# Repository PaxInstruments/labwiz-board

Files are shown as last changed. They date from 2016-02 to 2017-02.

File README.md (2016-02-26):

# Pax Instruments
# armwiz-board

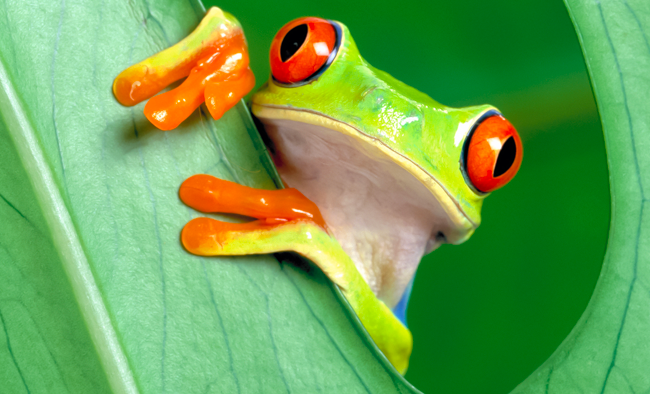
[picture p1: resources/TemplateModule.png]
  
[Pax Instruments Template Module](<link to store page>)

## Overview
The Pax Instruments armwiz board is a development board based on the STM32 series processors specifically targeting the STM32F103RxT series. You can [purchase this item in our store](http://paxinstruments.com/products/).

## Repository Contents
- __Datasheets__ - Datasheets for relevant components and parts
- __Electronics__ - All PCB and schematic design files
- __Enclosure__ - Enclosure 3D design files
- __Firmware__ - Firmware, libraries, and examples
- __Production__ - Manufacturing resources
- __Resources__ - Other resources

## Product Versions

## License Information
```
Place the license statement here
```

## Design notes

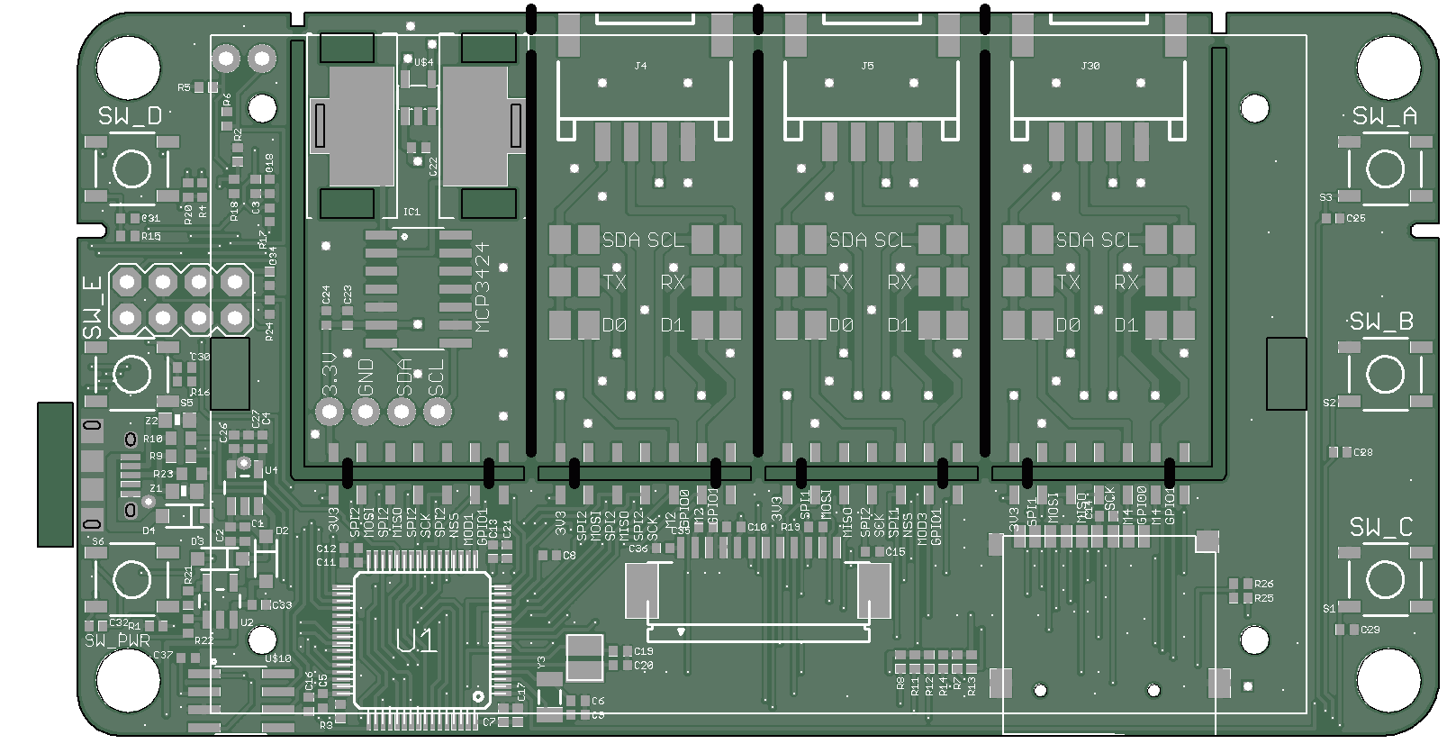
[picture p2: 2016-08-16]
electronics/versions/labwiz-board-0.2/labwiz-0.2_top.png

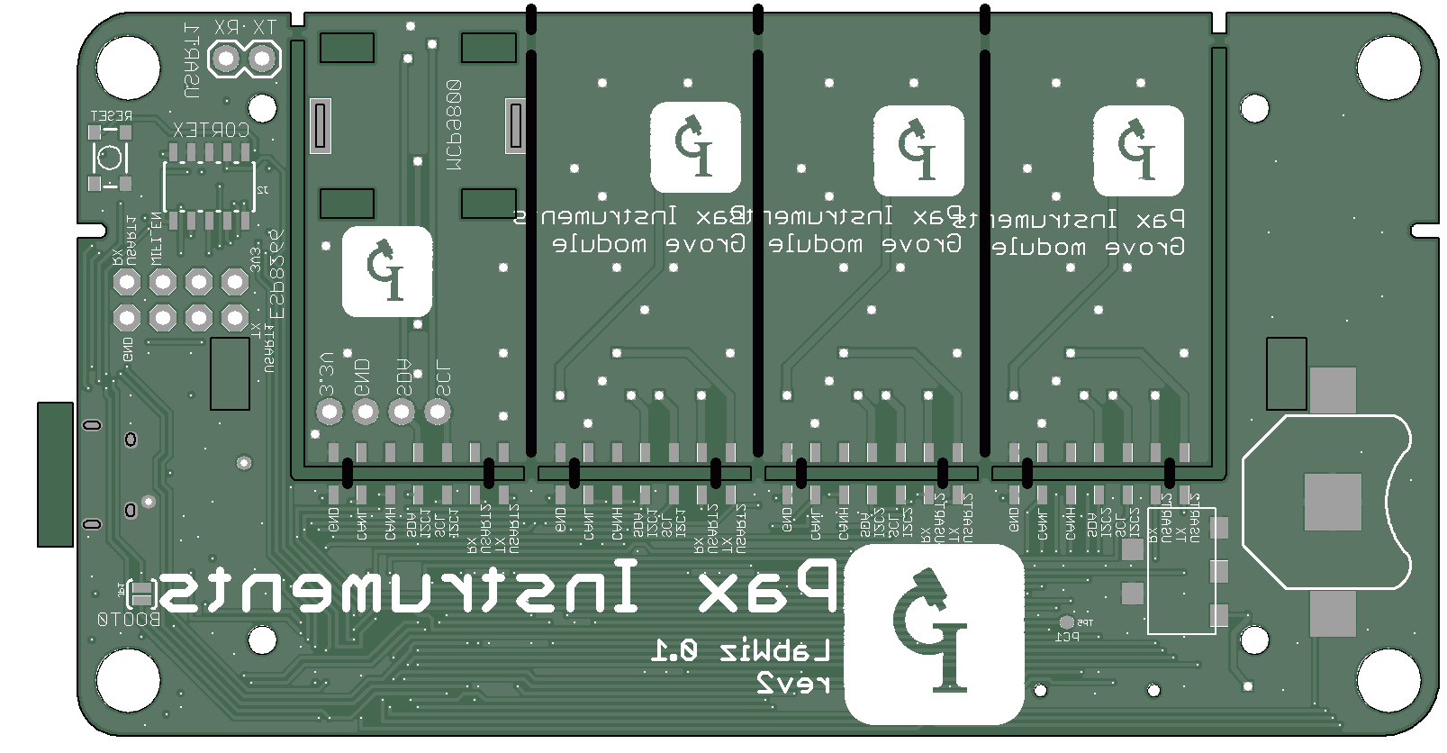
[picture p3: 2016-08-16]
electronics/versions/labwiz-board-0.2/labwiz-0.2_bottom.png

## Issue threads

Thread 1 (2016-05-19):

Voltage regulator

charlespax, 2016-05-19:
Determine which voltage regulator to use. See http://community.paxinstruments.com/t/pax-instruments-multilogger/167

charlespax, 2016-05-19:
The LM317 is suggested.
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

charlespax, 2016-08-08:
Sticking with the MIC5219-3v3

Closed 2016-08-08.

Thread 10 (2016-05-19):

Battery charging

charlespax, 2016-05-19:
Implement a solid battery charging circuit. See http://community.paxinstruments.com/t/pax-instruments-labwiz/167

charlespax, 2016-05-19:
From stmdude:

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

charlespax, 2016-05-19:
I just ripped open a BL-5C battery. Here is the internal protection PCB.
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

It contains two ICs. One is marked DW01 z, which is a battery protection IC from Fortune Semiconductor. It is probably similar to [this one](http://pdf1.alldatasheet.com/datasheet-pdf/view/256691/ETC2/DW01.html). The 8205S is a 8205A dual NFET.
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

What do you think?

charlespax, 2016-05-19:
From stmdude:

> It's a pretty basic (and adequate) protection circuit. One thing you should confirm though (you might have already done it) is to make sure that the MCP73831 actually tries to charge a little bit before trying to do a battery detect (VBAT > 0V). Otherwise, "4. Charge Detection after Overdischarge" won't work. I've been bitten by that one once before. (Not with the MCP chargers though, that was a BQ)
>
> Still, some rudimentary temperature checks would be in order (considering that people might very well put an instrument like this in a temp-chamber)

charlespax, 2016-07-24:
The Adafruit Feather boards could be a nice reference design for our battery charging system. It's fairly similar to the T400 as well. Adafruit has a [series of Feather boards](https://www.adafruit.com/categories?q=adafruit%20feather&) with different microcontrollers and various wireless options.

Below are the power and battery charging circuits for the various boards. Decoupling cap and other bits may be left out.

**Adafruit-Feather-32u4-Basic-Proto-PCB**
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

**Adafruit-Feather-32u4-Bluefruit-LE-PCB**
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

**Adafruit-Feather-32u4-FONA-PCB**
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

**Adafruit-Feather-32u4-RFM-LoRa-PCB**
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

**Adafruit-Feather-ESP8266-HUZZAH-PCB**
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

**Adafruit-Feather-M0-Adalogger-PCB**
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

**Adafruit-Feather-M0-Basic-Proto-PCB**
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

**Adafruit-Feather-M0-Bluefruit-LE-PCB**
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

**Adafruit-Feather-M0-RFM-LoRa-PCB**
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

**Adafruit-Feather-M0-WiFi-WINC1500-PCB**
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

**Adafruit-WICED-WiFi-Feather-PCB**
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

charlespax, 2016-08-08:
Here is the voltage regulator and the battery charging circuit.
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

We still need to implement switching between battery power and USB power https://github.com/PaxInstruments/labwiz-board/issues/37.

Closed 2016-08-08.

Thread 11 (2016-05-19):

Coulomb counter

charlespax, 2016-05-19:
See http://community.paxinstruments.com/t/pax-instruments-multilogger/167

charlespax, 2016-05-19:
From stmdude:

> Columb-counters are sexy beasts, but they're probably a bit overkill in this application. Approximating SoC (State of Charge) from just VBAT is enough, unless you put loads high enough on the battery for the IR to matter. (In that case, you'll get erroneously low readings when the system is under load)

charlespax, 2016-05-19:
We won't need this as long as we measure the battery voltage (#6).

Closed 2016-05-19.

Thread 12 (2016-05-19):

RTC backup power

charlespax, 2016-05-19:
The device has a coin cell battery for RTC backup. Should we use a super cap?

charlespax, 2016-05-19:
The coin cell works. Made a new issue to address the super cap idea #16.

Closed 2016-05-19.

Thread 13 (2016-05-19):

Boot configuration

charlespax, 2016-05-19:
The ARM BOOT0 and BOOT1 pin configuration determines from which memory system the MCU boots.

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

BOOT1 is not typically used and can be accessible via a solder bridge. BOOT0 is used a bit more, but does not need to be readily available. Test pads would be sufficient. There is no need for pin headers for these. BOOT0 should have a pulldown resistor.

charlespax, 2016-05-19:
BOOT1 is on a solder bridge. Boot0 is connected one of two pads that can easily be bridged together. You can see a small milled slot going through two overlapping pads. Tweezers or other metal can be used to bridge across. I haven't tried this before, so we'll see how it goes.
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

Closed 2016-05-19.

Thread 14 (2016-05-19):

Analog reference

charlespax, 2016-05-19:
What should we do with VDDA?

charlespax, 2016-05-19:
We could leave it unconnected, butI have it connected to 3.3V. It can be completely ignored. However, it someone wants to play with using an external analog reference, there is a voltage on that pin.

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

There is a good deal of space in the area near VDDA. We could add a footprint for a precision voltage reference and just leave it unpopulated.
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

electrokean, 2016-09-03:
Adding the ferrite in https://github.com/PaxInstruments/labwiz-board/issues/48 would allow someone to remove that and isolate VDDA to connect in an alternate reference.

charlespax, 2016-09-03:
I like that idea. We should probably have a ferrite bead there anyway. If there's enough room, I can also add the appropriate IC footprints on the backside of the board.

An alternative approach would be to have a voltage reference on a module board. The reference can be measured by one of the GPIO pins (they all are on an ADC) for calibration of the STM32's internal reference.

charlespax, 2016-09-09:
To keep the design simple I will not implement this. To get quality analog readings an external reference can be used to calibrate the STM32 12-bit ADC or a higher quality ADC can be connected through a digital interface. Closing issue.

Closed 2016-09-09.

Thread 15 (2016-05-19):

Internal temperature sensor

charlespax, 2016-05-19:
From the datasheet:

> The temperature sensor has to generate a voltage that varies linearly with temperature. The conversion range is between 2 V < VDDA < 3.6 V. The temperature sensor is internally connected to the ADC1_IN16 input channel which is used to convert the sensor output voltage into a digital value.

This looks like an internal connection rather than being shared with an external pin. Other than maybe having a good [external analog reference](https://github.com/PaxInstruments/armwiz-board/issues/14) there doesn't seem to be any special hardware needs to implement this.

Closed 2016-05-19.

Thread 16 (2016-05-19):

RTC super capacitor backup

charlespax, 2016-05-19:
Maybe use a super capacitor.

Things to consider
- super caps are probably more expensive components
- The coin cell battery is lithium, which comes with various shipping challenges
- Would a super cap solution have a smaller footprint?

charlespax, 2016-08-23:
Here is a super capacitor calculator: https://www.maximintegrated.com/en/design/tools/calculators/product-design/supercap.cfm

Seeed has a module, but I can't find the schematic. http://www.seeedstudio.com/depot/RTC-Module-Super-Capacitor-p-2137.html

Topic on Stack Exchange. http://electronics.stackexchange.com/questions/26855/supercap-powered-rtc

What is the minimum voltage for the STM32 battery backup?

charlespax, 2017-01-26:
I'm going to ice box this. Maybe come back to it later.

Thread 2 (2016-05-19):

MicroSD card inductor

charlespax, 2016-05-19:
Do we need an inductor on the MicroSD card? Probably not. See http://community.paxinstruments.com/t/pax-instruments-multilogger/167

charlespax, 2016-05-19:
From stmdude:

> Have you had any reports on the T400 about SD-cards being unstable when writing to them? As in, system resets or corrupted data/readings ?
> If not, I'd probably leave it out.

charlespax, 2016-05-19:
I have not heard anything from anyone, but I've only ever used the SPI interface. Maybe there will be a problem if while accessing the SD card via the SDIO interface. Let's revisit this if it comes up. Closing issue.

Closed 2016-05-19.

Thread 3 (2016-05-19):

MEMS oscillator

charlespax, 2016-05-19:
I put a 16 MHz MEMS oscillator on the board instead of a crystal. This is a much smaller package. Confirm it is connected properly. See http://community.paxinstruments.com/t/pax-instruments-multilogger/167
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
Confirm the MEMS oscillator is connected correctly. Output is enabled when TRI is HIGH or high impedance.

What does the MCU OSC_OUT actually do?

charlespax, 2016-05-19:
From the STM3F103 [reference manual](http://www.st.com/resource/en/reference_manual/cd00171190.pdf):
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

Closed 2016-05-19.

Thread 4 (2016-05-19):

Should we have a 100R resistor in series with SWO?

charlespax, 2016-05-19:
See http://community.paxinstruments.com/t/pax-instruments-multilogger/167

charlespax, 2016-05-19:
From stmdude:

> Unless you're planning to add another SWD JTAG device on the board, there's no need to even route SWO. SWO is an output, so you can daisy-chain several SWD devices together, so you can use one JTAG to debug several chips in a system at once.

charlespax, 2016-05-19:
I thought SWO was for doing trace, so the processor can be observed while the system is running. Check out this video https://www.youtube.com/watch?v=XGmSCVgb6EM.

charlespax, 2016-05-19:
I believe SWO is also for doing trace, so the processor can be observed while the system is running. Check out this video https://www.youtube.com/watch?v=XGmSCVgb6EM.

It's already routed and I'd like to try out trace some time, so I'll leave SWO connected. Should I keep the 100R resistor?

charlespax, 2016-05-19:
I'll say yes. Closing issue.

Closed 2016-05-19.

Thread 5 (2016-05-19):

Should we have a capacitor on nRST?

charlespax, 2016-05-19:
Should we have a capacitor on nRST?
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
See http://community.paxinstruments.com/t/pax-instruments-multilogger/167

charlespax, 2016-05-19:
From stmdude:

> Yes. Very much so. The STM32 series needs an external cap on nRST, or you can get spurious resets.

charlespax, 2016-05-19:
Cool. Keeping it in. Closing issue.

Closed 2016-05-19.

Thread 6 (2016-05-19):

Measure battery voltage

charlespax, 2016-05-19:
Add voltage-divider from VBAT into one of the ADC inputs, so we can measure the battery voltage at least. Maybe a little FET as well, so we can disconnect the divider (as it will leak otherwise). See http://community.paxinstruments.com/t/pax-instruments-multilogger/167

charlespax, 2016-05-19:
I've added a voltage divider with two 10k resistors. This bad and dirty just to have the ability to measure the battery voltage. We should revisit this when we implement battery charging #10. Moving the proper implementation of this issue to the next milestone.

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

charlespax, 2016-07-14:
Closing issue. We can open a new issues if it comes up upon implementing battery charging.

charlespax, 2016-09-13:
Here is the current circuit. JeeLabs had some good information about adding the capacitor to reduce noise and allow the highest value resistors to be used.

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

I still need to select the best resistor values.

charlespax, 2017-02-02:
Using a fuel gauge. Done.

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

Closed 2017-02-02.

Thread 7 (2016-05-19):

VBUS_DETECT

charlespax, 2016-05-19:
Add a VBUS_DETECT pin, if for nothing else, power-management (so we know when we can power-down the USB peripheral in the STM32). A voltage-divider (15K/22K split) from VBUS to a GPIO should do fine for that. See http://community.paxinstruments.com/t/pax-instruments-multilogger/167

charlespax, 2016-05-19:
Connected VBUS to PB11, which is a 5V tolerant pin. No need for a voltage divider.
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

Closed 2016-05-19.

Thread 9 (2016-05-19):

USB connection

charlespax, 2016-05-19:
Properly connect the MCU to USB. Refer to https://www.olimex.com/Products/Duino/STM32/OLIMEXINO-STM32/resources/OLIMEXINO-STM32_Rev.A-schematic.pdf. See http://community.paxinstruments.com/t/pax-instruments-multilogger/167

charlespax, 2016-08-15:
We have successfully communicated over USB full speed. Closing issue.

Closed 2016-08-15.

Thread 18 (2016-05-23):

MicroUSB 4-layer error

charlespax, 2016-05-23:
The MicroUSB connector footprint is not 4-layer friendly. The milled holes for the legs are on the pads, which means they will be plated. The power layer is not pulled away from the milled holes. This, unfortunately, will result in the shorting of 3.3V and GND. When version 0.1.1 boards come in this area must be modified to correct this.
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

Make or find a footprint what will work with four layers.

electrokean, 2016-05-23:
Ouch!  I'm glad I've been using drills for these mounting pins, even if soldering of them isn't quite as nice.

charlespax, 2016-07-14:
I've added a feature to the PCB design to pull away the internal 3.3V layer. It would be nice to have this in the actual USB part, but Eagle seems to not have that ability.
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

Closed 2016-07-14.

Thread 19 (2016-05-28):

Module connector

charlespax, 2016-05-28:
I put half-hole edges on the first prototype. The PCB house charges extra for this feature. If we used this as the module connection method, modules would be more costly and possibly take longer to make as not all board houses will do it.

I would like to use some sort of connector solution. A 2.0 mm header straddles the 1.6 mm PCB perfectly. A male header can be soldered onto the main PCB and to the module PCB. A male/female header pair can be used to make a reusable connection.

Male headers on the top panel can be used to support the top end of the module PCB.

charlespax, 2016-08-08:
We are going with 2x7 2.0 mm female headers straddle-mounted on the main board. There are locating nubs too. I think I can get connectors made with the nubs.
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

Closed 2016-08-08.

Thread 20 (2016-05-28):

Resistor packs

charlespax, 2016-05-28:
It would be nice to replace some of the resistors with resistor packs if possible.

charlespax, 2016-08-15:
The only spot where it makes sense is next to the SD card where we have six 10k resistors. Not worth introducing another component into the BoM.
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

Closed 2016-08-15.

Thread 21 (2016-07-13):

ESP8266 integration

charlespax, 2016-07-13:
It looks like there's plenty of room for an ESP8266 layout. The screenshot below shows the footprint of one of the modules (U$10). It would be great if we can fit a module footprint. Then it could be soldered in as an option.
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

charlespax, 2016-07-14:
Module footprint added.

Closed 2016-07-14.

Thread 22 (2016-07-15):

Boot configuration buttons

charlespax, 2016-07-15:
I've changed the boot configuration control from [solder pads](https://github.com/PaxInstruments/armwiz-board/issues/13) to buttons. The boot config pins are connected to buttons D and E.

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

The SW_D is connected to BOOT0 with a default state of LOW and SW_E is connected to BOOT1 with a default state of HIGH. The default boot mode is Main Flash Memory. Pressing SW_D will boot into Embedded SRAM. Pressing SW_D and SW_E will boot into System Memory (ST bootloader).
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

I'm concerned what happens when a user unintentionally presses one of the buttons while powering on the device. What will the user experience when booting into SRAM? What will the user experience when booting into System Memory?

Here are other relevant parts of the schematic.
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

charlespax, 2016-08-08:
I've added a solder jumper for development. In production the solder jumper would be unsoldered.

With an open jumper BOOT0 is always LOW. System always boots from Main Flash Memory. With a closed jumper the user is able to use buttons D and E to configure which memory to use.

Closed 2016-08-08.

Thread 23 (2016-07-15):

Cortex debug header resistors

charlespax, 2016-07-15:
The board has a Cortex debug header. There are several resistors connected to this circuit. Do we need these? Are they the right values?

Also, I've placed USART1 RX and TX on two of the unused pins.

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

The Olimecino board does not have these resistors.
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

electrokean, 2016-07-15:
SWDIO actually has an internal pull-up, and SWDIO a pull-down per the STM32F103 reference manual, so I don't think these external bias resistors are mandatory.  It also states that the JTAG spec recommends the appropriate pull-up/downs, but the embedded ones remove that requirement (see 31.4.3).
Interestingly, 31.8.1 says a 100k pull-up  on SWDIO is recommended by ARM, but again probably non necessary as the STM32F103 includes these.
The series resistors are probably included on some designs in case the SWJ pins are reconfigured (via SWJ_CFG bits) to GPIOs by the application code while still connected to a programmer.

charlespax, 2016-08-08:
I'll leave the resistors in for now and ice box this issue. I'll look into it more to confirm we can remove them.

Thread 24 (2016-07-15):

SD card resistors and inductor

charlespax, 2016-07-15:
Are the resistors on the SD card the correct values? We use 10k resistors.
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

The Olimexino board uses 100k resistors. They also use an inductor. Should we have an inductor?
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

electrokean, 2016-07-15:
The SD card physical layer specification doesn't seem to require any pull-ups, but they're clearly a good idea to avoid floating inputs on the STM32.  I've used the Olimexino resistor configuration on my some of own designs without issue.  Interestingly I just realised I think I left them off on a recent prototype based on the STM32F103, and didn't notice any issue.
The inductor on the SD card power supply and bulk capacitance is a good idea to reduce fluctuations on the 3.3V rail during SD card operations, which can draw surges of current for short periods (write or erase).  This provides filtering for the upstream 3.3V (e.g. ADC reference) as much as for the SD card itself.
An 0805 ferrite and lower value capacitor may be OK when there is a sufficiently low impedance path from the power source, but could introduce problems when the battery is getting low, or device is powered off USB without a battery inserted, leading to data corruption or even card failure.

charlespax, 2016-08-23:
From http://www.mikrocontroller.net/attachment/21920/SDHC_SDM04G7B7_08G7B7.pdf:
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

From https://www.kingston.com/datasheets/SDCIT-specsheet-64gb_us.pdf:
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

From http://www.nxp.com/documents/application_note/AN10911.pdf:
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

From http://downloads.amilda.org/MODs/SDCard/SD.pdf:
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

From http://www.digitalspirit.org/file/index.php/obj-download/docs/sd/SdCard-MMC-Controller_From_Intel.pdf:
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

From https://www.renesas.com/en-in/products/software-tools/software-os-middleware-driver/dsp-numerical-software/wireless-lan--rtk5563000f00000sr.html:
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

From http://www.analog.com/media/en/technical-documentation/application-notes/EE335_rev1.pdf:
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

From http://learn.parallax.com/tutorials/language/spin/propeller-board-education-project-builders/sd-card-data-storage:
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

From http://www.lydiard.plus.com/hardware_pages/sd_card.htm:
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

From http://justanotherlanguage.org/content/tutorial_sd_card:
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

See also

- http://electronics.stackexchange.com/questions/83263/micro-sd-card-power-circuit-failure

charlespax, 2016-09-09:
Here is another reference design (http://electronics.stackexchange.com/questions/83263/micro-sd-card-power-circuit-failure).
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

Since things are working now I'm not going to implement this in revision 0.3, but will in a future rev.

charlespax, 2017-01-28:
I've added 10k pullups to the CMD and data lines. Caps don't seem to be very popular, so I'll just skip those.
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

Closed 2017-01-28.

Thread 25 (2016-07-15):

Reset button

charlespax, 2016-07-15:
STM32 NRST is connected to NRESET on the Cortex debug header, but that's all. Should the board have a reset button?

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

charlespax, 2016-08-08:
I've added a pullup to the reset line. Added reset switch.
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

Closed 2016-08-08.

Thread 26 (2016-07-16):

Serial port connections

charlespax, 2016-07-16:
Do we need pullup resistors on the serial lines? Possibly so for the bootloader. See [AN2606 p. 26](http://www.st.com/content/ccc/resource/technical/document/application_note/b9/9b/16/3a/12/1e/40/0c/CD00167594.pdf/files/CD00167594.pdf/jcr:content/translations/en.CD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).
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

electrokean, 2016-07-16:
Always want one on the Rx pin at each device that may have its input disconnected from the transmitter

charlespax, 2016-08-08:
Done

charlespax, 2017-01-23:
The resistors were removed at some point. I'm adding them again.
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

charlespax, 2017-01-23:
Added back on the board.

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

Closed 2017-01-23.

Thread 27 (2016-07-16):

USB connection for bootloader

charlespax, 2016-07-16:
What do we need for enabling the bootloader to flash over USB? See [AN2606 p. 26](http://www.st.com/content/ccc/resource/technical/document/application_note/b9/9b/16/3a/12/1e/40/0c/CD00167594.pdf/files/CD00167594.pdf/jcr:content/translations/en.CD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).
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

electrokean, 2016-07-16:
STM32F103 doesn't have built in USB DFU bootloader, so it would be dependant on a separate bootloader like https://github.com/rogerclarkmelbourne/STM32duino-bootloader
See the notes there in README.md as there are a few implementation options for the disconnect feature

charlespax, 2016-08-08:
Moved to firmware repo.

electrokean, 2017-01-23:
For the more modern chips with USB DFU, you should just need a way to control BOOT0 (and possibly RESET) to start the bootloader.

If you have a spare I/O pin, you can do a nifty firmware trick by connecting that to BOOT0 along with a small capacitor.  To enter the bootloader, the firmware pulls the I/O pin high to charge the cap, and then does a reset while the cap holds BOOT0 high (slowly discharging through a pulldown).

Ref: http://stackoverflow.com/questions/26891432/jump-to-bootloader-in-stm32-through-appliction-i-e-using-boot-0-and-boot-1-pins

charlespax, 2017-01-23:
PC1 is currently not used and is a good candidate. It could easily be routed over.
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

I think this circuit would work. I would just connect PC1 to BOOT0 and add a cap across the 10k pulldown resistor. Not sure what value.
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

I would have to change the BOOT1 circuit. Right now it's normally high, which would make the device boot from SRAM. Making BOOT1 normally low would have the system default to system memory (hardware bootloader) if BOOT0 is high.
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

charlespax, 2017-01-23:
Since at lease some chips require a 1.5k pullup on USB_DP, we should implement the circuit. Here is an except from [AN2606](http://www.st.com/content/ccc/resource/technical/document/application_note/b9/9b/16/3a/12/1e/40/0c/CD00167594.pdf/files/CD00167594.pdf/jcr:content/translations/en.CD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)
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

charlespax, 2017-01-23:
Actually, the board already has the 1.5K pullup. I think the pullup is to indicate to the host if the device is full-speed or high-speed (see also #55 ).
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

charlespax, 2017-01-23:
Yes, the 1.5k pullup on DP is to indicate full-speed. It is also the same circuit to indicate high-speed.

Change made to the BOOT1 switch.
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

PC1 connected to BOOT0.
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

Capacitor added in parallel with the BOOT0 pulldown.
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

charlespax, 2017-01-23:
Done. Closing issue.

Closed 2017-01-23.

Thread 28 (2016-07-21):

Module power connection

charlespax, 2016-07-21:
The module connector has a single 3.3V pin and a single GND pin. Do we need to have more than one pin? How much current can these contacts handle?

We can add a solder pads to the left and right edges of the main PCB to connect higher current 3.3V and GND to be jumped across with wire. This could be useful for larger modules. However, a larger module what fills the entire four module area would have four 3.3V and four GND connections.

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

charlespax, 2016-08-08:
[3M 0.1" headers](http://www.digikey.com/en/product-highlight/3/3m/tenth-inch-headers) have a current rating of 5 amps. For our header I think we'll be good.

Closed 2016-08-08.

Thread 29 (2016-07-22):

Main board as peripheral

charlespax, 2016-07-22:
It would be pretty cool if a person could use their favorite microcontroller on a module board and use the main board merely to interface with the buttons, LCD, etc..

**Buttons**
The STM32 monitors the buttons. When a button is pressed the STM32 generates an interrupt output to the module. The module can poll the STM32 for button status.

**Other peripherals**
We can probably have the STM32 simple echo byte-for-byte all the communication between the module microcontroller and the peripheral. The STM32 would simple act as a conduit.

charlespax, 2016-08-08:
Moved to firmware repo

Closed 2016-08-08.

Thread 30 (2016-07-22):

Project name

charlespax, 2016-07-22:
The name "armwiz-board" is just a placeholder while I come up with a good project name.

**Criteria**

- Name does not use technology-specific language. "ARM Logger" and "STM32Pro" are both bad because they use trademarked terms and because they are technology specific. The name wouldn't make sense for a PIC version.
- Name is Googleable. Use a name where we can quickly be the top hit on Google.
- Name can be spelled without explanation. "Lab Bud-e" is much worse than "Lab Buddy" because you have to explain the spelling.
- Name does not refer to an arbitrary property. "BlueLab" and "SquareSense" are bad because they tie us to making blue enclosures or square enclosures.

**Inspiration**

- The system is modular and has a main board: Space station, interchangeable, adaptive, flexible, custom, bespoke, base, mod
- The device is portable and hand-held: hand, handy, handi, pocket, palm
- Used in a laboratory: lab, lab-oratory, bench, engineer, science,
- Small device: small, little, tiny, milli, micro, nano, pico, sub-,
- Good quality: rugged, reliable, dependable, sturdy

**Options**

- **Pax Instruments LabWiz**
- Pax Instruments PaxLab
- Pax Instruments ModLogger
- Pax Instruments ezLab
- Pax Instruments Nulabra
- Pax Instruments LabKick (like sidekick :-/ )
- Pax Instruments Unimeter (FAIL, [it's taken](http://www.unimeter.com/))
- Pax Instruments Omnimeter (FAIL, [it's taken](http://www.ekmmetering.com/omnimeter))
- Pax Instruments Minimeter
- Pax Instruments LabGenius
- Pax Instruments LabGini

charlespax, 2016-07-22:
It looks like "Pax Instruments LabWiz" is the winner. It's short, Googleable (2,530 results), and meets the other criteria.

Closed 2016-08-08.

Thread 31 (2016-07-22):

Oscillator component choice

charlespax, 2016-07-22:
In the design I've made the assumption that the main oscillator and the RTC oscillator are available in the same footprint. I have to verify this or possibly change to parts that actually exist and are available.

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

electrokean, 2016-07-22:
Yeah, this is probably not the case.
The RTC crystal specs can be quite particular around capacitance and ESR.
Check out AN2867 - it has lots of info plus lists of some suggested parts, and it will also point out some potential issues with your layout around that area.
Finding parts that meets your price/footprint/availability requirements can be a bit of a challenge.

charlespax, 2016-08-08:
It looks like small 8 MHz crystals are pretty easy and cheap to get. A small 16 MHz device would have to be a more expensive and rare MEMS device. We'll go with 8 MHz.

Here is a commonly available component from the HQB market. When buying twenty pieces I paid 2 RMB each.
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

charlespax, 2016-08-08:
Here is the new crystal on the PCB. 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

Closed 2016-08-08.

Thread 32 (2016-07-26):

WiFi/Bluetooth

charlespax, 2016-07-26:
Consider the [ESP32](http://espressif.com/en/products/hardware/esp32/overview) to replace the ESP8266. The ESP32 has both WiFi and Bluetooth

charlespax, 2017-01-24:
Vendors and other resources: http://esp32.net/

charlespax, 2017-01-27:
I haven't seen any modules that fit on the board. An ESP8266 WiFi module fits (#132), so we should go with that.

Closed 2017-01-27.

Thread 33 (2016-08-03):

Screwy boards

charlespax, 2016-08-03:
The v0.1.1 board we have keep dying. I think it's some kind of configuration problem. It could also be something related to the boot mode pins. The ST-Link v2 debuggers are not able to connect to a board some time after being flashed.

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

Version 0.1.1 has SWO on PA15 when it should be on PB3 (SCK3 is on PB3).

charlespax, 2016-08-03:
The board is missing a [pullup resistor on RESET](https://github.com/PaxInstruments/labwiz-board/issues/34). I added a 10k pullup and the board still did not work.

charlespax, 2016-08-03:
Are we writing to the correct memory locations? Maybe we're using the locations for a different device and we're stomping on settings or something. Here is the memory layout in `mem.ld`

```
MEMORY
{
  RAM (xrw) : ORIGIN = 0x20000000, LENGTH = 20K
  CCMRAM (xrw) : ORIGIN = 0x00000000, LENGTH = 0
  FLASH (rx) : ORIGIN = 0x08000000, LENGTH = 64K
  FLASHB1 (rx) : ORIGIN = 0x00000000, LENGTH = 0
  EXTMEMB0 (rx) : ORIGIN = 0x00000000, LENGTH = 0
  EXTMEMB1 (rx) : ORIGIN = 0x00000000, LENGTH = 0
  EXTMEMB2 (rx) : ORIGIN = 0x00000000, LENGTH = 0
  EXTMEMB3 (rx) : ORIGIN = 0x00000000, LENGTH = 0
  MEMORY_ARRAY (xrw)  : ORIGIN = 0x00000000, LENGTH = 0
}
```

electrokean, 2016-08-03:
You had a pullup on BOOT1 [here](https://github.com/PaxInstruments/labwiz-board/issues/22#issue-165717313) but I think it should be a pull down for normal (i.e. flash) operation.
Not that that should stop the ST-Link from detecting the chip - but the missing reset pullup may have.
Is the ST-Link working now, but code not running?  That could be BOOT1.

charlespax, 2016-08-03:
We're working with v0.1.1 boards right now, which have BOOT1 floating and BOOT0 toe to GND through a 10k resistor.

My understanding of the table below is that the device will boot into Main Flash Memory if BOOT0 is tied to GND, regardless of the status of BOOT1. Then if BOOT0 were high, BOOT1 would select between System Memory and Embedded SRAM.
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]

The ST-Link programmers have no problem connecting to another development board we have (same chip family). I can connect just fine with fresh chips, but not after flashing them.

I'll go back an try some previous firmware and see if the same thing happens. If other code does not brick the boards, we'll have a good start to figuring out what specific software component (if any) is causing the problem.

charlespax, 2016-08-03:
Other possibilities:

- The killer firmware is turning on a bunch of peripherals, which requires more power than the system can provide. The board is in a constant brownout state.
- The two chips are in the same family. One is medium density while the other is extra high density. Maybe there is something wrong with the config. Maybe the configuration registers are not the same.
- The configuration is disabling the SWD interface or remapping pins.

electrokean, 2016-08-03:
OK, yeah I guess that is right - but I certainly wouldn't leave the pin floating.  It is "don't care" when BOOT0 is pulled down, but it is still a CMOS input and can have problems if floating.

Here are some links to other similar reports & solutions that may help:
http://electronics.stackexchange.com/questions/84921/is-it-normal-to-brick-the-stm32f0-with-certain-software-pin-configurations
http://electronics.stackexchange.com/questions/204996/stm32-st-link-cannot-connect-to-mcu-after-sucessful-programming

charlespax, 2016-08-08:
Problem solved. It was the CAN bus stomping on another configuration.

Closed 2016-08-08.

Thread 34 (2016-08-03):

RESET pullup resistor

charlespax, 2016-08-03:
I believe we should have a 10k pullup on the reset line.

charlespax, 2016-08-08:
done.

Closed 2016-08-08.

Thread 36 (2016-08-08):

Button debounce

charlespax, 2016-08-08:
We should debounce the buttons in hardware, so we don't have to deal with software debouncing. Use the calculator at http://protological.com/debounce-calaculator/. Read [this write up](http://protological.com/debounce-switched-with-simple-components/) for more information.
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

charlespax, 2016-08-15:
Done.
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

Closed 2016-08-15.

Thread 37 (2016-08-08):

Battery/USB power switching

charlespax, 2016-08-08:
We need to implement an automatic way of switching between USB power and battery power. See the T400 schematic for reference.

charlespax, 2016-08-08:
I tossed in a diode the same as on the Adafruit Feather board. There's a bunch of screen shots in https://github.com/PaxInstruments/labwiz-board/issues/10.
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

There is probably a better way, but it's fine for this hardware revision. We'll improve in the next milestone.

For reference, here is the relevant T400 circuit section.
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

charlespax, 2016-08-15:
We'll circle back to this if there is an issue in the next hardware revision.

Closed 2016-08-15.

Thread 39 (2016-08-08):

Purpose of VBUS input

charlespax, 2016-08-08:
We have VBUS input on PA9, but I'm not sure why. We're pretty strapped for pins, so it would be nice to know if we can repurpose this pin. What is the use case here?
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

electrokean, 2016-08-11:
I'm guessing this is useful for knowing when a USB cable is plugged in - either for mcu based battery charger control or to begin USB enumeration.  Most pins are 5V tolerant, but I still tend to include a resistive divider myself...

charlespax, 2016-08-15:
The USB data lines handle enumeration. I've removed and repurposed the VBUS line as the VBAT_DIV2 battery voltage input.

Closed 2016-08-15.

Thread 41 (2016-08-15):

ESP8266 connections

charlespax, 2016-08-15:
A header is on the board for an ESP8266 module, which runs on USART1. I need to review and implement any necessary pullups/pulldowns and any other components necessary.
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

charlespax, 2016-08-15:
I dropped a 10 uF cap on the power lines. Everything else seems to be in order.
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

charlespax, 2016-08-15:
Done. Looks good.

charlespax, 2016-09-11:
WIFI now has a dedicated USART. Review connections again.

samchoy88, 2016-12-10:
Using USART3 right now
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

Closed 2016-12-11.

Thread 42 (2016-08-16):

Power output

charlespax, 2016-08-16:
I want the board to be able to output as much power as possible. I may need to select another 3.3V regulator.

- What can we draw from the battery?
- What can the 3.3V regulator output?

electrokean, 2016-09-03:
If you gave up one of the ground pins on the modules, you could route VBAT or VBUS to them.

Or just allow for a pad on one of these for people wanting to hack to easily wire a jumper across to a module.

charlespax, 2016-09-03:
It turns out the CAN and USB use the same memory and cannot be used together. Thus, I'm dropping CAN from the interface. Not a big deal. This frees up two pins. The fourteen pin connector will have the following pins.

- 3V3
- 3V3
- VBUS
- GND
- GND
- SPI_MISO
- SPI_MOSI
- SPI_SCK
- GPIO1
- GPIO2
- USART_RX
- USART_TX
- I2C_SD
- I2C_SCL

With the addition of VBUS to the module a design could draw directly from USB power or from the battery. Anything beyond that and a design could have an independent power input.

charlespax, 2016-09-09:
Each connector has a pin for VBUS. Closing issue.

Closed 2016-09-09.

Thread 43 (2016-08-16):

Silkscreen error

charlespax, 2016-08-16:
Check the silkscreen on the module connectors on the main board. I think I put "I2C!" instead of "I2C1".

charlespax, 2016-08-20:
Done.

Closed 2016-08-20.

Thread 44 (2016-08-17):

Module area width

charlespax, 2016-08-17:
Each module is 16 mm wide. The module area needs to come in by 1mm on each side. It's a bit too wide right now.

charlespax, 2016-08-20:
Done.

Closed 2016-08-20.

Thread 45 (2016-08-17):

4.7 uF cap

charlespax, 2016-08-17:
The stm32f103 datasheet indicates Vdd3 needs a 4.7 uF cap.
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

charlespax, 2016-08-20:
I've added the 4.7 uF cap.
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

It also looks like I can remove all the 10 uF caps and change the VDDA cap from on 100 nF to one 10 nF cap and one 1 uF cap.
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

charlespax, 2016-08-22:
Removed 10uF caps on VDD pins. Changed VDDA caps.
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

electrokean, 2016-08-22:
Maybe add a small ferrite bead or low value resistor between VDD and VDDA to filter noise from CPU core?

charlespax, 2016-08-23:
Good call. I've opened an issue. https://github.com/PaxInstruments/labwiz-board/issues/48

Closed 2016-08-22.

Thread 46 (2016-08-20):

FreeRTOS 9

charlespax, 2016-08-20:
The firmware is using FreeRTOS V8.2.3, but the current version is 9.0.0. We should probably upgrade.

charlespax, 2016-08-20:
Moved to firmware issues. https://github.com/PaxInstruments/PaxInstruments-LabWiz-firmware/issues/16

Closed 2016-08-20.

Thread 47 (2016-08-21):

i2c pullups

charlespax, 2016-08-21:
Should we put i2c pullups on the main board or leave that up to the modules? I think we should have 1.5k pullups on the main board.

charlespax, 2016-08-22:
Added to the schematic. Will have to route, but can close issue now.
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

Closed 2016-08-22.

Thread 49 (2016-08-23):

Buzzer

charlespax, 2016-08-23:
Consider adding a buzzer to the board.

charlespax, 2016-09-05:
Not essential. Can be placed on a module if required by an application. PB0 and PB1 are module GPIO pins capable of outputting a PWM signal.

Closed 2016-09-05.

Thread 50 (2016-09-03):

STM32 LQFP64 compatability

charlespax, 2016-09-03:
One of the nicest aspects of the STM32 family is that the chips are very compatible. If we carefully select the peripheral pin mapping, switching between chips will be relatively trivial.

Here is how pins are mapped in LabWiz v0.2.
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

If we change to this pin map, we can swap out the stm32f103rgt (1024k flash, 96k RAM) with the stm32f412rgt (1024k flash,256k RAM).
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

Here is the stm32f412.
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

The downside of implementing this configuration is that we lose a bit of interface flexibility with the modules. The LabWiz v0.2 design gives two USART, two SPI, and two i2c. The compatibility configuration would give two USART, two SPI, and one i2c. Since i2c is a multi-device bus, this isn't much of an issue.

charlespax, 2016-09-03:
Here's what I have right now. The unassigned pins would be for the six GPIO pins for the modules. The two SPI_NSS pins plus the six GPIO are the eight GPIO pins required by the interface.

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

PA10 is unused in this design and is reserved and would be used for USB_OTG if the stm32f412 were used. PB11 is also not used. The stm32f412 uses this pin for a power capacitor. That is also what compelled the decision or use only a single I2C interface.

electrokean, 2016-09-03:
Out of interest, what did you use to generate those pinout images?

charlespax, 2016-09-03:
I used [STM32CubeMX](http://www.st.com/content/st_com/en/products/development-tools/software-development-tools/stm32-software-development-tools/stm32-configurators-and-code-generators/st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) from ST. It's a super flipping awesome GUI for defining all the pins and peripherals.

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

It will help define all the timing.
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

Then it will generate all the startup code in a project. It supports several IDEs. We've been using a secondary Python script to translate from SW4STM32 to and Eclipse project.
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

electrokean, 2016-09-03:
Thanks @charlespax. I suspected it was from STMCube.  I played with an older version, but only briefly.  I have been writing my own startup code so far.  Will have to try this latest version out, especially with PCBs for a new design about to land.

charlespax, 2016-09-05:
Given the following criteria,

- STM32 family
- LQFP64 package
- Have USB capability
- Have SDIO interface

The following twenty-seven parts are potentially compatible.

- STM32F103RC
- STM32F103RD
- STM32F103RE
- STM32F103RF
- STM32F103RG
- STM32F205RB
- STM32F205RC
- STM32F205RE
- STM32F205RF
- STM32F205RG
- STM32F215RE
- STM32F215RG
- STM32F401RB
- STM32F401RC
- STM32F401RD
- STM32F401RE
- STM32F405RG
- STM32F411RC
- STM32F411RE
- STM32F412RE
- STM32F412RG
- STM32F415RG
- STM32F446RC
- STM32F446RE
- STM32L151RD
- STM32L152RD
- STM32L162RD

There are a few down sides with taking SDIO as a criteria. The chip with the lowest amount of flash has 128k flash, 64k RAM. That's fine for development, but limits the options for reducing cost in a final product. However, if we were to use a SPI interface instead, we will be compatible with sixty chips. We'd would then only have one SPI interface for all four modules. Not a good trade off.

charlespax, 2016-09-05:
Here's where I am.

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

All module GPIO pins are capable of GPIO, external interrupt, and 12-bit ADC measurements. Additional features are carried on the pins as listed below.

- MOD1_GPIO1 SPI1_NSS, DAC_OUT1
- MOD1_GPIO2 PWM
- MOD2_GPIO1 GPIO PWM
- MOD3_GPIO1 SPI2_NSS

charlespax, 2016-09-09:
I've routed a new board revision. Closing this issue.

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

Closed 2016-09-09.

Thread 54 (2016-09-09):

Diodes

charlespax, 2016-09-09:
**Battery power diode**
There is a diode to prevent the battery from charging directly from VBUS. This should be a Schottky. Minimize voltage drop and power loss.
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

**Battery voltage diode**
I've added a diode in series with the battery for voltage measurement. The idea is that the diode will drop the voltage into the measurable range. I think this is better than a voltage divider.
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

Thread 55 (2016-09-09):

USB Full-Speed and High-Speed

charlespax, 2016-09-09:
The stm32f103 is a full speed USB device. LabWiz is compatible with several microcontrollers that have high speed capability. Can we use an unused GPIO pin to to configure any necessary pullup/down resistors we need?

charlespax, 2017-01-24:
I believe all devices can operate in at least high-speed USB mode (1.5k pullup on DP) and also have the option of operating in low-speed USB mode. To operate in low-Speed USB mode the board would need a 1.5k pullup on DM.

I don't really see a use case for low-speed mode, so I'm reluctant to implement any implementation that uses a pin on the microcontroller. Adding a solder jumper to the back side of the board should be fine. The user would have to cut a trace and solder a jumper. Seems reasonable for a prototyping platform. It wouldn't add any cost.

charlespax, 2017-01-24:
I've added the jumper.
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

Closed 2017-01-24.

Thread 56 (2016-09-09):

Extra pin usage

charlespax, 2016-09-09:
We have two pins (PC1, PC4) available that are currently broken out to test pads. What can we do with them? Each is connected to a 12-bit ADC.
- SD_DETECT
- SD_ENABLE to cut power to SD and reset the card
- Add a two pin header near the modules. A wire jumper could be used to rout them to a module.
- May be needed for the ESP8266 board.
- Connect to LEDs
- Buzzer
- Use a voltage divider to measure battery voltage with one of the free pins for the low voltage side. This would be to cut off current while not measuring.
- VBUS_DETECT
- May be needed as we improve the circuit

charlespax, 2017-01-28:
PC4 is now used for VBUS_DETECT. PC1 is PC1_BOOT0, which I think can serve as double duty for something like SD_DETECT.

charlespax, 2017-01-28:
Closing issue

Closed 2017-01-28.

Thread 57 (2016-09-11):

MCP73831 PROG resistor

charlespax, 2016-09-11:
Check the PROG resistor on the battery charger. Make sure the value defines the correct charge rate.

samchoy88, 2016-12-10:
Since we face the same issue in T400 circuit design.
https://github.com/PaxInstruments/t400-electronics/issues/163

We should follow the T400 electronic design and use 2.32K (1%) in here
With a 2.32K resistor the typical charge current would be 1000 / 2.32 = 431mA
The highest and lowest possible charge currents, using 10% for the chip and 1% for the resistor would be:
Maximum 479mA
Minimum 384mA

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

charlespax, 2016-12-11:
I've added a 2.32K resistor to the RLC library and added it to the schematic.

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

Closed 2016-12-11.

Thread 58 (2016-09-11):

Battery charge self?

charlespax, 2016-09-11:
Review the MCP73831 datasheet. The battery is connected to VBUS through a diode. Will the MCP73831 try charging the battery if the system is on battery power? If so, add a switching circuit like what is on the T400.

charlespax, 2016-09-13:
From the MCP73831 datasheet. The input voltage much be 150 mV above the battery voltage for the MCP73831 to become operational 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

Closed 2016-09-13.

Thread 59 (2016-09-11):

USB power protection

charlespax, 2016-09-11:
What protection is needed on the USB power? Right now it's connected directly to VBUS.

robojay, 2016-10-30:
Add a PTC resettable fuse between the USB connector VCC pin and VBUS.

I've used Bel Fuse 0ZCJ0050FF2G (Digi-Key 507-1802-1-ND) in similar applications.

robojay, 2016-12-11:
Add a transient voltage suppressor between VUSB and ground.  Something like SMBJ5.0A will work.

charlespax, 2017-01-23:
I've added a PTC resettable fuse. I'm going for the 0805 package because that fits best on the board.  This part seems good: http://www.digikey.com/product-detail/en/bel-fuse-inc/0ZCK0050FF2E/507-1813-2-ND/4156141
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

charlespax, 2017-01-23:
I've added a transient voltage suppressor to USB_VBUS. It's the same as what I have on the data lines.

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

Closed 2017-01-23.

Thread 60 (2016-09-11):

SD card protection

charlespax, 2016-09-11:
What protection should be on the SD card. There are some ICs specifically for this task.

samchoy88, 2016-12-14:
I think you looking for EMI filter and ESD protection to prevent damage on MCU.
This IC integrate the emi filter and ESD protection circuit, designed for limited space applications.

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

charlespax, 2017-01-22:
See also the firmware issue https://github.com/PaxInstruments/PaxInstruments-LabWiz-firmware/issues/18

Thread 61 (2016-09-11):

USART1 GND connection

charlespax, 2016-09-11:
USART1 RX and TX are broken out to a header. Add a GND connection also.

charlespax, 2016-09-13:
Done

Closed 2016-09-13.

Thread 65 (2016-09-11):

Reset switch component

charlespax, 2016-09-11:
Find a good switch for RESET. Vertical or right angle? Is there a good spot from which it can be pressed from outside the enclosure? Probably best at the top such that it can be activated when the top panel is removed.

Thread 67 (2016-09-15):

I2c pull up resistors

charlespax, 2016-09-15:
Redo calculations and find what would be a good value. Can we even have a fixed value without knowing the total capacitance on the lines?

We could go nuts and use digital pots.

charlespax, 2017-01-22:
Dupe of https://github.com/PaxInstruments/labwiz-board/issues/67

electrokean, 2017-01-22:
Dupe of itself?

charlespax, 2017-01-23:
hahahaha Dupe of #68

Closed 2017-01-22.

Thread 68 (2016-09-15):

I2c pull up resistors

charlespax, 2016-09-15:
Redo calculations and find what would be a good value. Can we even have a fixed value without knowing the total capacitance on the lines?

~~We could go nuts and use digital pots.~~

**Notes**
- Drew did not have success with 1.5k resistors, but did with 10k resistors
- Refer to T400 i2c issue: https://github.com/PaxInstruments/t400-electronics/issues/10
- Stack Exchange topic: http://electronics.stackexchange.com/questions/1849/is-there-a-correct-resistance-value-for-i2c-pull-up-resistors
- Equations to use to determine i2c resistor range.
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

charlespax, 2017-01-27:
I made a graph showing the pullup resistor range for 100kHz and 400 kHz.
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

We should keep the pullup resistors values as low as necessary to allow for a larger enough bus capacitance range. This is because the modules affect the bus capacitance.

charlespax, 2017-01-27:
I wonder if the internal pullup resistors were enabled on the i2c lines. That would explain why we needed such a high value on the external resistors; the internal and external resisotrs might be running in parallel.

charlespax, 2017-01-27:
I'm keeping the 1.5k in the design for now. When revision 4 comes back I will try different values. See i2c pullup resistor test #135

Closed 2017-01-27.

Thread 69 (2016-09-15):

REST button location

charlespax, 2016-09-15:
Use a right angle reset button. Locate at the top edge of the PCB.

I'm making a enclosure top panel that will support the top edge of the modules. I can put a hold in the location of the yellow circle below. Then the device can be reset without taking apart the enclosure.
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

charlespax, 2017-01-27:
This has been done.

Closed 2017-01-27.

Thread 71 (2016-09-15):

Connector contact material

charlespax, 2016-09-15:
I will be shipping products with modules installed. I need to ensure the male and female contacts are plated such that the connection will not degrade over time.

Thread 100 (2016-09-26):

ESP8266 module fit test

charlespax, 2016-09-26:
Test how the module for version 0.3 fits in the enclosure.

charlespax, 2017-01-22:
The wifi modules on v0.3 is located just above SW_B. It does not fit in the enclosure properly. We could hack away one of the ribs and I think it would work. One of the small legs on the LCD would have to be broken off as it interferes with the wifi connector (not an problem).

However, if the black plastic part of the male connector is removed from the module, it sits fairly flush with the LabWiz PCB and does fit in the enclosure back. A strip of polyamide tape could be used as an insulator. The leads on the male connector would have to be clipped or they will interfere with the silicone keypad. Basically, remove the black plastic, insulate with tape, colder in place, clip leads, enjoy wifi. One of the small legs on the LCD would have to be broken off as it interferes with the wifi connector (not an problem).

There is potential for putting the connector just above SW_E. One of the small legs on the LCD would have to be broken off as it interferes with the wifi connector (not an problem). I think in this case we would still need to modify the pins on the wifi module and still may not be able to use a female connector on the LabWiz board.

There is a ground hook under the wifi module that should be moved. https://github.com/PaxInstruments/labwiz-board/issues/126

charlespax, 2017-01-24:
The module interferes with the battery holder. we would need to move the battery. The LCD clip will prevent the module from sitting flush, which means the module will not fit in the enclosure.

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

charlespax, 2017-01-24:
Test failed. Closing issue. See #32 to alternative solutions.

Closed 2017-01-24.

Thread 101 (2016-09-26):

SW_PWR component locations

charlespax, 2016-09-26:
Most switches have the capacitor above the resistor. Make SW_PWR be the same.

charlespax, 2017-01-31:
Not relevant.

Closed 2017-01-31.

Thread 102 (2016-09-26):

Move LCD passives

charlespax, 2016-09-26:
Move the passives away from the LCD connector on the left. They are a bit too close.

charlespax, 2017-01-24:
Done.

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

Closed 2017-01-24.

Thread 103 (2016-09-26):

RTC battery size

charlespax, 2016-09-26:
Maybe use a smaller RTC battery. First, let's find out how long we want it to last. Then let's find out what battery meets that requirement. A super cap would be great.

There is no need for this if we use a super cap. https://github.com/PaxInstruments/labwiz-board/issues/104

electrokean, 2017-01-25:
I've used a small rechargeble lithium batteries like the one on the Seeed modules mentioned in #16 on a Rasp Pi hat with RTC, but haven't done any testing on how long it lasts.
They are Seiko MS621FE 3V 5.5mAh
http://www.sii.co.jp/en/me/datasheets/ms-rechargeable/ms621fe/
I originally bought these to repair some portable barcode scanners for a client.
Being Lithium, even though ridicuously tiny, they still have shipping restrictions.

Elna make a similar size (actually a bit smaller) Supercap in the DSK series, 3.3V 0.22F.
I got some surplus stock which appear to be obsolete now, but there is a replacement worth a look.
http://mouser.com/ProductDetail/Elna/DSK-3R3H224U-HL/

With the main device battery providing power normally and charging these as secondary sources, I don't think they really need a long run time as these are basically there just to keep the RTC running to avoid having to reset the RTC.  With the potential for wireless, the device could even be made to sync time over NTP.

charlespax, 2017-01-25:
It would be nice to use a technology with no shipping restrictions. This way I can sell the PCBA as cheaply as possible. That's basically a super cap or a LiPo battery that is not soldered to the board.

electrokean, 2017-01-25:
Agreed.  The DSK supercap I mentioned above seems like a good option, is readily availble, and takes up little room.  The alternative is probably a CR1220 holder, but not sure you have space for that.

I did discover this thread about similar supercaps leaking/faling in Fluke meters on EEVblog Forums
http://www.eevblog.com/forum/testgear/fluke-189-with-leaking-surface-mount-coin-cell/
Interesting to note that the final post on that thread indicates Fluke apparently switched from these supercaps to the tiny Seiko lithium batteries I mentioned above.

There are a few mentions there of different style (larger) of supercap which might be a safer bet.  The Panasonic EEC-S0HD334H is another one I have, is cheaper, but is also through hole and rated for 5.5V (probably a smaller 3.3V version also).

I just noticed on DigiKey that there is an Elna DCK series supercap, which appears to have a compaible footprint to the Seiko MS621 rechargeable lithium batteries.  Maybe good if you have limited space, and not sure which is best.  You could even have more than one footprint (SMT+THT) to allow end user to replace.

Like all component selection, too many choices all with various tradeoffs.

charlespax, 2017-01-25:
The CR1220 is what's on the T400 and what has been on the LabWiz board. It doesn't quite fit on this board now that I've put the ESP-09 module in its former location.

A CR1025 battery will fit on the board. Here's the datasheet for the holder http://www.memoryprotectiondevices.com/datasheets/BK-870-datasheet.pdf.
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

charlespax, 2017-01-26:
I've put the RTC super cap idea (#16) on ice. We can explore that again in the future.

charlespax, 2017-01-28:
Th3e 1025 battery appears to work out nicely for layout. Closing issue.

Closed 2017-01-28.

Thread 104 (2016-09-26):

RTC super cap

charlespax, 2016-09-26:
It would be awesome if we could use a super cap for the RTC backup battery. Let's research this.

charlespax, 2017-01-22:
Duplicate of https://github.com/PaxInstruments/labwiz-board/issues/16

Closed 2017-01-22.

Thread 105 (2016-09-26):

Serial header location

charlespax, 2016-09-26:
Let's move the serial header down a bit. Currently it interferes with the top panel.

charlespax, 2017-01-24:
It's in a pretty good spot right now. It just might clear the cortex header.
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

 I think there isn't much of a choice for location while wires are connected to the header. I'd like to find a location where the header can be installed without wires and no interfere with the enclosure.

charlespax, 2017-01-24:
Wait a second, those are just pads. I'll see if we can fit a through hold header.

charlespax, 2017-01-24:
It looks like through hole would not work in this location.
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

charlespax, 2017-01-24:
Moving a three pin header to the other side wouldn't work either. Maybe just do RX and TX in a row and leave the GND connection out of row.
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

charlespax, 2017-01-24:
We can do a 2x2 right angle 2.54 mm header like this one:
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

We can put it on the left side in this location.
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

If the header is mounted on the back side of the board, we do not have to worry about any interference issue with the enclosure.

I've added a 2x2 right angle header to the back of the board. The pins should not interfere with the case.
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

Closed 2017-01-24.

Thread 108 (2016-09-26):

T420 via tenting

charlespax, 2016-09-26:
Make sure the T420 module vias are tented. Adjust size if necessary.

charlespax, 2017-01-24:
It looks like we're good with the CAM file in the repo. Here is the top mask layer:
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

Closed 2017-01-24.

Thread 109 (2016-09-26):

LabWiz connector footprint

charlespax, 2016-09-26:
Widen the LabWiz connector footprint pads. It's a bit tight on the male connector.

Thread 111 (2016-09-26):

USB connector interference

charlespax, 2016-09-26:
The USB connector interferes with the enclosure. Find a more suitable connector. Maybe move the connector.

charlespax, 2017-01-22:
There does exist a better connector. In the HQB markets I've seen a flangeless version of the connector in the T400. It looks more or less like this...
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

I have to find the part and implement the footprint. I believe one of the Blinkin Labs products uses it. https://github.com/Blinkinlabs

electrokean, 2017-01-22:
Looks like the same footprint at the Molex 105017-0001 or FCI 10118194-0001LF
I've found them much less likely to be pulled off the PCB than the flanged versions

electrokean, 2017-01-22:
Hang on - isn't this the footprint you referenced in https://github.com/PaxInstruments/labwiz-board/issues/18

charlespax, 2017-01-23:
Nope. #18 is about the footprint and the internal layers. This issue (#111) is about the flange of the MicroUSB connector interfering with the enclosure.

This part is similar to what is on the T400. Check out the flange.
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

electrokean, 2017-01-23:
Aha, I see.  Not the mounting flange, but the "entry" flange.
Fot the Molex part, that would be 105017-1001
http://www.digikey.com/product-detail/en/molex-llc/1050171001/WM11262CT-ND/3313406

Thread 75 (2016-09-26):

Diode values

charlespax, 2016-09-26:
Use the right diode values. Make we do not have current flowing back into the battery. Make sure voltage isn't dropping much off the battery. We should have the right footprints for the diodes.

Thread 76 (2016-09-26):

USB protection diodes

charlespax, 2016-09-26:
We are using some diodes on the USB lines. Make sure we are using the right diodes for this. Make sure we are using the right footprint.

robojay, 2016-10-30:
Take a look at this app note from ST.  It covers ESD protection and not needing the series resistors you have in the current design.

[ST AN4879.pdf](https://github.com/PaxInstruments/labwiz-board/files/560836/ST.AN4879.pdf)

charlespax, 2016-11-10:
Nice. We should ditch the resistors then. I also want to look at high-speed devices because the PCB will be compatible with several STM32Fx families.

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

charlespax, 2017-01-27:
Series resistors removed.
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

charlespax, 2017-01-27:
- [ ] "The full speed USB driver impedance on STM32 MCUs is guaranteed by design to be between 28 ohms and 44 ohms. The result is that these products do not need an external resistor on the board for the output driver impedance."
- [ ] "The track routing should respect 90 ohm +/-15% differential from the STM32 MCU’s package to the receptacle. It is important to route the two data lines in parallel to ensure the best impedance matching. A 45 ohm +/-15% single ended trace is recommended."
- [ ] "Routing USB signals using a minimum of vias and corners reduces the signal reflections and the impedance changes. When it becomes necessary to turn by 90°, it is preferred to use two 45° turns or an arc instead of making a single 90° turn. This action reduces the reflections on the signal by minimizing the impedance discontinuities."
- [ ] "A protection against ESD and EMI is needed... The HBM requires that the USB pins of the component device are tolerant to up to 2 kV discharge, this is the case for the STM32 MCUs." Done. The ESD diodes can handle the 2 kv.
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
- [ ] "The component needs to be placed as close as possible to the receptacle to add ESD protection against high ESD surge. The USBLC6 component is recommended for such protection on VBUS and USB data lines."
- [ ] "It is recommended to implement a resistor bridge to lower the voltage used for VBUS detection. This recommendation is even more important when VDD on the STM32 MCU is not present while VBUS is supplied from the connector." Done.
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

Closed 2017-01-27.

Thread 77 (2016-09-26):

LED on PCB

charlespax, 2016-09-26:
~~We have two unused pins.~~ Let's add some LEDs. Place on upper edge. Align with an LED hold.

charlespax, 2017-01-28:
We don't really have any _unused_ pins, but we may still be able to put an LED on a pin. This would be really nice for getting a new board up and running. We could always leave it unpopulated in the final design. Maybe put a normally open solder jumper in series.

Possible options
- LCD_BL (PA10)
- PC1_BOOT0 (PC1)

charlespax, 2017-01-31:
Connected in parallel with LCD_BL.
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

Closed 2017-01-31.

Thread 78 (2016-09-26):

LED hole

charlespax, 2016-09-26:
In the top panel, add a hole for an LED to shine through.

See https://github.com/PaxInstruments/labwiz-board/issues/77

charlespax, 2017-01-31:
We don't need an LED to shine through. We have an LCD. An onboard LED would be for testing and may not be populated in the final product.

Closed 2017-01-31.

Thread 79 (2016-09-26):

Cortex header overlaps USART1

charlespax, 2016-09-26:
I think we'll have to move USART1 since the location of the debug header is restricted by the enclosure quite a bit and it seems to where where it is.

charlespax, 2017-01-27:
No longer an issue.

Closed 2017-01-27.

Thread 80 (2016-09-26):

LabWiz connector interferes with BL-5C header

charlespax, 2016-09-26:
It's really close. Maybe we can shorten up the legs (only if we have to). Maybe we can find a battery connector that has locating pins. Maybe we can move the battery connector down a bit.

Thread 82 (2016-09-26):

Via drill size

charlespax, 2016-09-26:
See about bumping up to 0.3 mm drill size. I think the board house that did version 0.2 used a drill larger than the specified 0.2 mm. The 0.2 mm drill holes indicated on the version 0.3 board were much smaller than the v0.2 board.

charlespax, 2017-01-28:
Whatever... just keep it as is.

Closed 2017-01-28.

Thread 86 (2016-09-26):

LabWiz silkscreen location

charlespax, 2016-09-26:
The "LabWiz 0.3" silkscreen is a bit too close to the bottom edge. Move up.

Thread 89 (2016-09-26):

Wireless integration

charlespax, 2016-09-26:
Add and ESP8266 or other circuit directly onto the LabWiz board. Alternatively, we can make our own module board.

A separate module could be good for keeping cost down. We could then break out the GPIO of the chip on the module. It could also help with certification as we may be able to iterate on the module for compliance rather than spinning an entire LabWiz revision.

charlespax, 2017-01-22:
Let's just use the regular wifi module. It fits in the enclosure. Let's move forward.

Closed 2017-01-22.

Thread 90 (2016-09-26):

Cortex pin 1 indicator

charlespax, 2016-09-26:
Add a pin 1 indicator to the Cortex header footprint. LabWiz v0.3 has it directly on the board, so that would have to be removed.

charlespax, 2017-01-24:
I made a leg on the doc layer a little longer. This does not affect the silkscreen, but makes it easier to identify pin 1 while laying out the board.
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

Closed 2017-01-24.

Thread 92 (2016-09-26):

MCU locating text

charlespax, 2016-09-26:
Add some text on the silkscreen to indicate the orientation of the STM32 chip. ST decided to put two indicators on the chip. I believe the larger circle is an ejector pin hole. Makes no damn sense!

charlespax, 2017-01-28:
From the datasheet:
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

What I have on the board:
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

Closed 2017-01-28.

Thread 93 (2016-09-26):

RESET hole alignment

charlespax, 2016-09-26:
Make sure the RESET button aligns with the hole in the enclosure.

charlespax, 2017-01-28:
It appears to align just fine.

Closed 2017-01-28.

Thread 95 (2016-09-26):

Module width

charlespax, 2016-09-26:
I would like to increase the width of the modules. The width target is equal to or grater than the width of a mini thermocouple connector. This way a T400 could be created from four individual modules. To accomplish this the entire module area would need to be the same width as the LCD mounting legs.

Each single module would need semicircle cutout on each side, so it could be located on either side. These notches could also used for mounting in a module-to-USB adapter enclosure.

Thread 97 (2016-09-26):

Top edge extension

charlespax, 2016-09-26:
Extend the top edge of the PCB into the top panel on the left and right. This would be where the RESET button is located. Add ribs on the top panel that grab the PCB edge. This will help keep the LabWiz PCB, module, and top panel connected well.

charlespax, 2017-01-24:
I think we can extend it by 2.5 mm 2.75 mm wide (~ 108 mil).

charlespax, 2017-01-24:
Done.
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

Closed 2017-01-24.

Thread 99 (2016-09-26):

Cortex header fit

charlespax, 2016-09-26:
Test how the Cortex header and cable fit in the enclosure. Make necessary adjustments.

charlespax, 2017-01-24:
Fits perfectly! We could possibly move the header towards the top by 0.5 mm if absolutely necessary.

Closed 2017-01-24.

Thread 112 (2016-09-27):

Double sided PCB

charlespax, 2016-09-27:
There are several components on the back side of the PCB. This is essentially a double sided design. Let's go full double-sided with it. This may be especially useful if we integrate the wireless circuit.

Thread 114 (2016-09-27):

STM32F405 support

charlespax, 2016-09-27:
The STM32F405 chip should be a drop-in replacement for the STM32F103 chip we are using in LabWiz 0.3. However, I can't communicate with the chip over the SWD interface.

Review the MicroPython board schematic and see if there are any potential issues. Find additional boards to review and compare against LabWiz.

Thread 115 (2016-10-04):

Battery third terminal

charlespax, 2016-10-04:
I believe the BL-5C battery has a third terminal for either an internal identification resistor or a thermistor. If it's a thermistor, we can tap into it to measure the battery temperature.

charlespax, 2017-01-22:
According to this post (http://kmmankad.blogspot.com/2011/06/whats-that-middle-pin.html), the third pin is just for an identification resistor.

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

Closed 2017-01-22.

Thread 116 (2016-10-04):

Battery charge cutoff

charlespax, 2016-10-04:
A li-po battery should not be charged if it is below 0C. If the charging IC does not handle this, we should add some control to the microcontroller.

charlespax, 2017-01-22:
Note: The third terminal on the BL-5C battery is not a thermistor. See https://github.com/PaxInstruments/labwiz-board/issues/115

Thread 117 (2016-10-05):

Switches on same interrupt

charlespax, 2016-10-05:
"The buttons should be marked as EXTI in CubeMX.  It appears that SW_A and SW_C are on 2 pins that are both connected to EXTI9. You can only map to a single pin, so we will not be able to trigger either SW_A or SW_C."

On version 0.3 the buttons map to interrupts as shown below.

```
SW_A, EXTI9
SW_B, EXTI8
SW_C, EXTI9
SW_D, EXTI2
SW_E, EXTI10
SW_PWR, EXTI0
```

We have two unused pins on v0.3 that we can swap out.

```
PC1, EXTI1
PC4, EXTI4
```

WIFI_EN is on PC7 (EXTI7). That pin is close to  SW_A and SW_B and already routes to the same side of the PCB. It would work best for routing if we swap SW_A and WIFI_EN.

charlespax, 2017-01-24:
Fixed. See https://github.com/PaxInstruments/labwiz-board/issues/129

Closed 2017-01-24.

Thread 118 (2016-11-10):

Power down completely

charlespax, 2016-11-10:
Does LabWiz ever power down completely or just go into a deep sleep mode? There are no power switching components.

Here is a power switching example.
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

charlespax, 2016-11-10:
It has been suggested that we disconnect the battery with a MOSFET.  By completely disconnecting the battery via MOSFET you don't have any leakage current (e.g. the battery sense divider, quiescent current of regulator, etc.). The tradeoff is complexity though. There may be a part that integrates all this functionality

robojay, 2016-12-11:
Related items... The 3.3V regulator dropout voltage (MIC5219-3.3, max of 400mV at 150mA, or max of 600mV at a 500mA burst) should be taken into account with battery voltage state.  How low do you want to run the battery? 3.3V + 0.4V = battery needs to be >= 3.7V, etc.

If you don't have a way to disconnect the battery, you will continue to run it down, potentially inflicting permanent damage to the battery.

robojay, 2016-12-11:
Depending on your overall current requirements, there are parts around that integrate charging, battery disconnect, something like this: http://www.microchip.com/wwwproducts/en/MCP73871

charlespax, 2017-02-02:
Li-Po discharge curve:
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

The Qduino (https://www.sparkfun.com/products/13614) uses the AP2112K-3.3TRG1 (http://www.diodes.com/_files/datasheets/AP2112.pdf).

AP2112K output voltage vs input voltage:
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

I think this part will take care of us pretty well. We can get our 3.3V all the way down to a battery voltage of 3.3V.

charlespax, 2017-02-02:
The Qduino also has autoswitching between battery and USB:
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

I've incorporated that design:
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

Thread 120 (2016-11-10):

PCB routing

charlespax, 2016-11-10:
Get rid of 90 degree bends. It will make some people very happy and the rest won't care one way or another.

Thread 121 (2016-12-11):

MCP73832T-2 Battery Charger

robojay, 2016-12-11:
With the battery voltage divider in place, the charger will always think a battery is installed (look at the data sheet (http://ww1.microchip.com/downloads/en/DeviceDoc/20001984g.pdf) for battery detection method).  I don't think this is a problem for the current design, but something to note.

Also, the data sheet says a bypass cap should also be on the regulator's VIN (VDD) pin.  You should add one.

charlespax, 2017-02-02:
I've added a fuel gauge. Same as in the SparkFun LiPo Fuel Gauge (https://www.sparkfun.com/products/10617).
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

Removed voltage divider from battery.
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

PC5 is now available. We could attach it to the alert interrupt of the fuel gauge, but I don't think it's worth sacrificing a pin.

Closed 2017-02-02.

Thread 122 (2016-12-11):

Module interface (SPI and USART)

robojay, 2016-12-11:
How is the SPI chip select being handled?  How will two SPI modules avoid conflicts?

Is the intent to use one of the GPIO lines as the SPI chip select? Will that need to be configured on each module? Or will SPI always use the same GPIO?

Similarly, how is the sharing of the USART2 channel being handled? Multi-drop? Chip select?

charlespax, 2017-01-22:
There are four modules (1-4). Modules 1 and 3 each have one hardware SPI_NSS line and one GPIO. Modules 2 and 4 each have two GPIO lines. Modules 1 and 2 share a SPI port while modules 3 and 4 share another SPI port.

I believe there will not be a conflict with module 1 using the hardware SPI_NSS while module 2 uses a GPIO as the chip select. If there is a conflict, we can set the module 1 SPI_NSS pin to be in regular GPIO mode and be treated the same as module 2.

Sharing of USART2 would have to be done using the GPIO pins on the modules. The firmware would have to use a module GPIO line as a clear to send (CTS) signal to the module.

Closed 2017-01-22.

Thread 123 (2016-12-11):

Signal Integrity

robojay, 2016-12-11:
Check high speed lines for any signal integrity issues (primarily overshoot and undershoot).  No serial termination resistors (or other slew rate control schemes) exist in the current design.  This may not be an issue, but it should be looked at.  Critical lines to look at would be any clock or control signals that rely on edge sensing (e.g. LCD, SD Card, and SPI).

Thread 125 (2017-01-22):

SPI pullup/pulldown resistors

charlespax, 2017-01-22:
Do we need any pullup or pulldown resistors on the SPI lines?

electrokean, 2017-01-22:
Generally I'd put a pullup on the SPI !CS signal at the slave.  I may also put a pullup on the MISO at the master, but this can usually be done via the internal I/O pin configuration.  An external (lower value) may be needed if there are long connecting cables.
A reference to Arduino SPI best practices: https://www.dorkbotpdx.org/blog/paul/better_spi_bus_design_in_3_steps

charlespax, 2017-01-27:
In the STM32 datasheet and reference manual I cannot find anything indicating that SPI has any pullup resistors. However, GPIO does. I'm not sure if that also translates to that pin in SPI mode. I'll just keep them for now.

I'm putting this in the ice box for future investigation.

charlespax, 2017-01-27:
I'm putting pullups on the board. We can try them.
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

charlespax, 2017-01-28:
Moved to Milestone 4.1 for review after we have the 0.4 boards.

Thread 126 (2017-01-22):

GND hook under wifi module

charlespax, 2017-01-22:
Move any ground hook connections from under the wifi module.

charlespax, 2017-01-24:
Not relevant anymore. This was fixed already.

Closed 2017-01-24.

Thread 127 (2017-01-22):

Hardware for USB bootloader?

charlespax, 2017-01-22:
See https://github.com/PaxInstruments/PaxInstruments-LabWiz-firmware/issues/3

electrokean, 2017-01-22:
Maybe time to re-evaluate use of STM32F103 and use something newer like the STM32L476
Lower power, faster, better features, proper USB DFU support - but I haven't compared pinout...
Maybe check it out in STM32Cube?
There's active development for Arduino support https://github.com/GrumpyOldPizza/arduino-STM32L4

charlespax, 2017-01-23:
I went through a bunch of chips to make sure the layout is compatible with as many chips as possible. See https://github.com/PaxInstruments/labwiz-board/issues/50. STM32L476 is not on the list, but I'm not sure why. Was that chip released after September 5th?

I just went through CubeMX and all the pin mapping appears to work out.

STM32L476:
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

Current LabWiz STM32F103:
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

electrokean, 2017-01-23:
Great!  The L4 series look really nice.
I believe it was released about 12 months ago, but it may not have been added to STMCube32 till later.
I only started looking at it recently, although I'm more interested in its little brother the L432

charlespax, 2017-01-24:
I think we're good on the bootloader hardware. Closing...

Closed 2017-01-24.

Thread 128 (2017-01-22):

USB hardware

charlespax, 2017-01-22:
Are there any hardware requirements to address this firmware issue? https://github.com/PaxInstruments/PaxInstruments-LabWiz-firmware/issues/3

charlespax, 2017-01-23:
I've just reopened the original issue https://github.com/PaxInstruments/labwiz-board/issues/27

Closed 2017-01-23.

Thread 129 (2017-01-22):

Button interrupt review

charlespax, 2017-01-22:
Go through all the buttons and ensure they are on individual interrupts.

See also https://github.com/PaxInstruments/PaxInstruments-LabWiz-firmware/issues/10 and https://github.com/PaxInstruments/PaxInstruments-LabWiz-firmware/issues/12

charlespax, 2017-01-22:
In commit 27a1f19b45323987bc93ce3aed916cd97b79b456

SW_PWR, GPIO_EXTI0
SW_A, GPIO_EXTI9
SW_B, GPIO_EXTI8
SW_C, GPIO_EXTI9
SW_D, GPIO_EXTI10
SW_E, GPIO_EXTI2

There is a collision between the interrupts of SW_B and SW_D. Both PC1 and PC4 are available and are suitable for replacing one of the EXTI9 lines. PC1 is on the side of the microcontroller that faces SW_A and SW_C, so that is probably a good choice. PC1 is on the top, so I think it would route nicely over to SW_A.

charlespax, 2017-01-22:
Swapped WIFI_EN with SW_A to avoid interrupt sharing.

Closed 2017-01-22.

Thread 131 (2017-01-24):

RFM69 radio

charlespax, 2017-01-24:
Consider using the RFM69 chip. The module is too large, but maybe this would be a good solution. There exists RFM69-WiFi and RFM69-Bluetooth bridges. It's nice and low power. JeeLabs uses it.

**Notes**
- RFM69 uses a SPI interface

charlespax, 2017-01-27:
Nope. It looks like we can get an ESP8266 module on the board (#132).

Closed 2017-01-27.

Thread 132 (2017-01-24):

ESP8266 modules

charlespax, 2017-01-24:
There are many modules listed on http://www.esp8266.com/wiki/doku.php?id=esp8266-module-family. The very common ESP-01 will not fit in the enclosure. We need something 13mm wide or smaller.

charlespax, 2017-01-24:
Here are the modules that are worth further investigation.

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

charlespax, 2017-01-24:
The ESP-09 is promising. It's 10 x 10 mm. In the image below the white box indicates a 10 x 10 mm square. It would be worth finding a new RTC battery backup solution (#16, #103 ).

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

charlespax, 2017-01-24:
Wow! Check out the ESP-09. I think this might work :-)
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

Library I used for this footprint: https://github.com/wvanvlaenderen/ESP8266-Eagle_Librar

charlespax, 2017-01-25:
The ESP-09 module fits nicely. Still need an antenna #134. Still need to implement a new RTC backup solution (#103, #16).
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

Closed 2017-01-25.

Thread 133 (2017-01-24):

Put USART3 on modules

charlespax, 2017-01-24:
Right now all four modules share USART2 while USART3 is dedicated to the wifi modules. Maybe we should have modules 1 and 2 share USART while modules 3 and 4 share USART3.
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

electrokean, 2017-01-24:
If you're going to share the USART between module slots, can I suggest using AND gates on the receive pins to avoid electrical contention.  Something like the 74LVC1G08 or 74LVC2G08.  Else, I'd suggest only connecting two module slots.

charlespax, 2017-01-25:
Good call. Do you mean AND gate or OR gate?

I think we would want a four input OR gate (one for each module TX) with the output going into STM32 RX.

The SPI MISO lines should also be on OR gates unless SPI already handles this. I2C should be fine since it's made to handle the electrical contention issue.

charlespax, 2017-01-25:
Maybe just kill the idea of serial on all modules. We can take the STM32 RX and TX pins and use them as GPIO. If we route them both to either modules 2 or 4, then that module can have an extra capability

electrokean, 2017-01-25:
I did mean AND gate.  The UART signals idle in a high state, so are active low.  An AND gate can be used to combine the negative logic.  I was thinking you'd use two of the tiny 2 input AND gates, to combine the RX signals coming from each pair of modules into USART2 and USART3 repectively.

The idea would be that the modules would act in a kind of multi-drop bus architechture.  You could use a GPIO or some address jumpers on each module to make them unique.

If you're going to keep the ESP8266, then I guess you only have USART2 available?  In that case you'd need a 4-input AND gate.  No such thing in the TinyLogic families, but you could use two 3-input ANDs e.g. 74LVC1G11 or NC7SZ11.  The SOT363/SC-70-6/SC-88 packages don't take up much space.

Regarding SPI, the DO lines on well behaved SPI slaves should tri-state.  Check the link I posted in #125 re SPI best practices.  If an SPI slave device on a module is not well behaved, the module should implement a separate tri-state buffer.

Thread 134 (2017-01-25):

WiFi antenna

charlespax, 2017-01-25:
I need to find the right antenna for the ESP8266 module.

Reference #132

charlespax, 2017-01-27:
I've added the antenna component, but this circuit is incomplete. I'll have to learn more about layout for this type of component.

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

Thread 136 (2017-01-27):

Route USB lines better

charlespax, 2017-01-27:
From https://github.com/PaxInstruments/labwiz-board/files/560836/ST.AN4879.pdf

"The track routing should respect 90 ohm +/-15% differential from the STM32 MCU’s package to the receptacle. It is important to route the two data lines in parallel to ensure the best impedance matching. A 45 ohm +/-15% single ended trace is recommended."

 "Routing USB signals using a minimum of vias and corners reduces the signal reflections and the impedance changes. When it becomes necessary to turn by 90°, it is preferred to use two 45° turns or an arc instead of making a single 90° turn. This action reduces the reflections on the signal by minimizing the impedance discontinuities."

For previous discussion see #76

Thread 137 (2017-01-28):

PCB top edge widening

charlespax, 2017-01-28:
Make the top edge a bit wider. We are making a new top panel, so we don't need to consider interfering with the T400 top panel.
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

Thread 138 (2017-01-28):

Module GPIO assignments

charlespax, 2017-01-28:
Review all the GPIO pins on the modules. Make sure we get as much additional functionality as possible.

- Remove USART from all modules. Make sure the USART2 ping as the GPIO pin on  module 2 or module 4. This will be an alternative function for those pins.
- This will free two pins on each module. What should we do with these? More power and ground?

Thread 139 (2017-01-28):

Beefy 3.3V regulator

charlespax, 2017-01-28:
We should have a regulator that can output a good deal of power. It should be capable of converting the entire battery output.

This datasheet (http://docs-europe.electrocomponents.com/webdocs/0cf3/0900766b80cf37fc.pdf) gives a max discharge current of 1200 mA.

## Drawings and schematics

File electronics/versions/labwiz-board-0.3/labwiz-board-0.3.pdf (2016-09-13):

# Module Connectors

# Notes

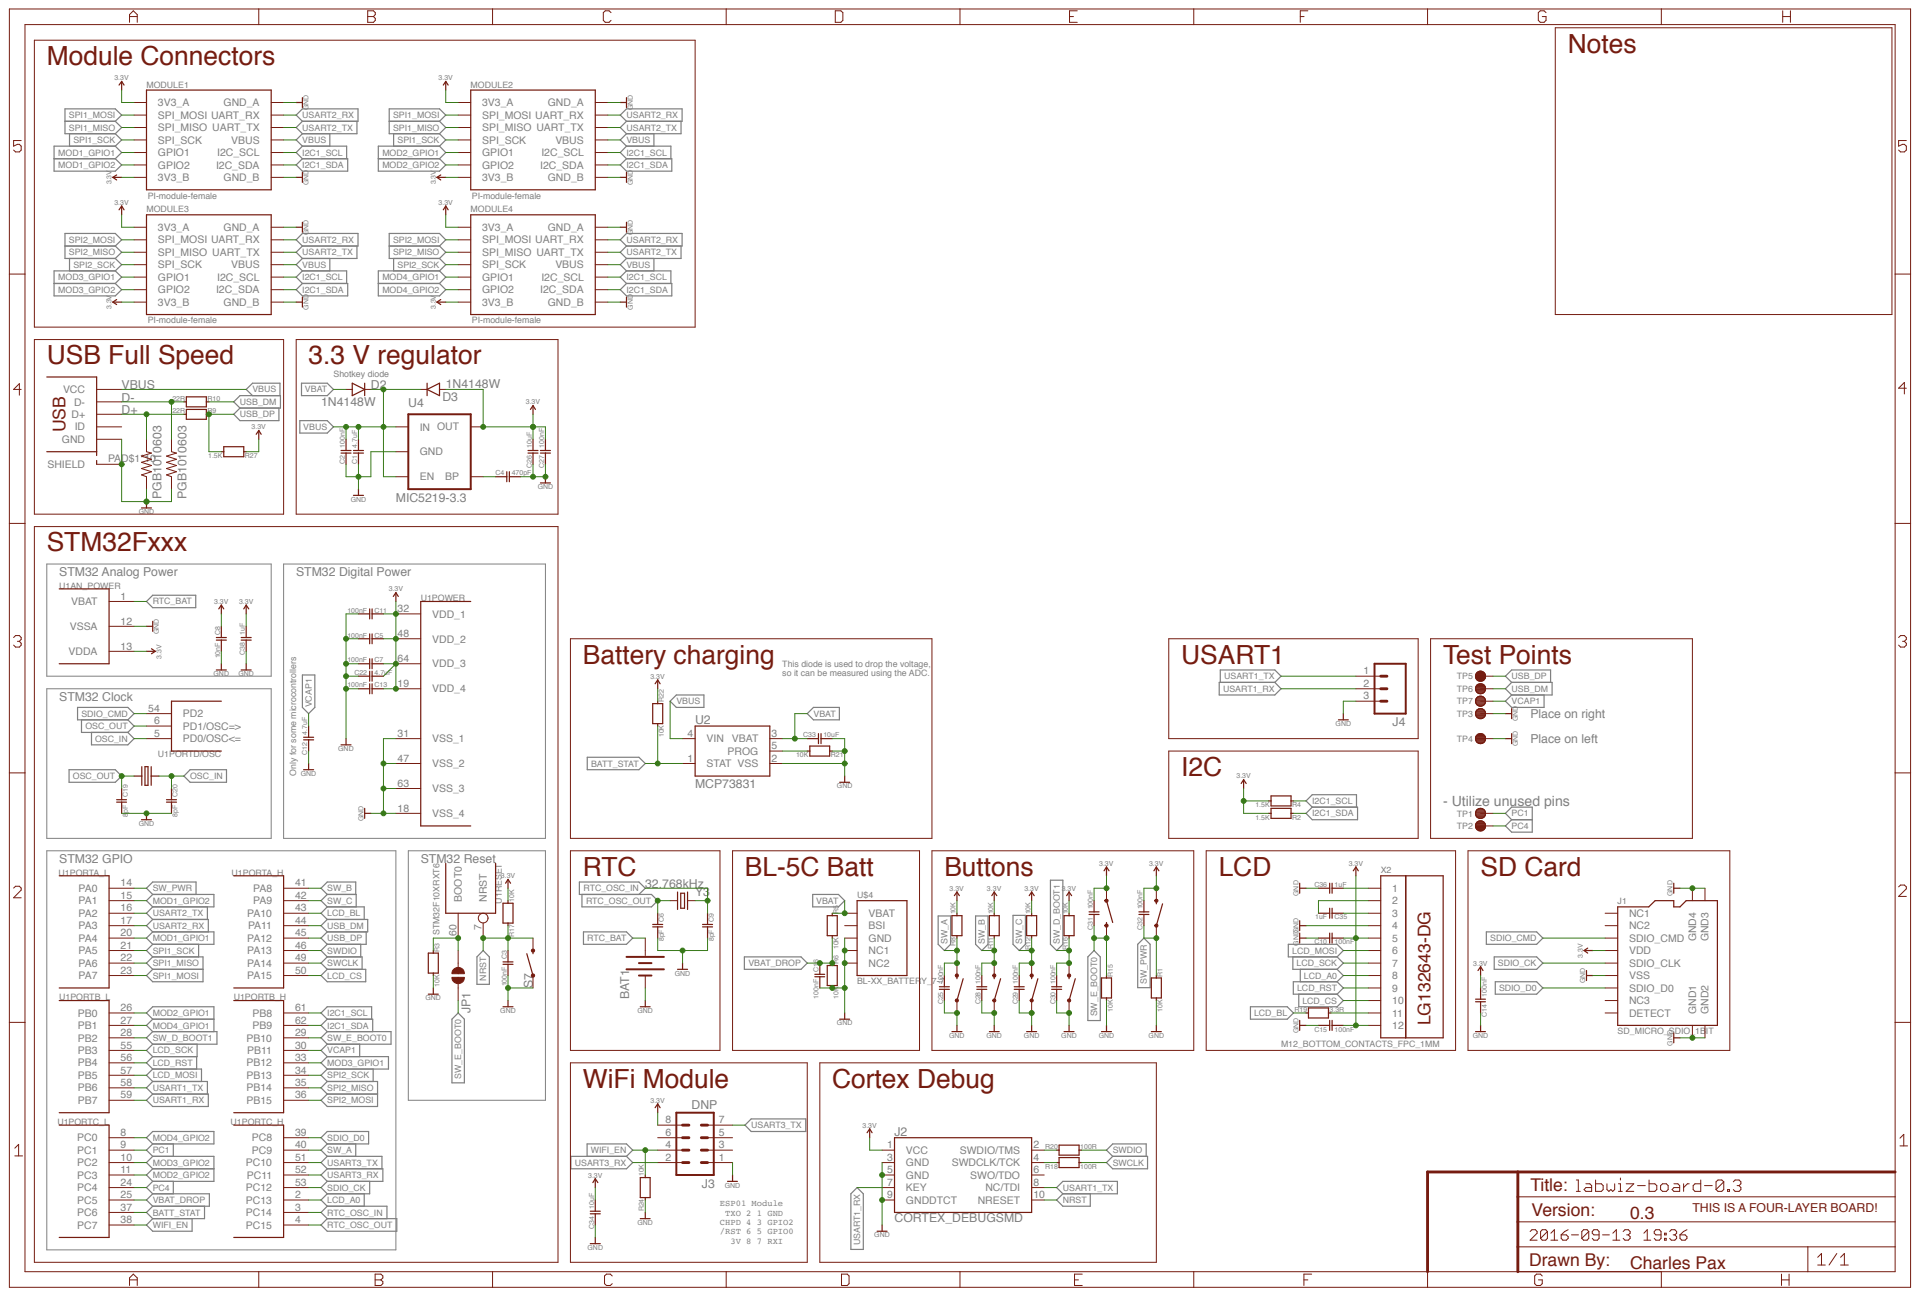
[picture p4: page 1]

Only for some microcontrollers

This diode is used to drop the voltage,
so it can be measured using the ADC.

THIS IS A FOUR-LAYER BOARD!

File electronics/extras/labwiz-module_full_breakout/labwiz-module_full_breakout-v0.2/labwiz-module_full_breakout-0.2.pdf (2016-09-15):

# Module 1

# Module 3

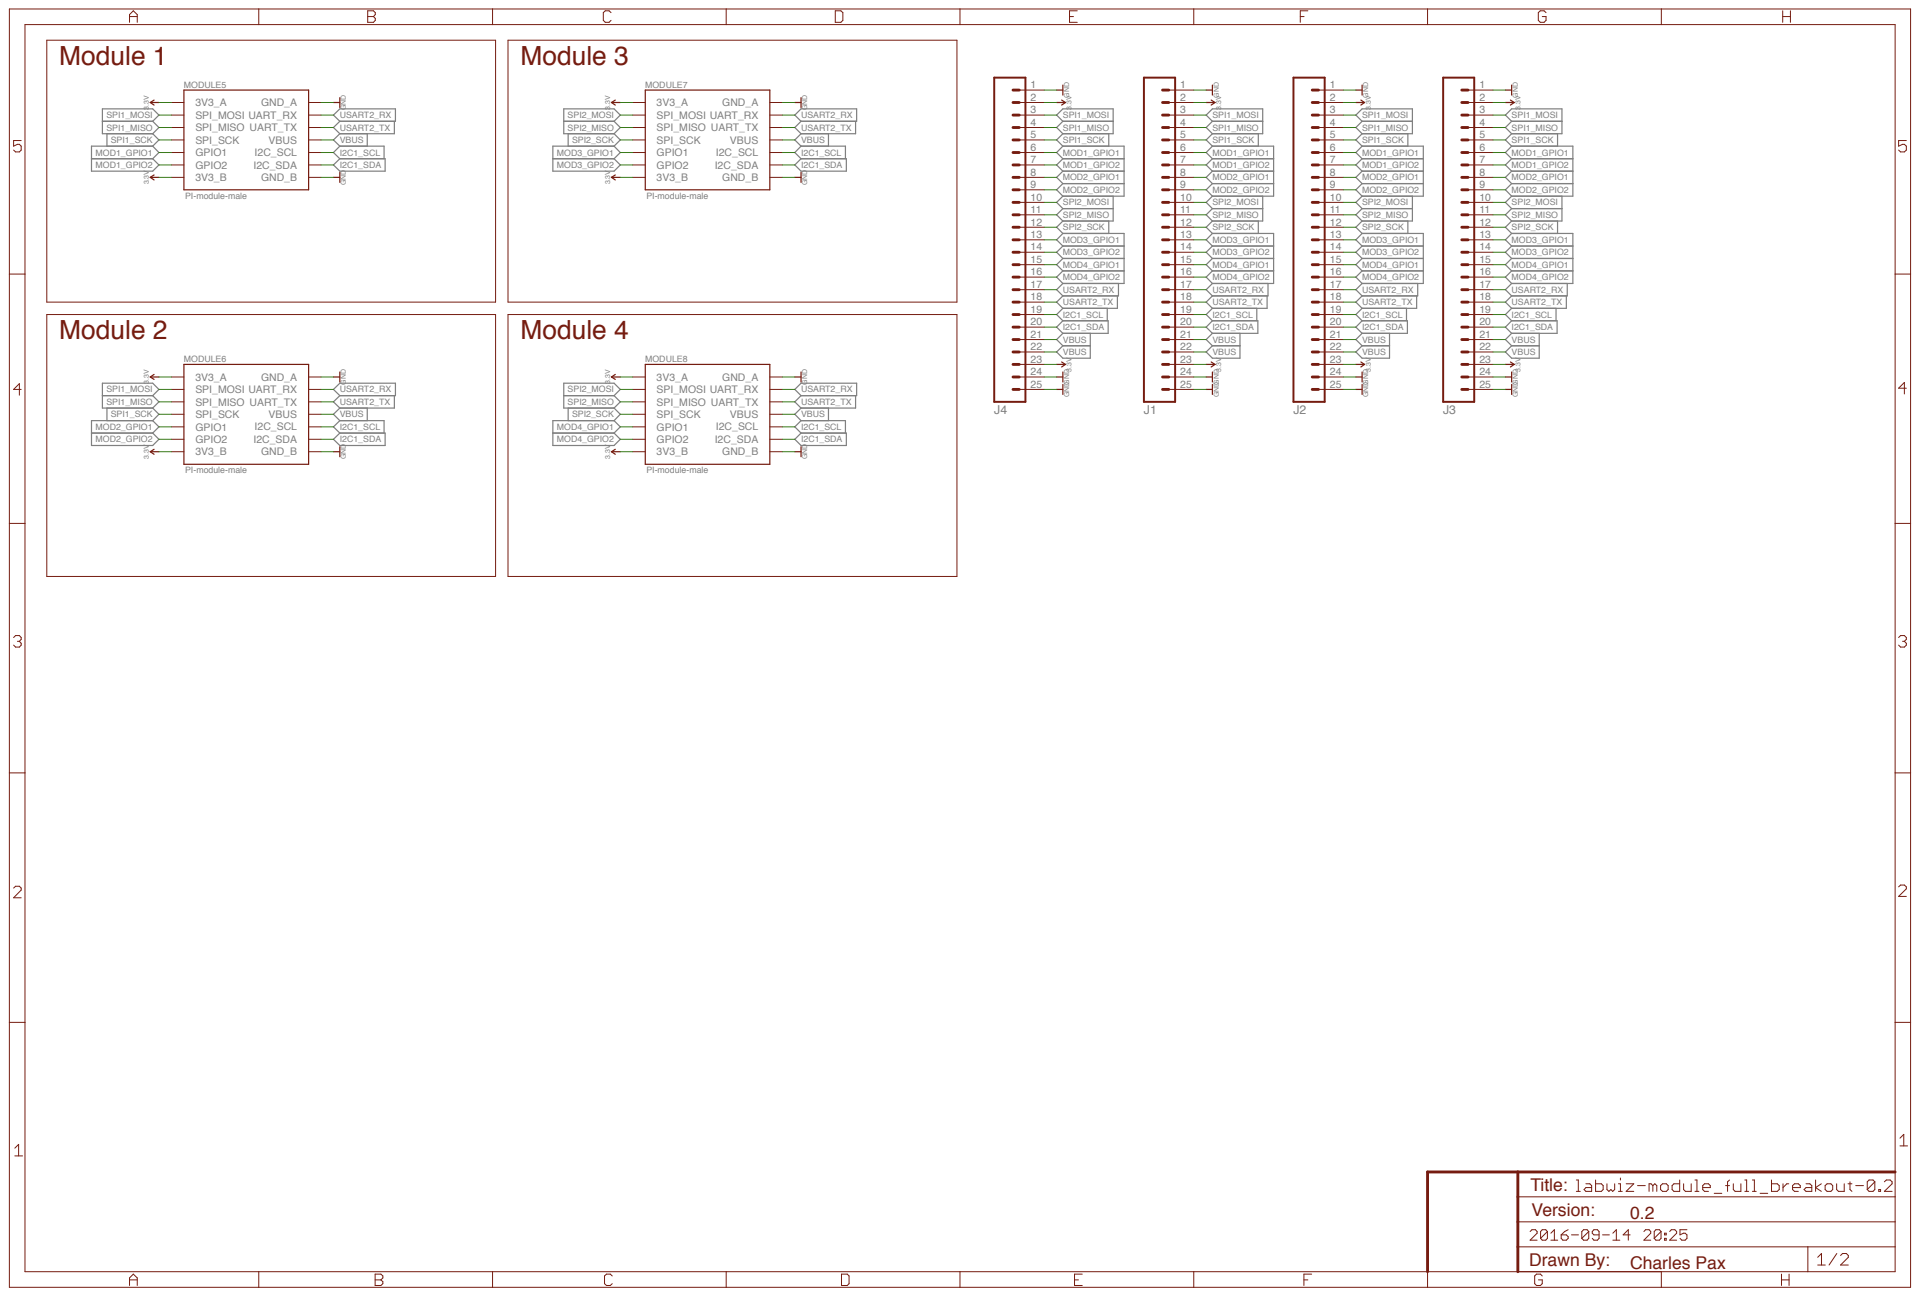
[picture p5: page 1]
GND; 3.3VGND GND; 3.3V GND; 3.3VGND GND 3.3V GND; GND_A; SPI_MOSI; I2C_SDA; SPI_MISO; UART_RX; SPI_SCK; UART_TX; GPIO1; VBUS; GPIO2; I2C_SCL; GND_B; MODULE5; MODULE6; MODULE7; MODULE8; MOD2_GPIO1; SPI1_MOSI; SPI1_MISO; I2C1_SDA; I2C1_SCL; USART2_RX; SPI2_MOSI; SPI2_MISO; SPI2_SCK; MOD1_GPIO1; SPI1_SCK; MOD3_GPIO1; MOD4_GPIO1; USART2_TX; MOD1_GPIO2; MOD2_GPIO2; MOD4_GPIO2; MOD3_GPIO2; Charles Pax; Module 2; Module 4; Drawn By:; Title: Version:

PI-module-male

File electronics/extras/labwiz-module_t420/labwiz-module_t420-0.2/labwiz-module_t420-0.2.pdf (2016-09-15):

3.3V

0.1uF

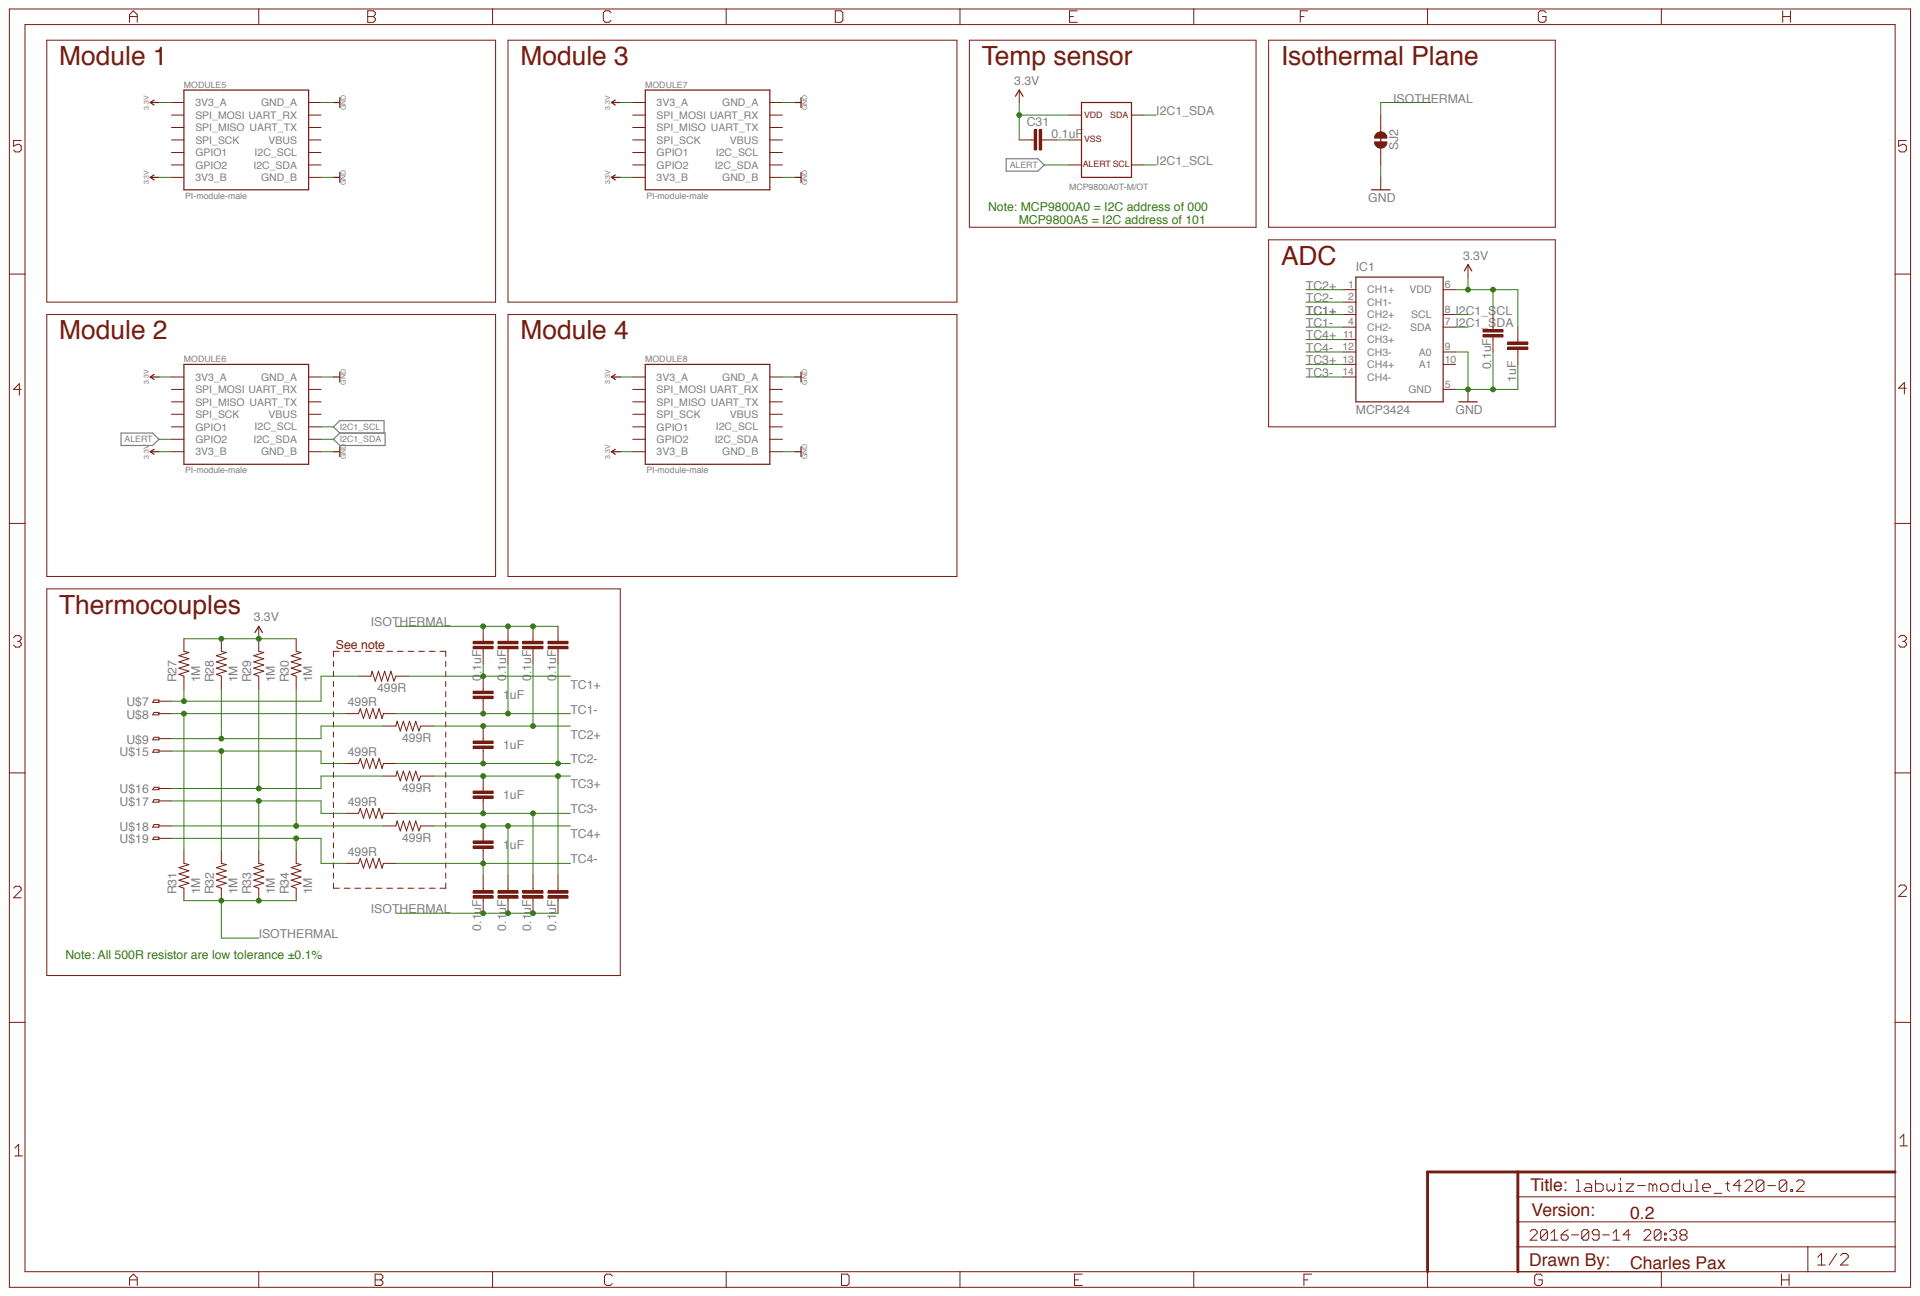
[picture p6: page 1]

Note: All 500R resistor are low tolerance ±0.1%

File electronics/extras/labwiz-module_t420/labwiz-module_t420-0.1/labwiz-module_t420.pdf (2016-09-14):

3.3V

3.3V

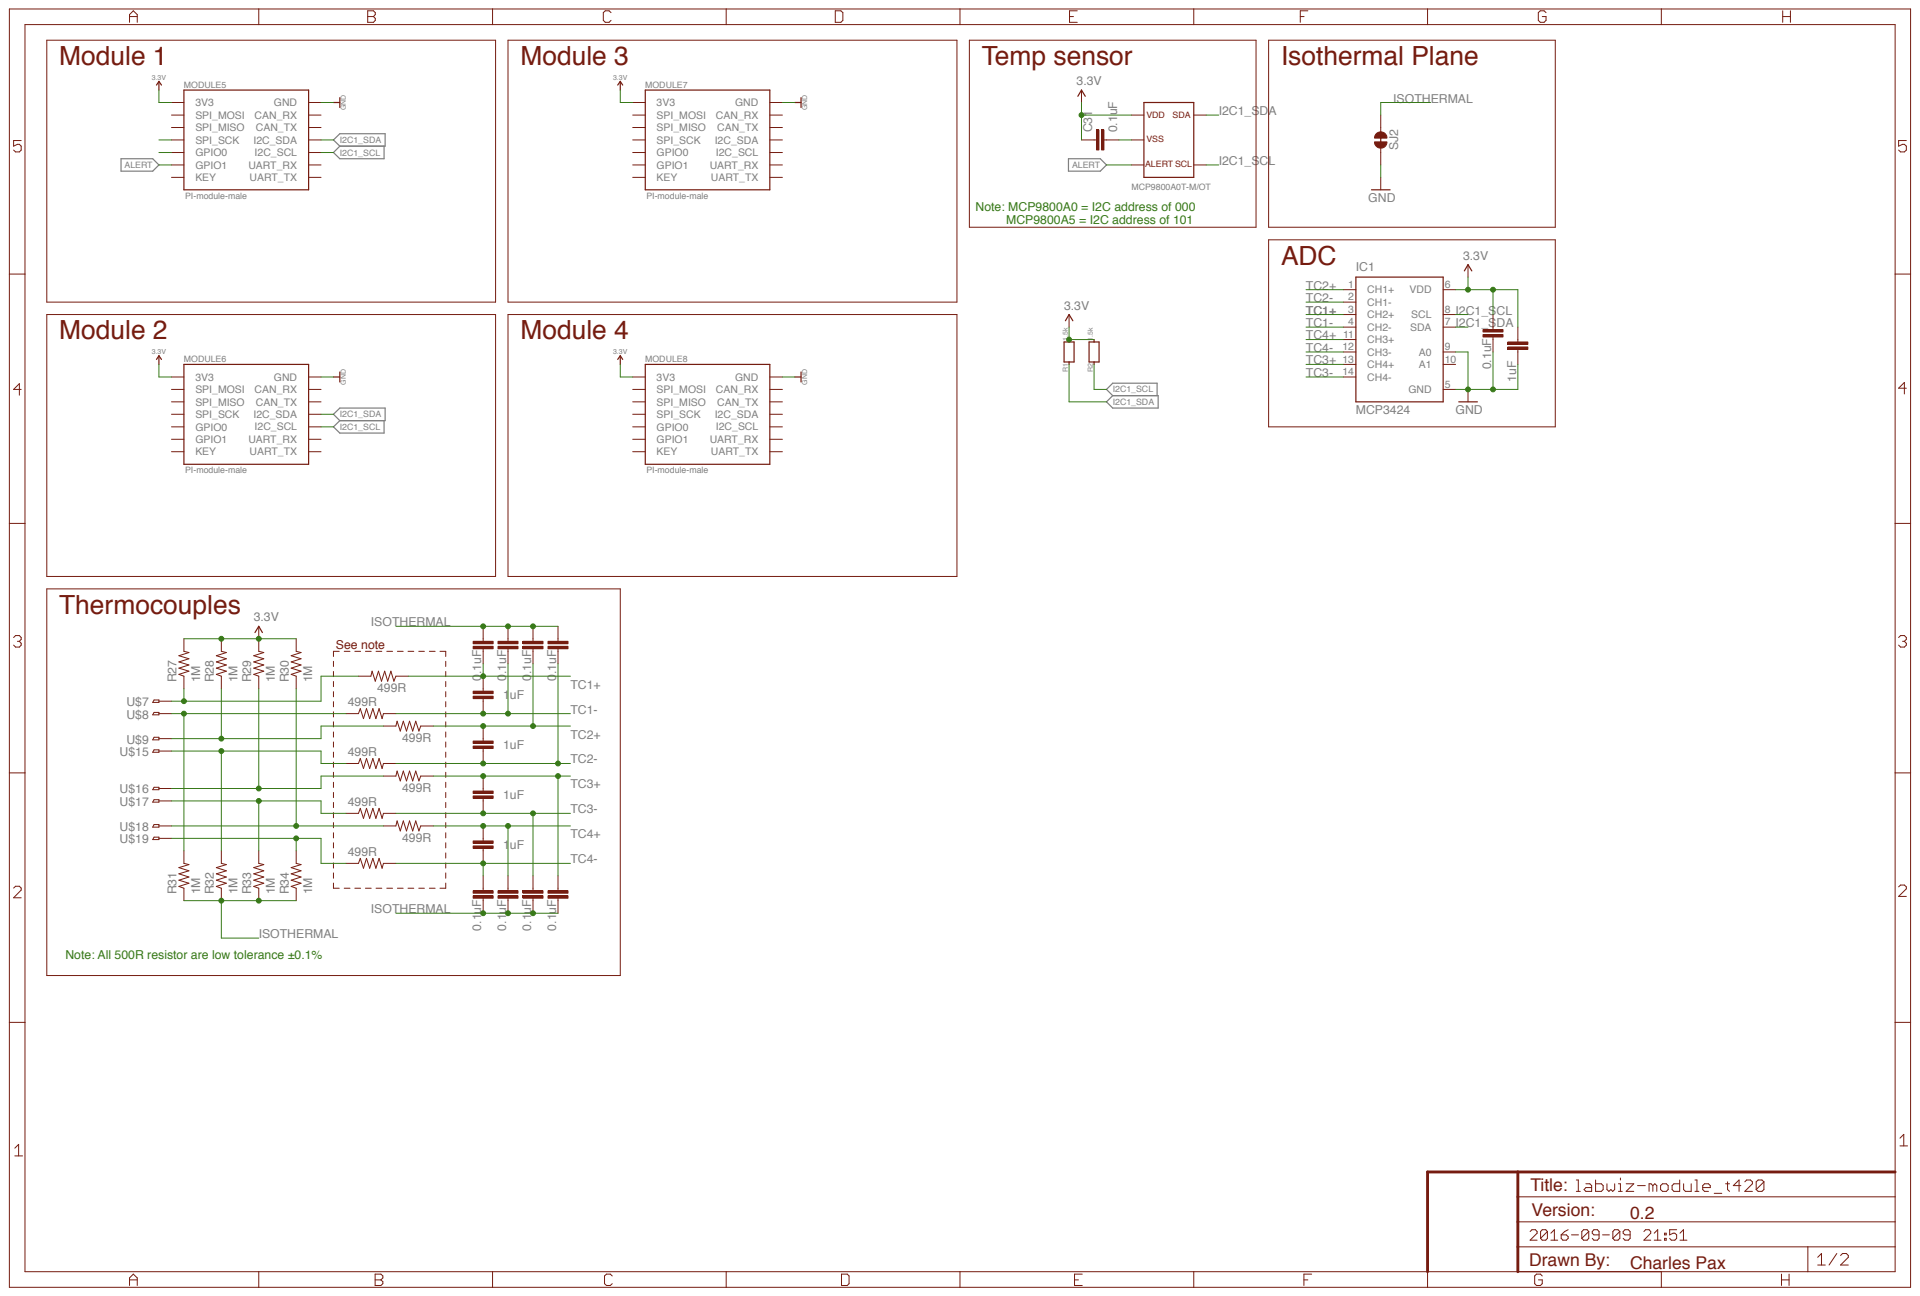
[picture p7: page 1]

Note: All 500R resistor are low tolerance ±0.1%

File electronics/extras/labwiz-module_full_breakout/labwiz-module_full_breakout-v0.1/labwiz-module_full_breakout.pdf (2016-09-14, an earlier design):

# Module 1

# Module 3

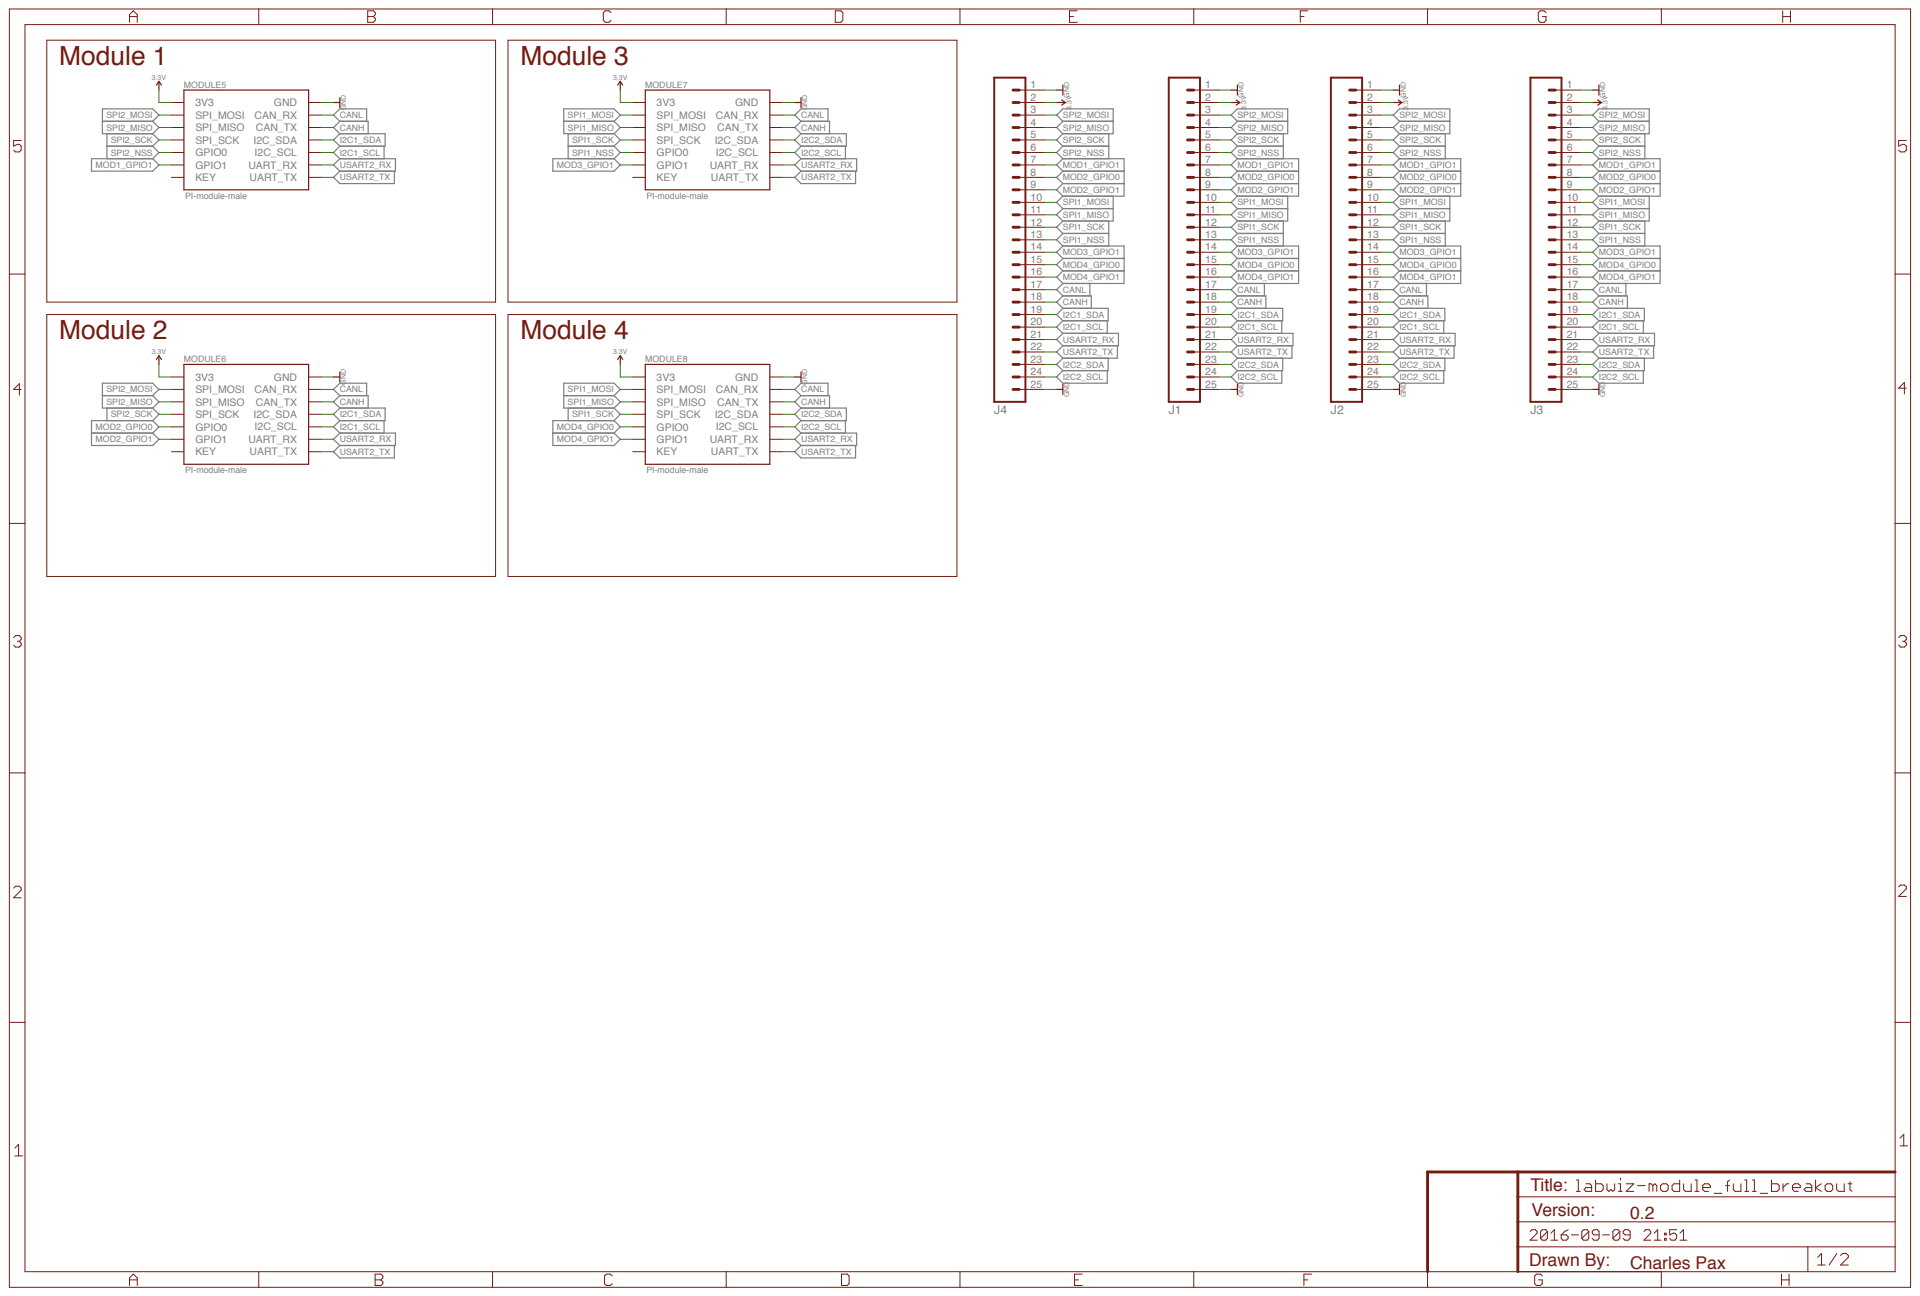
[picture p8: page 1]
GND; GND GND; 3.3VGND GND; SPI_MOSI; UART_RX; SPI_MISO; CAN_RX; SPI_SCK; CAN_TX; GPIO0; I2C_SDA; GPIO1; I2C_SCL; KEY; UART_TX; MODULE5; MODULE6; MODULE7; MODULE8; SPI2_NSS; MOD2_GPIO0; MOD2_GPIO1; SPI1_MOSI; SPI1_MISO; SPI1_NSS; I2C1_SDA; I2C1_SCL; USART2_RX; I2C2_SDA; I2C2_SCL; CANL; SPI2_MOSI; SPI2_MISO; SPI2_SCK; MOD1_GPIO1; SPI1_SCK; MOD3_GPIO1; MOD4_GPIO1; MOD4_GPIO0; CANH; USART2_TX; Charles Pax; Module 2; Module 4; Drawn By:; Title: Version:

PI-module-male

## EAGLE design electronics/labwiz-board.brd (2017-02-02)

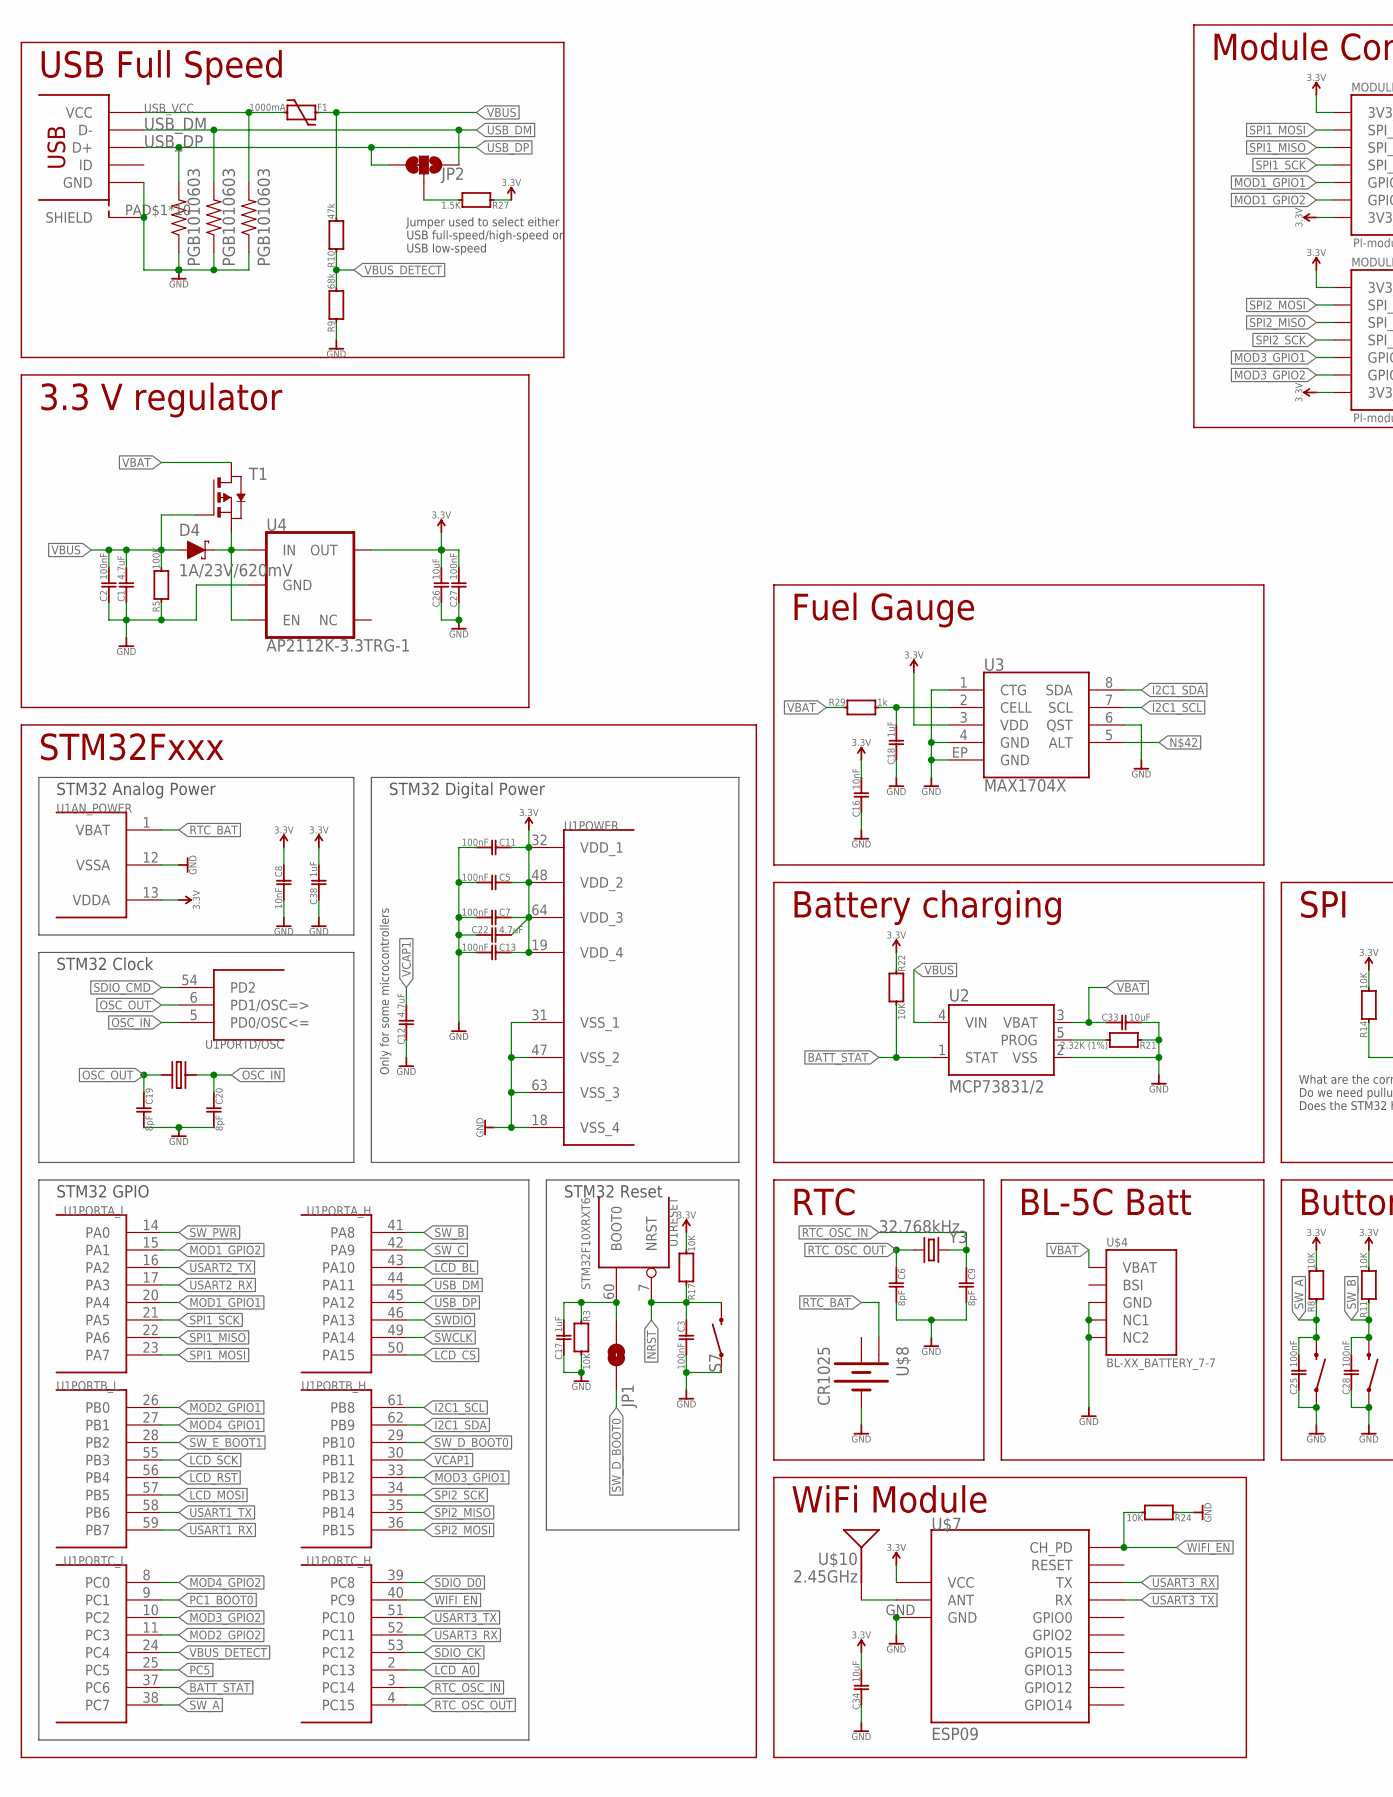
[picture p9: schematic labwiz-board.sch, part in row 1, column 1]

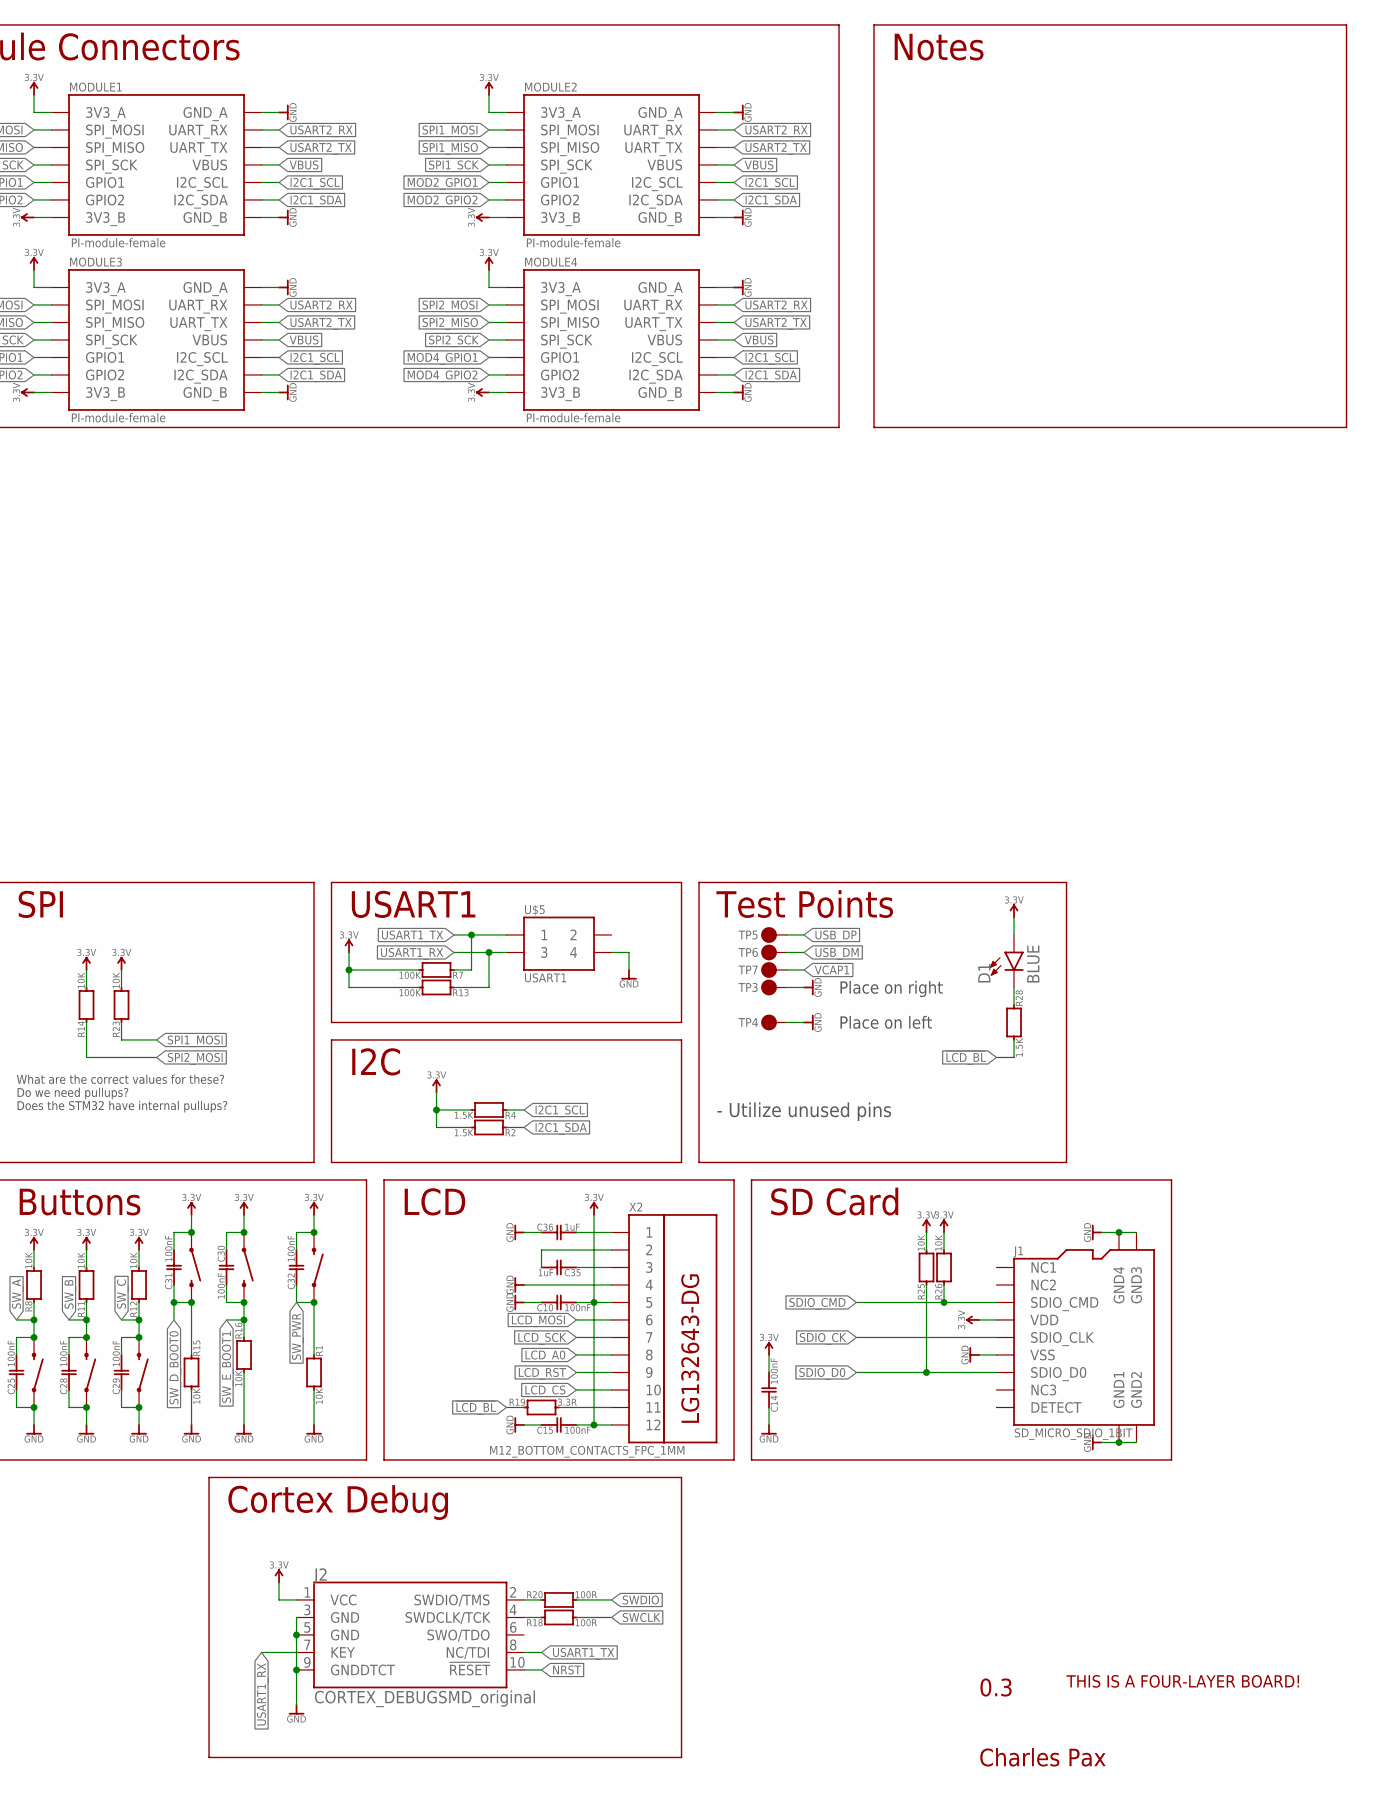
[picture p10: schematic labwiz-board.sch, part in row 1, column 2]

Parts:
C1, C12, C22: 4.7uF; 0402
C2, C3, C5, C7, C10, C11, C13, C14, C15, C25, C27, C28, C29, C30, C31, C32: 100nF; 0402
C6, C9, C19, C20: 8pF; 0402
C8, C16: 10nF; 0402
C17, C18, C35, C36, C38: 1uF; 0402
C26, C33, C34: 10uF; 0402
D1: BLUE; LED-0603
D4: 1A/23V/620mV; SOD-323
F1: 1000mA; 0805
J1: SD_MICRO_SDIO_1BIT; SD_MICRO_1
J2: CORTEX_DEBUGSMD_original; SAMTECH_FTSH-105-01
JP1: DNP; PAD-JUMPER-2-NO_YES_SILK
JP2: JUMPER-SMT_3_1-NC_TRACE_SILK; SMT-JUMPER_3_1-NC_TRACE_SILK
MODULE1, MODULE2, MODULE3, MODULE4: PI-module-female; M07X2_2MM_EDGE
R1, R3, R8, R11, R12, R14, R15, R16, R17, R22, R23, R24, R25, R26: 10K; 0402
R2, R4, R27, R28: 1.5K; 0402
R5, R7, R13: 100K; 0402
R9: 68k; 0402
R10: 47k; 0402
R18, R20: 100R; 0402
R19: 3.3R; 0402
R21: 2.32K (1%); 0402
R29: 1k; 0402
S1, S2, S3, S4, S5, S6: SWITCH-MOMENTARY-2SMD; TACTILE_SWITCH_SMD; MPN RS-187R05A2-DS MT RT
S7: SWITCH-MOMENTARY-2SMD-3; TACTILE_SWITCH_SMD-3
T1: PMOSSOT23-6; SOT23-6
TP3, TP4: DNP; M01_TH
TP5, TP6, TP7: DNP; PAD_1MM
U1: STM32F10XRXT6; TQFP64
U2: MCP73831/2; SOT23-5
U3: MAX1704X; TDFN-8
U4: AP2112K-3.3TRG-1; SOT23-5
U$1: USB_MICROSMT+THRUHULE; USB_MICRO_THRUHOLE; MPN 10118194-0001LF
U$2: DNP; FOUR_LAYER_WARNING
U$3: LG132643-DG
U$4: BL-XX_BATTERY_7-7; BL-XX-BATTERY
U$5: USART1; M02X2_TH_RIGHT_ANGLE
U$7: ESP09
U$8: CR1025; CR2025
U$9: 8MHz; NX3225GD
U$10: 2.45GHz; ANT-2.4GHZ-6.5X2.2MM
X2: M12_BOTTOM_CONTACTS_FPC_1MM; FPC_12P_1MM
Y3: 32.768kHz; CRYSTAL-SMD-3.2X1.5MM
Z1, Z2, Z3: PGB1010603; SPARKFUN-RESISTORS_0603-RES; MPN PGB1010603NRHF

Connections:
3.3V: C5.1, C7.1, C8.1, C10.2, C11.1, C13.1, C14.2, C15.2, C16.2, C22.2, C26.2, C27.2, C30.1, C31.2, C32.2, C34.2, C38.2, D1.A, J1.4 (VDD), J2.1 (VCC), MODULE1.P$1 (3V3_A), MODULE1.P$13 (3V3_B), MODULE2.P$1 (3V3_A), MODULE2.P$13 (3V3_B), MODULE3.P$1 (3V3_A), MODULE3.P$13 (3V3_B), MODULE4.P$1 (3V3_A), MODULE4.P$13 (3V3_B), R2.1, R4.1, R7.1, R8.1, R11.1, R12.1, R13.1, R14.1, R17.1, R22.2, R23.1, R25.1, R26.1, R27.2, S4.1, S5.1, S6.3 (2), U1.13 (VDDA), U1.19 (VDD_4), U1.32 (VDD_1), U1.48 (VDD_2), U1.64 (VDD_3), U3.3 (VDD), U4.5 (OUT), U$7.VCC, X2.5, X2.12
!LCD_BL: R19.2, R28.1, U1.43 (PA10)
+: U$8.P$2 (+)
BATT_STAT: R22.1, U1.37 (PC6), U2.1 (STAT)
GND: C1.1, C2.1, C3.2, C5.2, C6.2, C7.2, C8.2, C9.2, C10.1, C11.2, C12.1, C13.2, C14.1, C15.1, C16.1, C17.1, C18.1, C19.2, C20.2, C22.1, C25.1, C26.1, C27.1, C28.1, C29.1, C33.2, C34.1, C36.1, C38.1, J1.6 (VSS), J1.G1 (GND1), J1.G2 (GND2), J1.G3 (GND3), J1.G4 (GND4), J2.3 (GND), J2.5 (GND), J2.9 (GNDDTCT), MODULE1.P$2 (GND_A), MODULE1.P$14 (GND_B), MODULE2.P$2 (GND_A), MODULE2.P$14 (GND_B), MODULE3.P$2 (GND_A), MODULE3.P$14 (GND_B), MODULE4.P$2 (GND_A), MODULE4.P$14 (GND_B), R1.1, R3.1, R5.2, R9.2, R15.1, R16.1, R21.2, R24.2, S1.1, S2.1, S3.1, S7.1, TP3.P$1, TP4.P$1, U1.12 (VSSA), U1.18 (VSS_4), U1.31 (VSS_1), U1.47 (VSS_2), U1.63 (VSS_3), U2.2 (VSS), U3.1 (CTG), U3.4 (GND), U3.6 (QST), U3.EP (GND), U4.2 (GND), U$1.PAD$1 (SHIELD), U$1.PAD$2 (SHIELD), U$1.PAD$3 (SHIELD), U$1.PAD$4 (SHIELD), U$1.PAD$5 (SHIELD), U$1.PAD$6 (SHIELD), U$1.PAD$7 (SHIELD), U$1.PAD$8 (SHIELD), U$1.PAD$9 (SHIELD), U$1.PAD$10 (SHIELD), U$1.PIN$5 (GND), U$4.P$3 (GND), U$4.P$4 (NC1), U$4.P$5 (NC2), U$5.4, U$7.GND, U$7.GND1, U$7.GND2, U$7.GND3, U$7.GND4, U$7.GND5, U$7.GND6, U$7.GND7, U$8.P$1 (-), X2.4, Z1.1, Z2.1, Z3.1
I2C1_SCL: MODULE1.P$10 (I2C_SCL), MODULE2.P$10 (I2C_SCL), MODULE3.P$10 (I2C_SCL), MODULE4.P$10 (I2C_SCL), R4.2, U1.61 (PB8), U3.7 (SCL)
I2C1_SDA: MODULE1.P$12 (I2C_SDA), MODULE2.P$12 (I2C_SDA), MODULE3.P$12 (I2C_SDA), MODULE4.P$12 (I2C_SDA), R2.2, U1.62 (PB9), U3.8 (SDA)
LCD_A0: U1.2 (PC13), X2.8
LCD_CS: U1.50 (PA15), X2.10
LCD_MOSI: U1.57 (PB5), X2.6
LCD_RST: U1.56 (PB4), X2.9
LCD_SCK: U1.55 (PB3), X2.7
MOD1_GPIO1: MODULE1.P$9 (GPIO1), U1.20 (PA4)
MOD1_GPIO2: MODULE1.P$11 (GPIO2), U1.15 (PA1)
MOD2_GPIO1: MODULE2.P$9 (GPIO1), U1.26 (PB0)
MOD2_GPIO2: MODULE2.P$11 (GPIO2), U1.11 (PC3)
MOD3_GPIO1: MODULE3.P$9 (GPIO1), U1.33 (PB12)
MOD3_GPIO2: MODULE3.P$11 (GPIO2), U1.10 (PC2)
MOD4_GPIO1: MODULE4.P$9 (GPIO1), U1.27 (PB1)
MOD4_GPIO2: MODULE4.P$11 (GPIO2), U1.8 (PC0)
unnamed: R19.1, X2.11
unnamed: JP2.2, R27.1
unnamed: U$7.ANT, U$10.FEED
unnamed: C18.2, R29.1, U3.2 (CELL)
unnamed: D1.C, R28.2
unnamed: D4.C, T1.4 (S), U4.1 (IN), U4.3 (EN)
unnamed: C35.1, X2.3
unnamed: C35.2, X2.2
unnamed: C36.2, X2.1
unnamed: R21.1, U2.5 (PROG)
NRST: C3.1, J2.10 (!RESET), R17.2, S7.4 (2), U1.7 (NRST)
OSC_IN: C20.1, U1.5 (PD0/OSC<=), U$9.P$2
OSC_OUT: C19.1, U1.6 (PD1/OSC=>), U$9.P$1
PC1_BOOT0: C17.2, JP1.2, R3.2, U1.9 (PC1), U1.60 (BOOT0)
PC5: U1.25 (PC5)
RTC_BAT: U1.1 (VBAT), U$8.P$3 (+1)
RTC_OSC_IN: C9.1, U1.3 (PC14), Y3.P$2 (2)
RTC_OSC_OUT: C6.1, U1.4 (PC15), Y3.P$1 (1)
SDIO_CK: J1.5 (SDIO_CLK), U1.53 (PC12)
SDIO_CMD: J1.3 (SDIO_CMD), R26.2, U1.54 (PD2)
SDIO_D0: J1.7 (SDIO_D0), R25.2, U1.39 (PC8)
SPI1_MISO: MODULE1.P$5 (SPI_MISO), MODULE2.P$5 (SPI_MISO), U1.22 (PA6)
SPI1_MOSI: MODULE1.P$3 (SPI_MOSI), MODULE2.P$3 (SPI_MOSI), R23.2, U1.23 (PA7)
SPI1_SCK: MODULE1.P$7 (SPI_SCK), MODULE2.P$7 (SPI_SCK), U1.21 (PA5)
SPI2_MISO: MODULE3.P$5 (SPI_MISO), MODULE4.P$5 (SPI_MISO), U1.35 (PB14)
SPI2_MOSI: MODULE3.P$3 (SPI_MOSI), MODULE4.P$3 (SPI_MOSI), R14.2, U1.36 (PB15)
SPI2_SCK: MODULE3.P$7 (SPI_SCK), MODULE4.P$7 (SPI_SCK), U1.34 (PB13)
SWCLK: R18.1, U1.49 (PA14)
SWDCLK_M: J2.4 (SWDCLK/TCK), R18.2
SWDIO: R20.1, U1.46 (PA13)
SWDIO_M: J2.2 (SWDIO/TMS), R20.2
SW_A: C25.2, R8.2, S3.3 (2), U1.38 (PC7)
SW_B: C28.2, R11.2, S2.3 (2), U1.41 (PA8)
SW_C: C29.2, R12.2, S1.3 (2), U1.42 (PA9)
SW_D_BOOT0: C31.1, JP1.1, R15.2, S4.3 (2), U1.29 (PB10)
SW_E_BOOT1: C30.2, R16.2, S5.3 (2), U1.28 (PB2)
SW_PWR: C32.1, R1.2, S6.1, U1.14 (PA0)
USART1_RX: J2.7 (KEY), R13.2, U1.59 (PB7), U$5.3
USART1_TX: J2.8 (NC/TDI), R7.2, U1.58 (PB6), U$5.1
USART2_RX: MODULE1.P$4 (UART_RX), MODULE2.P$4 (UART_RX), MODULE3.P$4 (UART_RX), MODULE4.P$4 (UART_RX), U1.17 (PA3)
USART2_TX: MODULE1.P$6 (UART_TX), MODULE2.P$6 (UART_TX), MODULE3.P$6 (UART_TX), MODULE4.P$6 (UART_TX), U1.16 (PA2)
USART3_RX: U1.52 (PC11), U$7.TX
USART3_TX: U1.51 (PC10), U$7.RX
USB_DM: JP2.1, TP6.P$1, U1.44 (PA11), U$1.PIN$2 (D-), Z2.2
USB_DP: JP2.3, TP5.P$1, U1.45 (PA12), U$1.PIN$3 (D+), Z1.2
USB_VCC: F1.1, U$1.PIN$1 (VCC), Z3.2
VBAT: C33.1, R29.2, T1.1 (D), T1.2 (D), T1.5 (D), T1.6 (D), U2.3 (VBAT), U$4.P$1 (VBAT)
VBUS: C1.2, C2.2, D4.A, F1.2, MODULE1.P$8 (VBUS), MODULE2.P$8 (VBUS), MODULE3.P$8 (VBUS), MODULE4.P$8 (VBUS), R5.1, R10.1, T1.3 (G), U2.4 (VIN)
VBUS_DETECT: R9.1, R10.2, U1.24 (PC4)
VCAP1: C12.2, TP7.P$1, U1.30 (PB11)
WIFI_EN: R24.1, U1.40 (PC9), U$7.CH_PD

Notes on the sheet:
USB Full Speed
3.3 V regulator
LCD
Buttons
0.3
Charles Pax
SD Card
STM32 Digital Power
STM32 Analog Power
STM32 Clock
STM32 Reset
STM32Fxxx
STM32 GPIO
RTC
Module Connectors
BL-5C Batt
Cortex Debug
WiFi Module
Battery charging
USART1
Notes
- Utilize unused pins
Only for some microcontrollers
I2C
Test Points
Place on left
Place on right
Jumper used to select either USB full-speed/high-speed or USB low-speed
SPI
What are the correct values for these? Do we need pullups? Does the STM32 have internal pullups?
Fuel Gauge

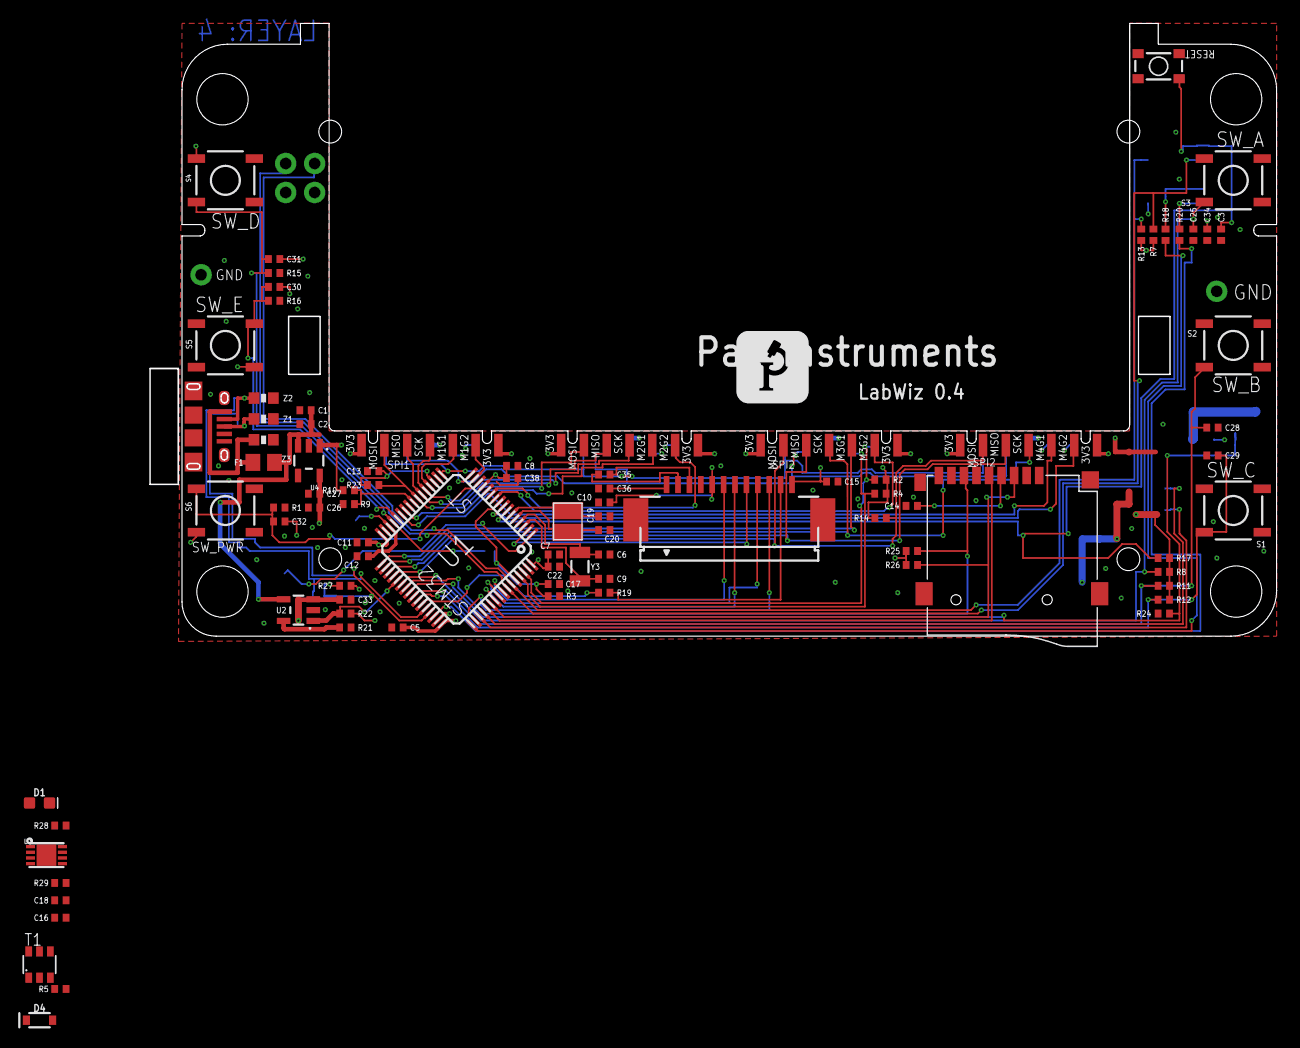
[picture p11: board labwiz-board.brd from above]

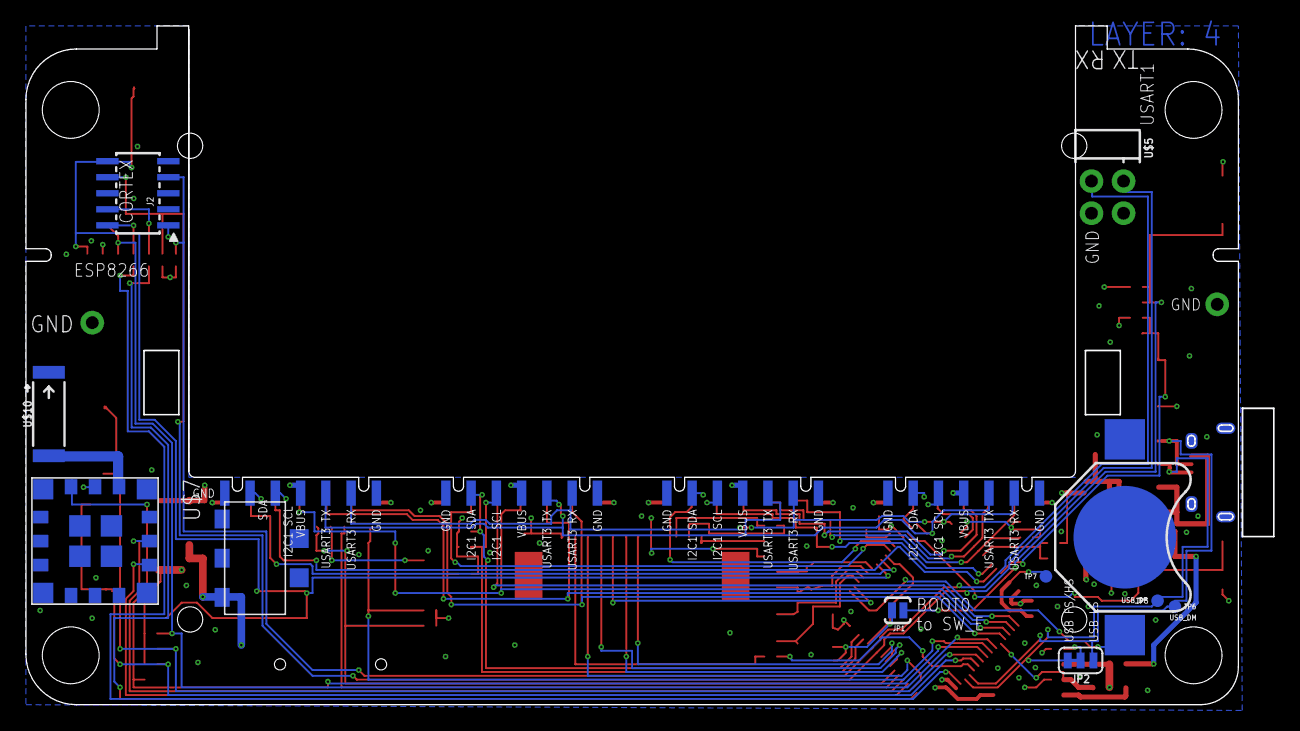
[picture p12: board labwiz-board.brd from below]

Board: 4 copper layers, 98.8 x 53.7 mm, 104 parts (11 on the bottom side), 69 nets.

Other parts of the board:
U$6: PAX-LOGO-0.25IN

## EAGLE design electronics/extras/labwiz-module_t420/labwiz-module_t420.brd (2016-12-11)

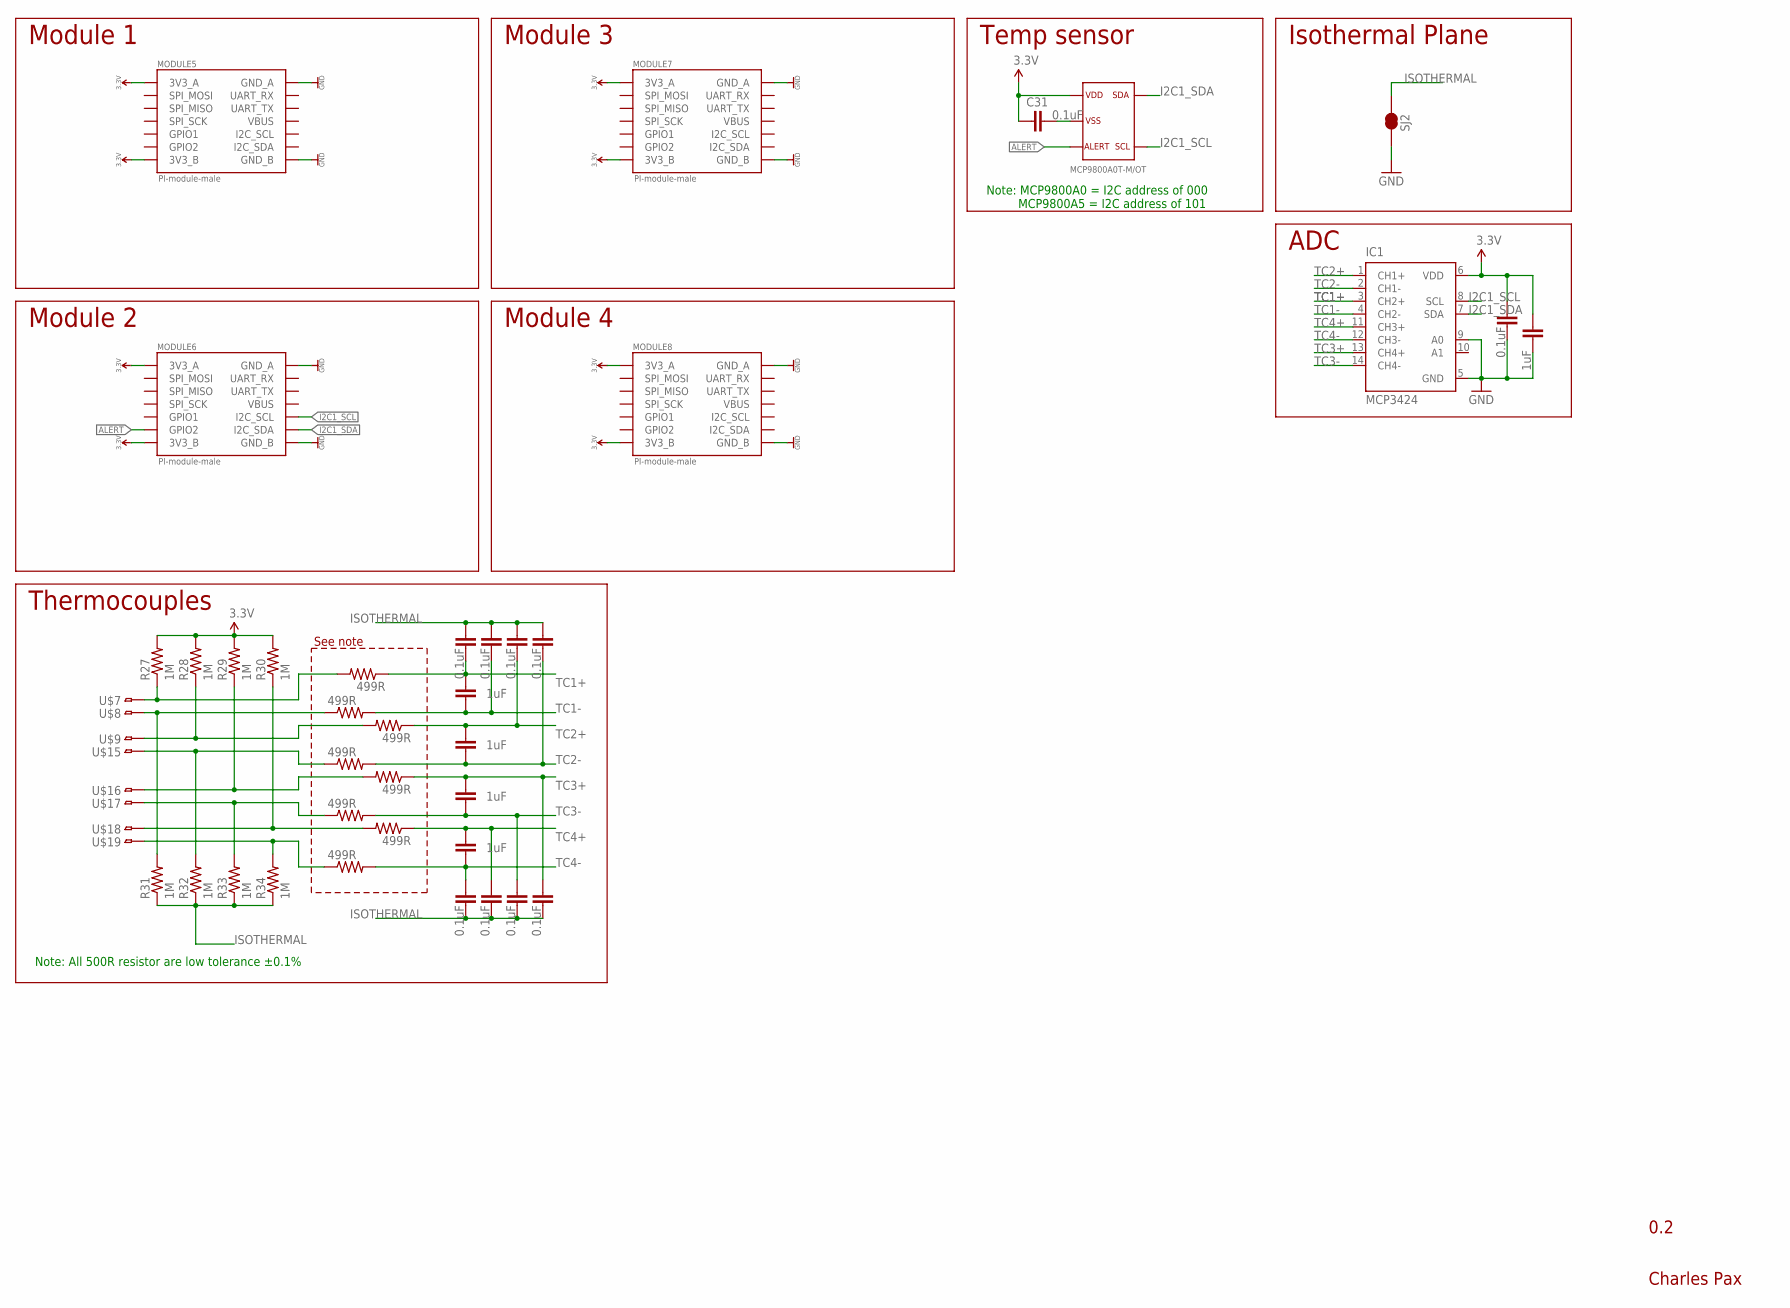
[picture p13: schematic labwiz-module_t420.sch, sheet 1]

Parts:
C7, C8, C10, C11, C30: 1uF; SPARKFUN-CAPACITORS_0603-CAP
C13, C14, C15, C16, C17, C24, C25, C29, C31, C37: 0.1uF; SPARKFUN-CAPACITORS_0603-CAP
IC1: MCP3424; SO14; MPN MCP3424-E/SL
MODULE5, MODULE6, MODULE7, MODULE8: PI-module-male; M07X2_2MM_EDGE
R27, R28, R29, R30, R31, R32, R33, R34: 1M; SPARKFUN-RESISTORS_0603-RES
R35, R36, R37, R38, R39, R40, R41, R42: 499R; SPARKFUN-RESISTORS_0603-RES; MPN TNPW0603499RBEEA
SJ2: JUMPER-PAD-2-NC_BY_TRACE; PAD-JUMPER-2-NC_BY_TRACE_YES_SILK; MPN N/A
U1: MCP9800; SOT23-5L; MPN MCP9800A0T-M/OT
U$7, U$8, U$9, U$15, U$16, U$17, U$18, U$19: TC-MINI-SINGLE; TC-CLIP-SINGLE

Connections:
3.3V: C29.1, C30.1, C31.1, IC1.6 (VDD), MODULE5.P$1 (3V3_B), MODULE5.P$13 (3V3_A), MODULE6.P$1 (3V3_B), MODULE6.P$13 (3V3_A), MODULE7.P$1 (3V3_B), MODULE7.P$13 (3V3_A), MODULE8.P$1 (3V3_B), MODULE8.P$13 (3V3_A), R27.2, R28.2, R29.2, R30.2, U1.1
ALERT: MODULE6.P$3 (GPIO2), U1.3
GND: C29.2, C30.2, IC1.5 (GND), IC1.9 (A0), MODULE5.P$2 (GND_B), MODULE5.P$14 (GND_A), MODULE6.P$2 (GND_B), MODULE6.P$14 (GND_A), MODULE7.P$2 (GND_B), MODULE7.P$14 (GND_A), MODULE8.P$2 (GND_B), MODULE8.P$14 (GND_A), SJ2.1
I2C1_SCL: IC1.8 (SCL), MODULE6.P$6 (I2C_SCL), U1.4
I2C1_SDA: IC1.7 (SDA), MODULE6.P$4 (I2C_SDA), U1.5
ISOTHERMAL: C13.2, C14.2, C15.2, C16.2, C17.1, C24.1, C25.1, C31.2, C37.1, R31.1, R32.1, R33.1, R34.1, SJ2.2, U1.2
unnamed: R27.1, R35.2, U$7.P$1
unnamed: R32.2, R38.1, U$15.P$1
unnamed: R31.2, R36.1, U$8.P$1
unnamed: R28.1, R37.2, U$9.P$1
unnamed: R30.1, R40.2, U$18.P$1
unnamed: R29.1, R39.2, U$16.P$1
unnamed: R33.2, R41.1, U$17.P$1
unnamed: R34.2, R42.1, U$19.P$1
TC1+: C7.1, C17.2, IC1.3 (CH2+), R35.1
TC1-: C7.2, C24.2, IC1.4 (CH2-), R36.2
TC2+: C8.1, C25.2, IC1.1 (CH1+), R37.1
TC2-: C8.2, C37.2, IC1.2 (CH1-), R38.2
TC3+: C10.1, C16.1, IC1.13 (CH4+), R39.1
TC3-: C10.2, C15.1, IC1.14 (CH4-), R41.2
TC4+: C11.1, C14.1, IC1.11 (CH3+), R40.1
TC4-: C11.2, C13.1, IC1.12 (CH3-), R42.2

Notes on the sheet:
0.2
Charles Pax
Module 1
Module 2
Module 3
Module 4
Temp sensor
Note: MCP9800A0 = I2C address of 000 MCP9800A5 = I2C address of 101
ADC
Isothermal Plane
Thermocouples
Note: All 500R resistor are low tolerance ±0.1%
See note

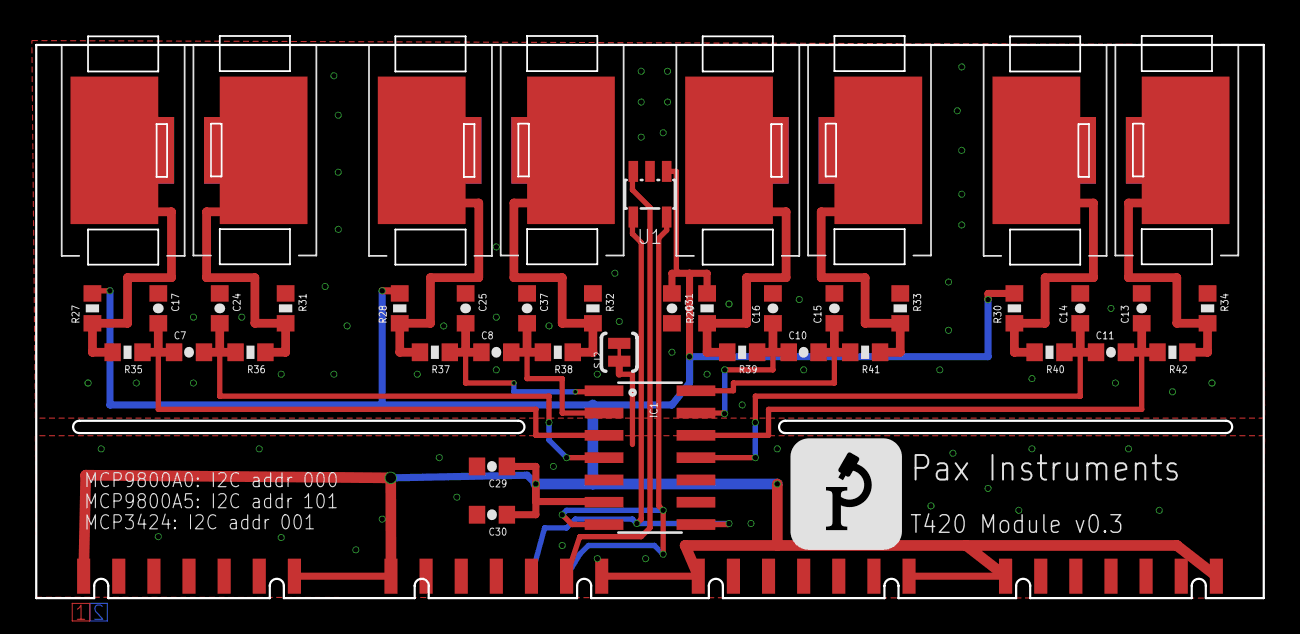
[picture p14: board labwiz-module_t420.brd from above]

Board: 4 copper layers, 69.9 x 32.0 mm, 48 parts (0 on the bottom side), 22 nets.

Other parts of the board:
U$1: PAX-LOGO-0.25IN
U$2: LAYERS-LABEL-2

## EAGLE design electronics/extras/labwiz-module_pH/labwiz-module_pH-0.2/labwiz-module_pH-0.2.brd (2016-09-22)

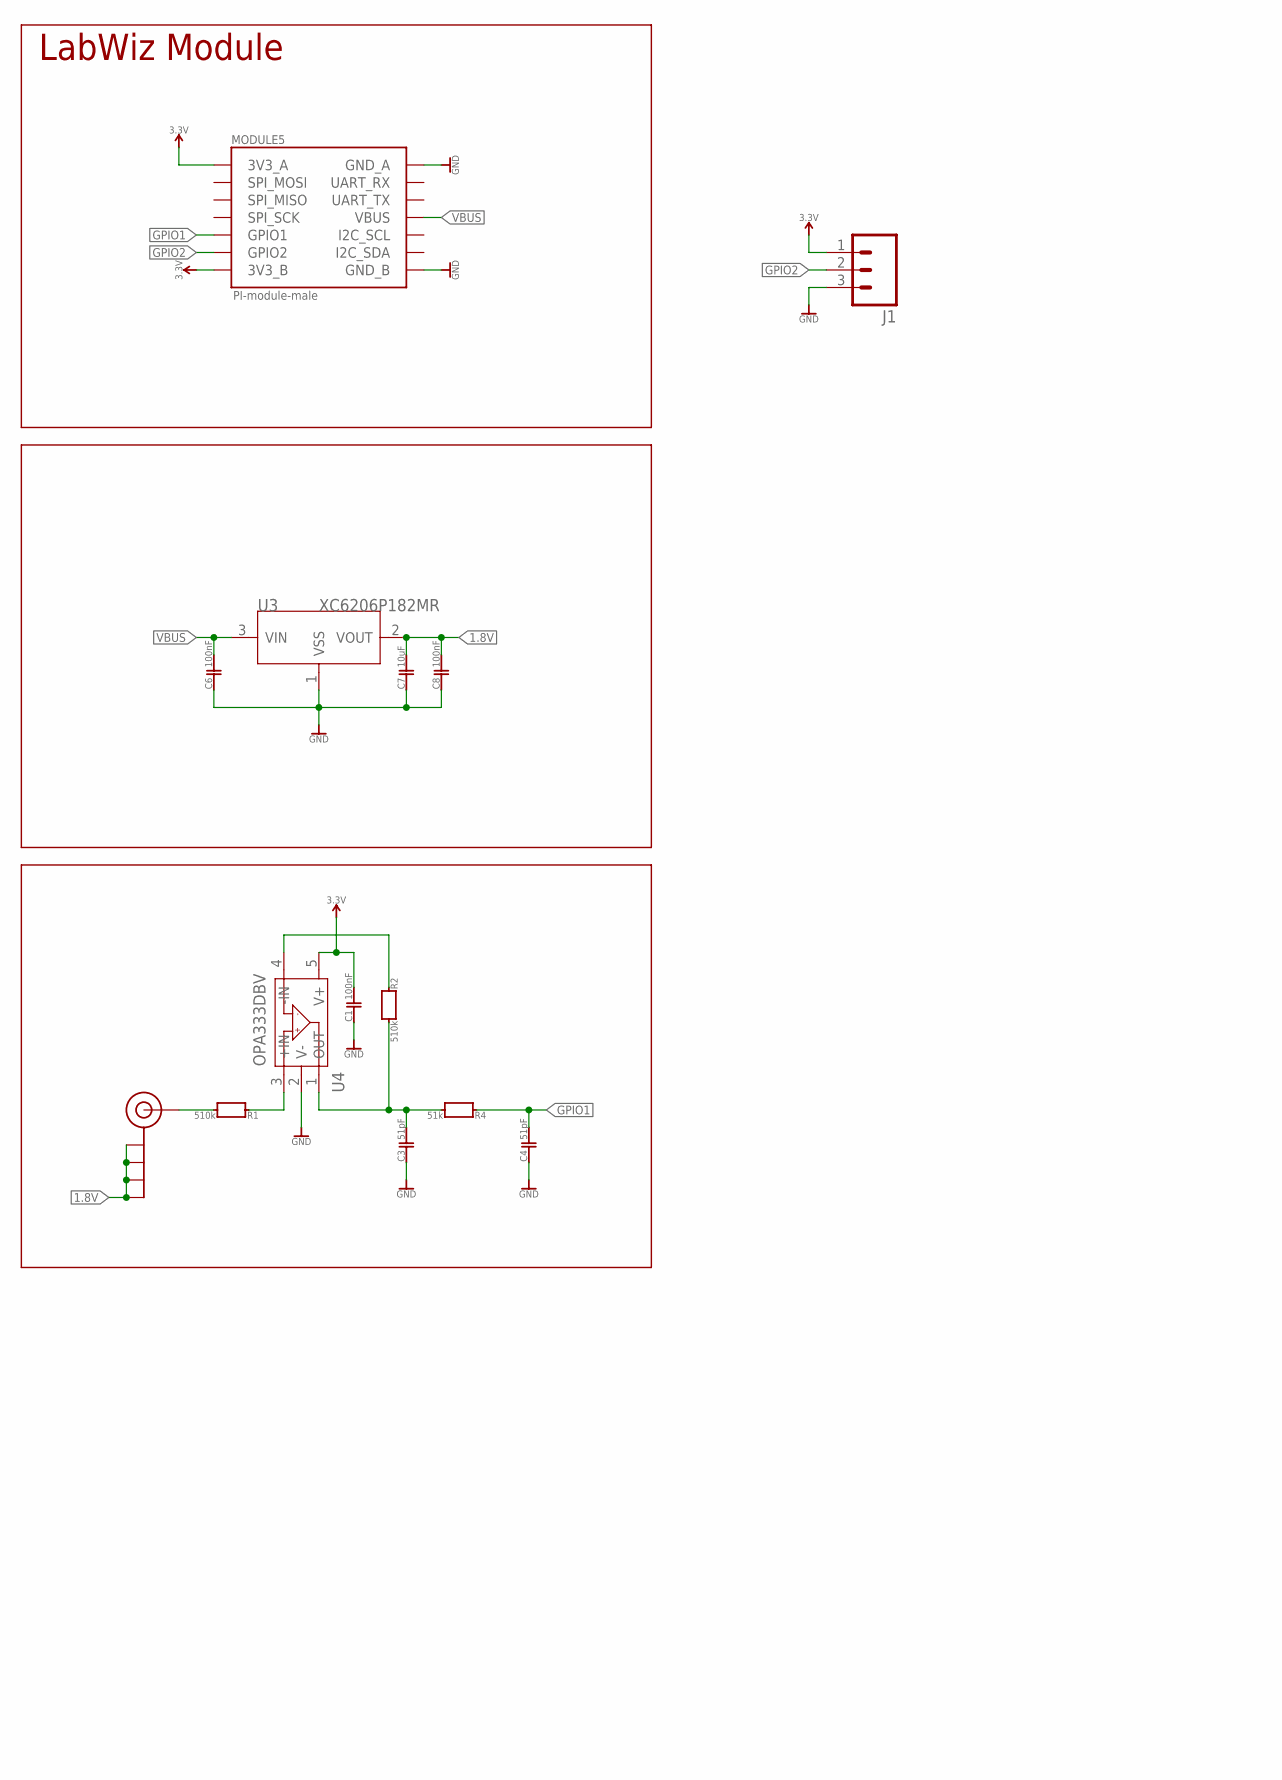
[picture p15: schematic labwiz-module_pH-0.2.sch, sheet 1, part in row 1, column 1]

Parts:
C1, C6, C8: 100nF; 0603
C3, C4: 51pF; 0603
C7: 10uF; 0603
J1: M03LOCK_LONGPADS; 1X03_LOCK_LONGPADS
J$1: SMA_EDGE; SMA-EDGE
MODULE5: PI-module-male; M07X2_2MM_EDGE
R1, R2: 510k; 0603
R4: 51k; 0603
U3: XC6206P182MR; SOT23
U4: OPA333DBV; SOT23-5

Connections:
1.8V: C7.2, C8.2, J$1.GND@0 (GND), J$1.GND@1 (GND), J$1.GND@2 (GND), J$1.GND@3 (GND), U3.2 (VOUT)
3.3V: C1.2, J1.1, MODULE5.P$1 (3V3_B), MODULE5.P$13 (3V3_A), U4.5 (V+)
GND: C1.1, C3.1, C4.1, C6.1, C7.1, C8.1, J1.3, MODULE5.P$2 (GND_B), MODULE5.P$14 (GND_A), U3.1 (VSS), U4.2 (V-)
GPIO1: C4.2, MODULE5.P$5 (GPIO1), R4.2
GPIO2: J1.2, MODULE5.P$3 (GPIO2)
unnamed: J$1.SIG (SIGNAL), R1.1
unnamed: R1.2, U4.3 (+IN)
unnamed: R2.2, U4.4 (-IN)
unnamed: C3.2, R2.1, R4.1, U4.1 (OUT)
VBUS: C6.2, MODULE5.P$8 (VBUS), U3.3 (VIN)

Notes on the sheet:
0.2
Charles Pax
LabWiz Module

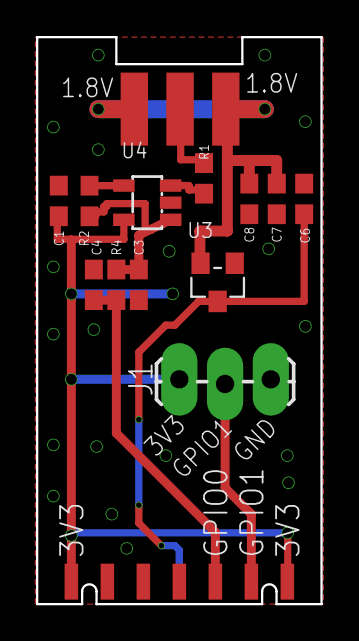
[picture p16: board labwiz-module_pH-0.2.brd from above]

Board: 4 copper layers, 15.8 x 31.5 mm, 14 parts (0 on the bottom side), 10 nets.

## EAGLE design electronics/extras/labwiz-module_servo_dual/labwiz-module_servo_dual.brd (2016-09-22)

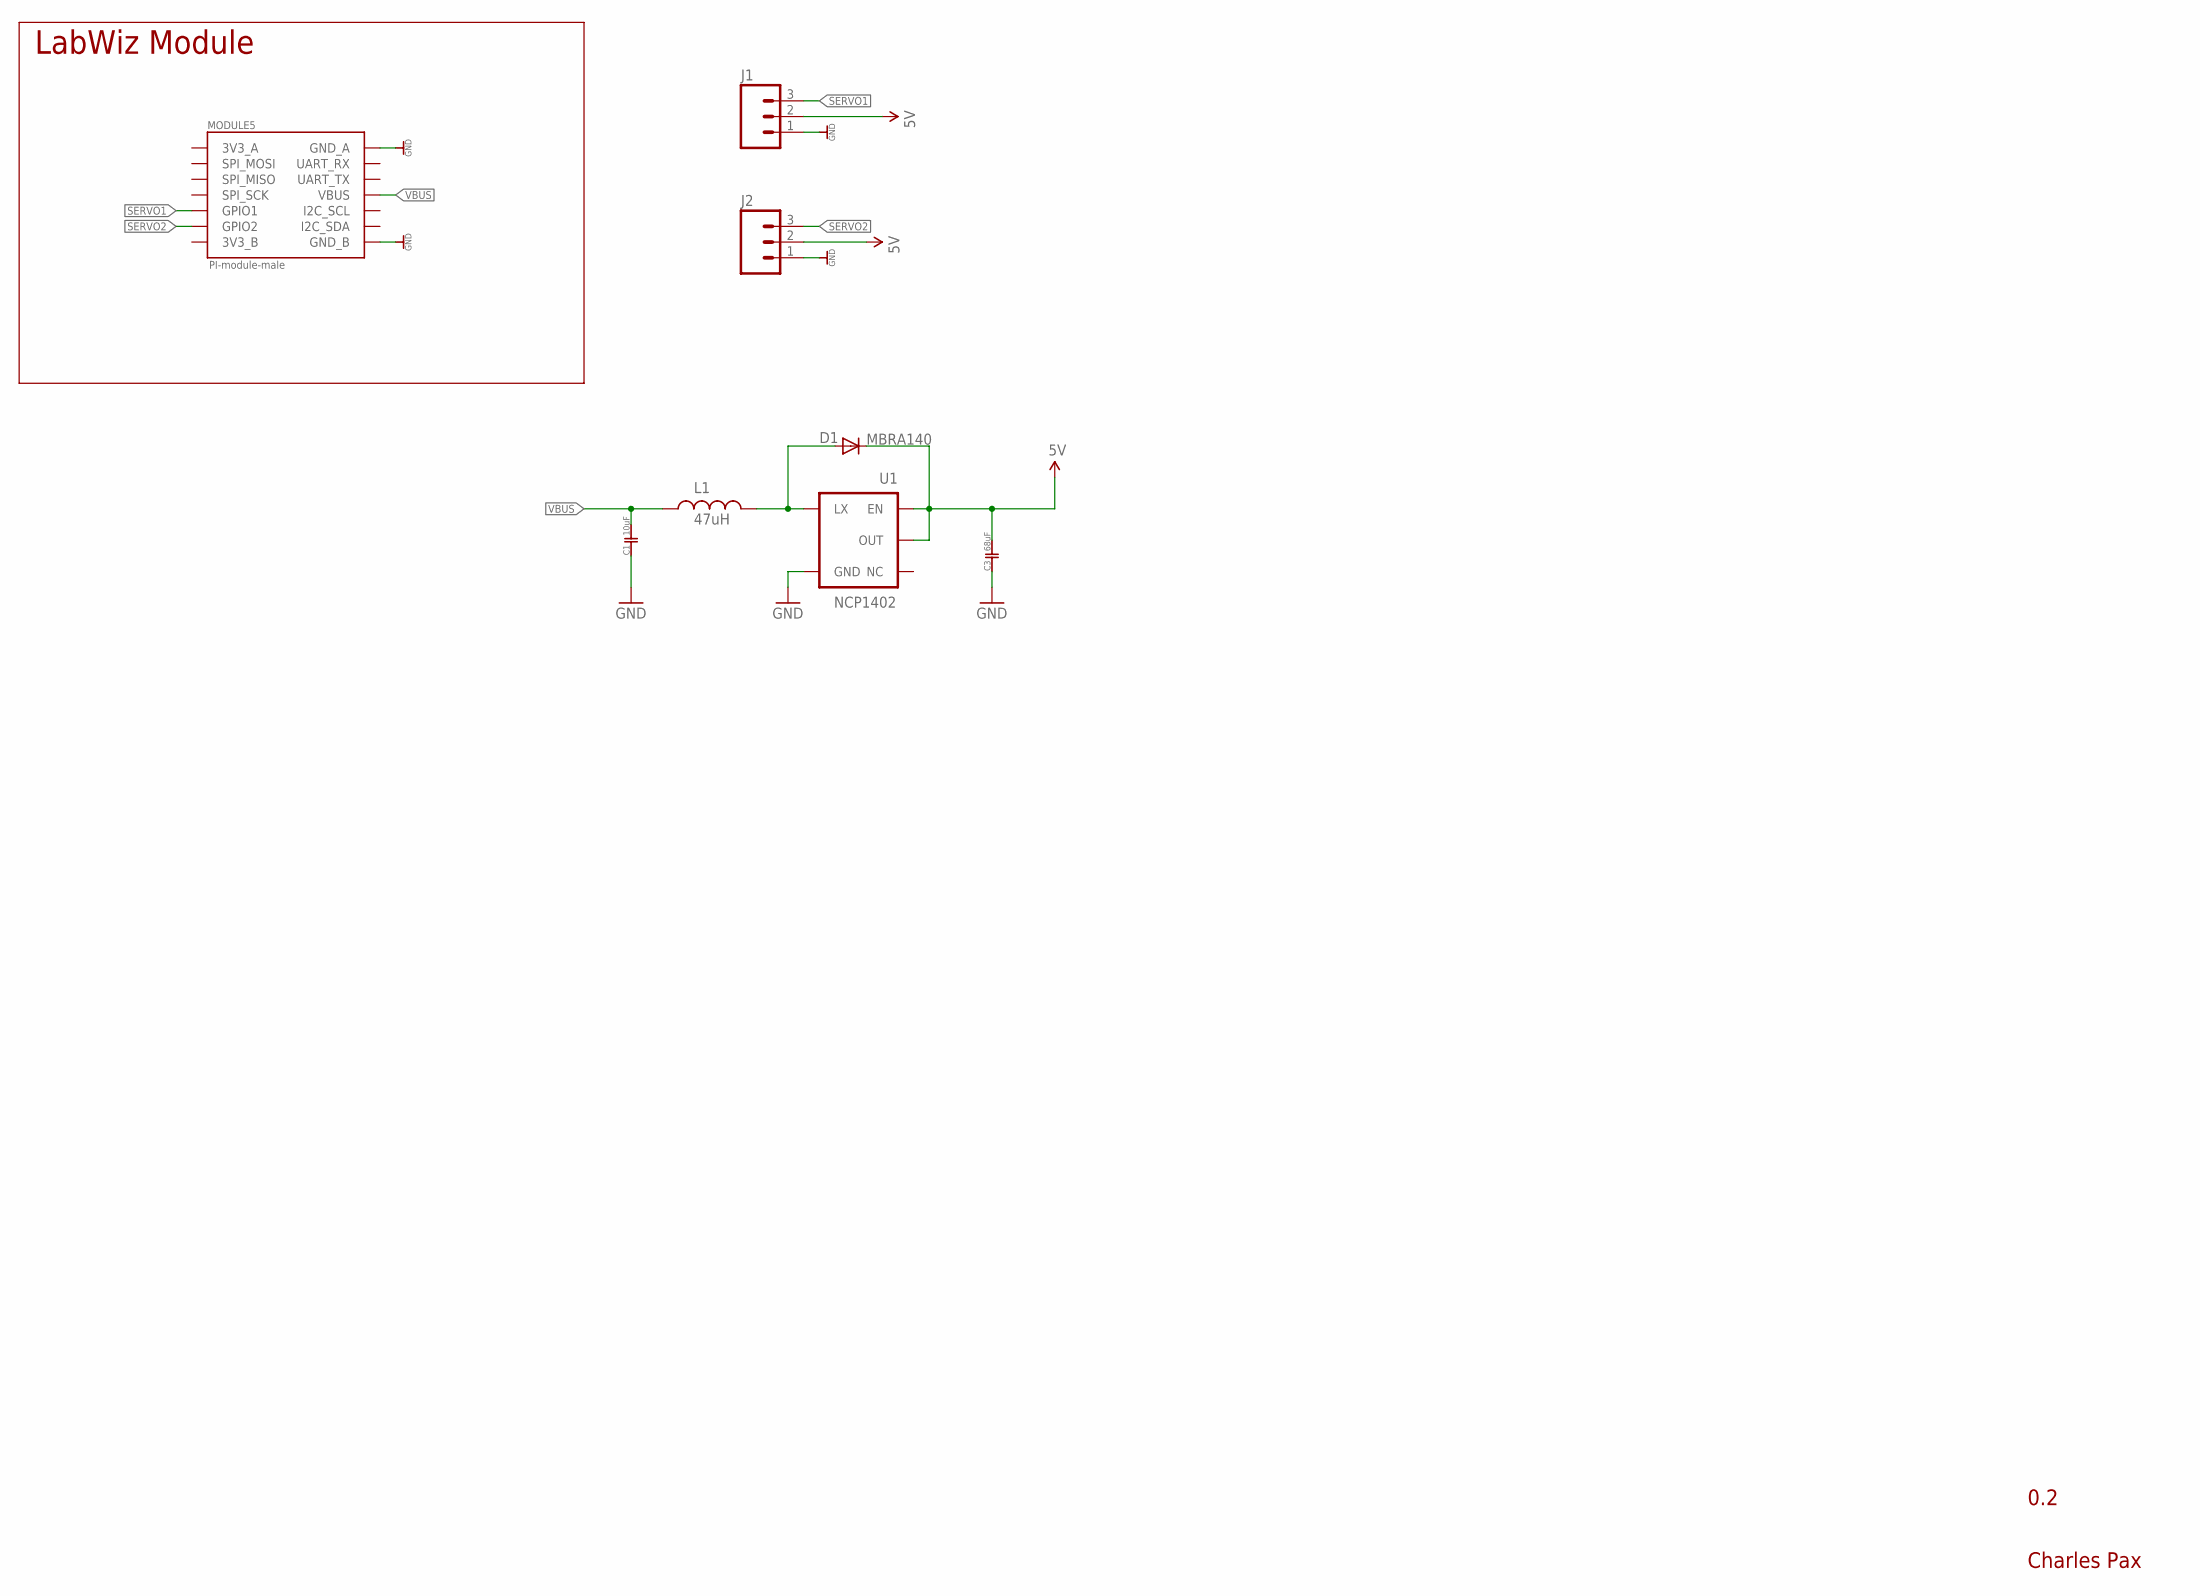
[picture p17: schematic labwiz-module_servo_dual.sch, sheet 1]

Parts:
C1: 10uF; 0603
C3: 68uF; 0603
D1: MBRA140; SMA-DIODE
J1, J2: M031X03_SMD_RA_MALE_POST_SMALLEST; 1X03_SMD_RA_MALE_POST_SMALLEST
L1: 47uH; CR54
MODULE5: PI-module-male; M07X2_2MM_EDGE
U1: NCP1402; SOT23-5

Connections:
3V3_A: MODULE5.P$13 (3V3_A)
5V: C3.2, D1.C, J1.2, J2.2, U1.1 (EN), U1.2 (OUT)
GND: C1.1, C3.1, J1.1, J2.1, MODULE5.P$2 (GND_B), MODULE5.P$14 (GND_A), U1.4 (GND)
unnamed: D1.A, L1.P$2 (2), U1.5 (LX)
SERVO1: J1.3, MODULE5.P$5 (GPIO1)
SERVO2: J2.3, MODULE5.P$3 (GPIO2)
VBUS: C1.2, L1.P$1 (1), MODULE5.P$8 (VBUS)

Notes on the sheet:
0.2
Charles Pax
LabWiz Module

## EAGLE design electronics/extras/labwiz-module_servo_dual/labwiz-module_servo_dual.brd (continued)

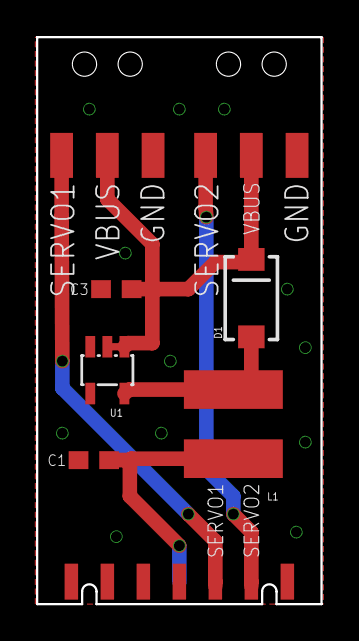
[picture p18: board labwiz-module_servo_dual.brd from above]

Board: 4 copper layers, 15.8 x 31.5 mm, 8 parts (0 on the bottom side), 6 nets.

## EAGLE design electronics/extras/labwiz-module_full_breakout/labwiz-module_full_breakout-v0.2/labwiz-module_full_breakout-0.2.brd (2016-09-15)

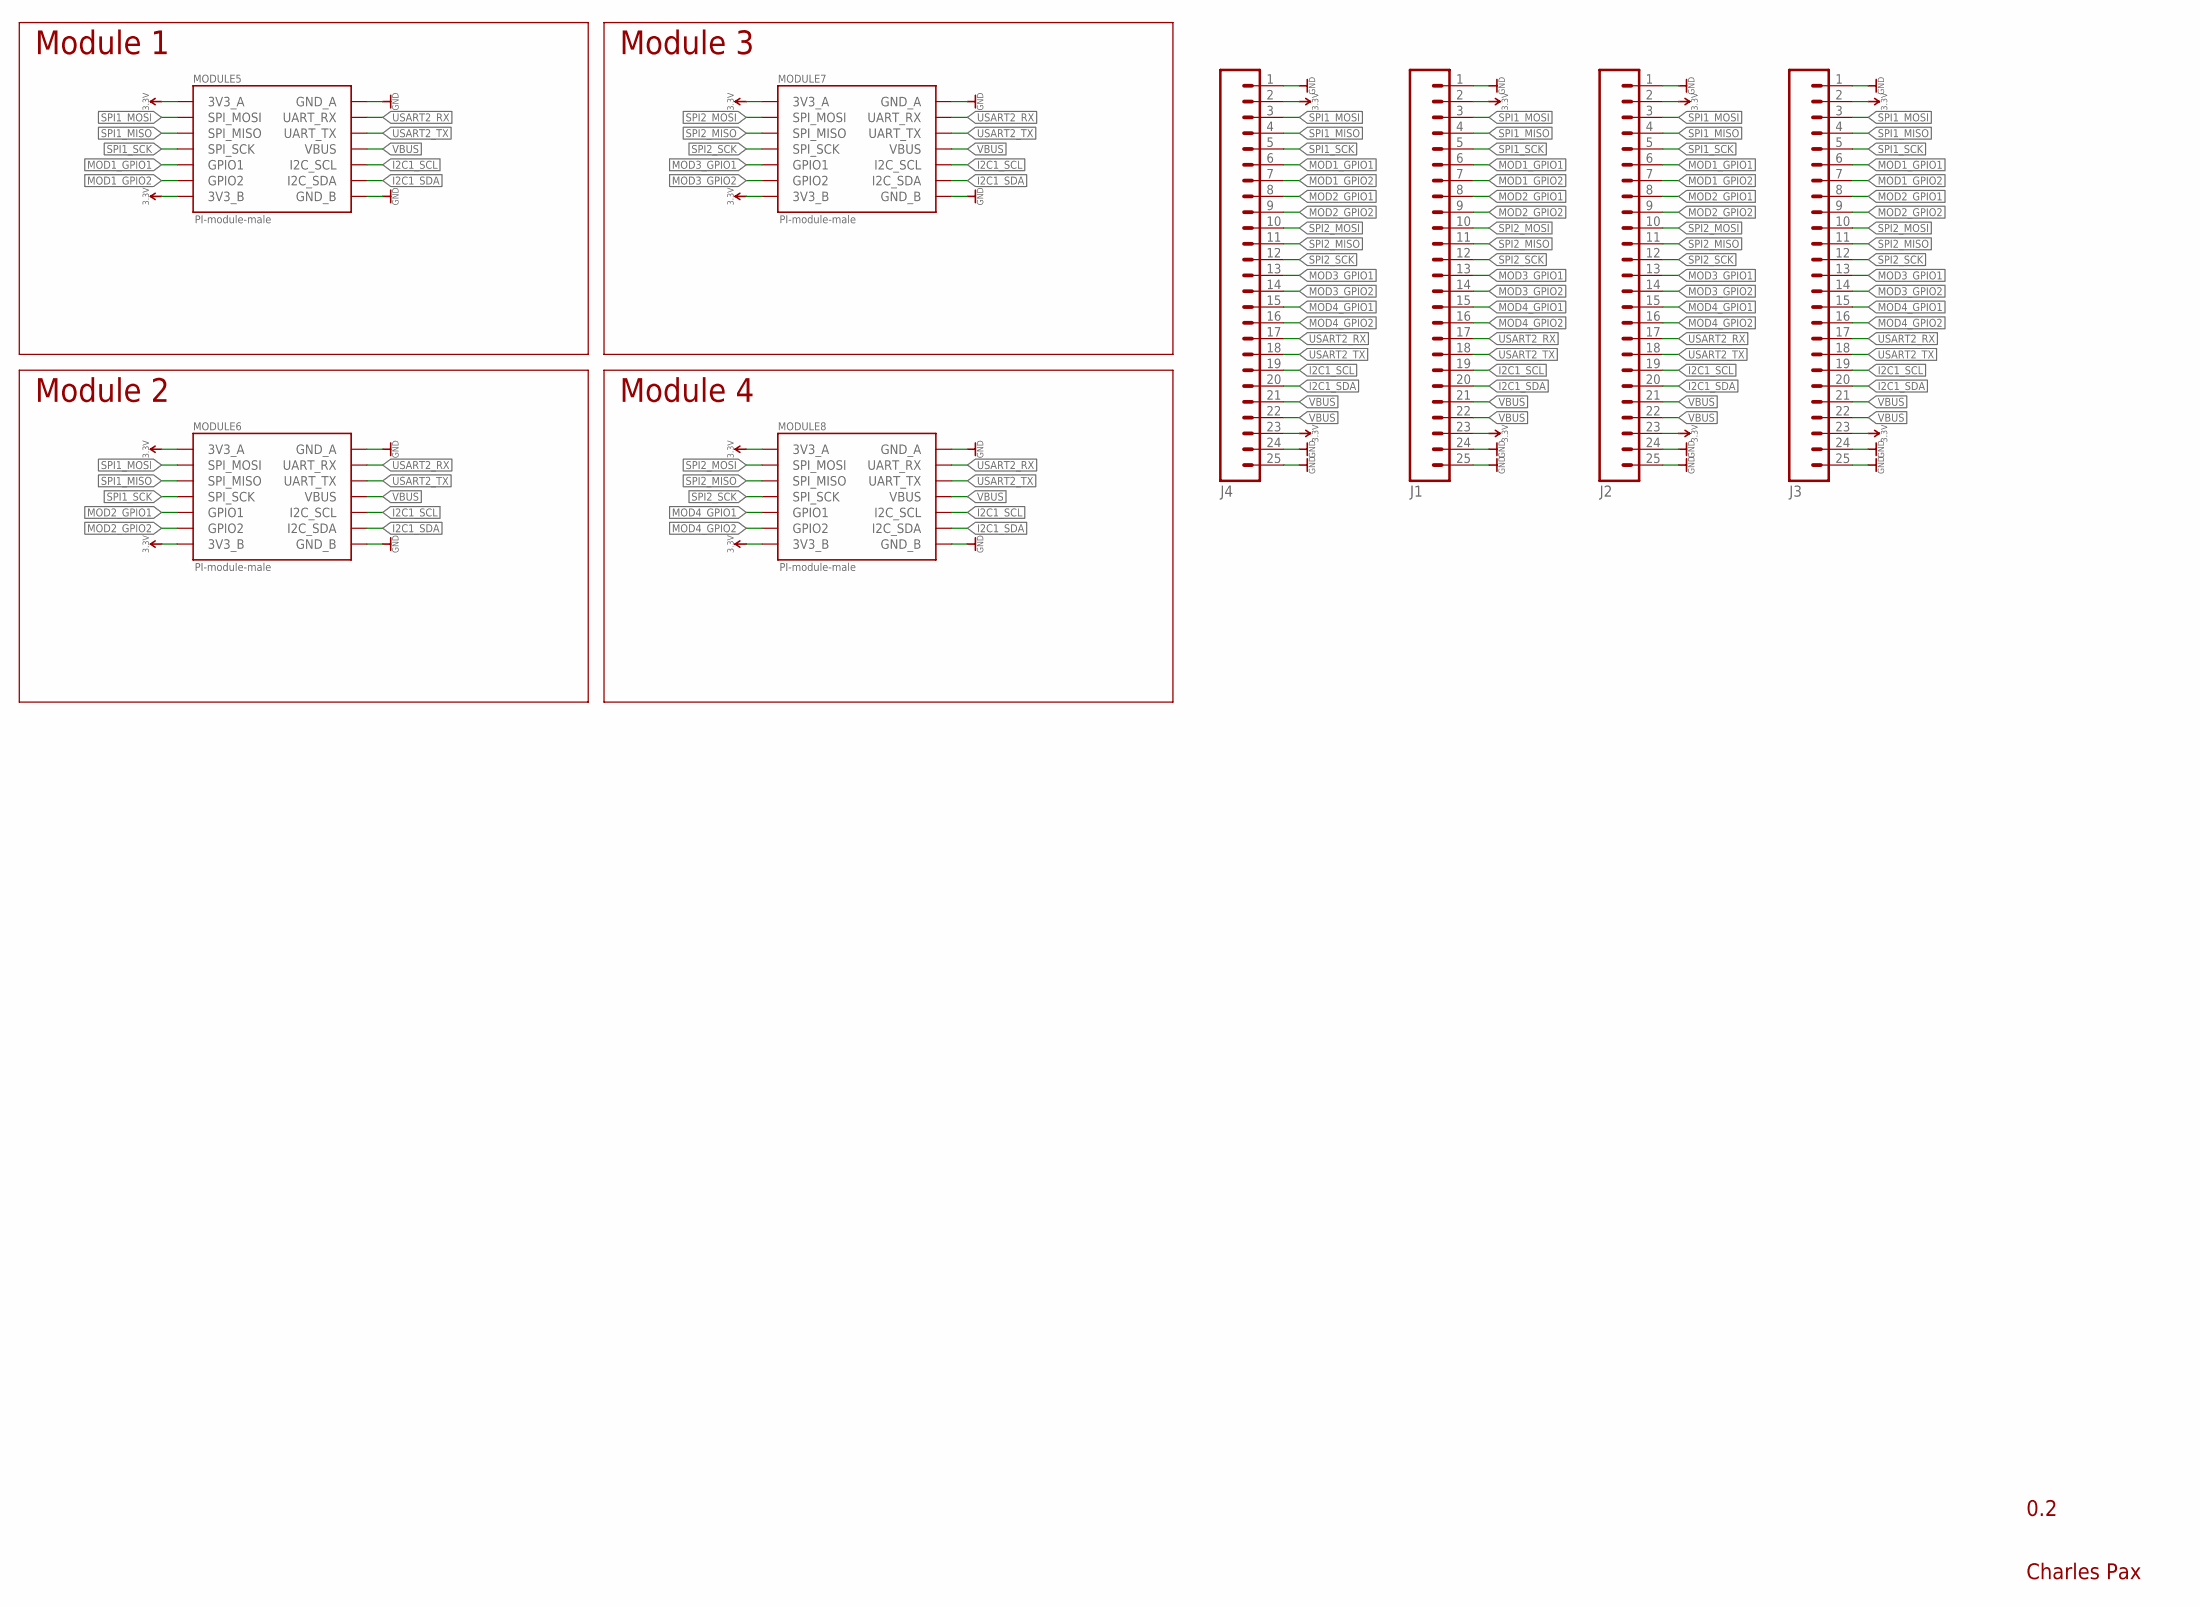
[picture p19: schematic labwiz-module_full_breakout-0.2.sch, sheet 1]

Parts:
J1, J2, J3, J4: M25PTH; 1X25
MODULE5, MODULE6, MODULE7, MODULE8: PI-module-male; M07X2_2MM_EDGE

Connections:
3.3V: J1.2, J1.23, J2.2, J2.23, J3.2, J3.23, J4.2, J4.23, MODULE5.P$1 (3V3_B), MODULE5.P$13 (3V3_A), MODULE6.P$1 (3V3_B), MODULE6.P$13 (3V3_A), MODULE7.P$1 (3V3_B), MODULE7.P$13 (3V3_A), MODULE8.P$1 (3V3_B), MODULE8.P$13 (3V3_A)
GND: J1.1, J1.24, J1.25, J2.1, J2.24, J2.25, J3.1, J3.24, J3.25, J4.1, J4.24, J4.25, MODULE5.P$2 (GND_B), MODULE5.P$14 (GND_A), MODULE6.P$2 (GND_B), MODULE6.P$14 (GND_A), MODULE7.P$2 (GND_B), MODULE7.P$14 (GND_A), MODULE8.P$2 (GND_B), MODULE8.P$14 (GND_A)
I2C1_SCL: J1.19, J2.19, J3.19, J4.19, MODULE5.P$6 (I2C_SCL), MODULE6.P$6 (I2C_SCL), MODULE7.P$6 (I2C_SCL), MODULE8.P$6 (I2C_SCL)
I2C1_SDA: J1.20, J2.20, J3.20, J4.20, MODULE5.P$4 (I2C_SDA), MODULE6.P$4 (I2C_SDA), MODULE7.P$4 (I2C_SDA), MODULE8.P$4 (I2C_SDA)
MOD1_GPIO1: J1.6, J2.6, J3.6, J4.6, MODULE5.P$5 (GPIO1)
MOD1_GPIO2: J1.7, J2.7, J3.7, J4.7, MODULE5.P$3 (GPIO2)
MOD2_GPIO1: J1.8, J2.8, J3.8, J4.8, MODULE6.P$5 (GPIO1)
MOD2_GPIO2: J1.9, J2.9, J3.9, J4.9, MODULE6.P$3 (GPIO2)
MOD3_GPIO1: J1.13, J2.13, J3.13, J4.13, MODULE7.P$5 (GPIO1)
MOD3_GPIO2: J1.14, J2.14, J3.14, J4.14, MODULE7.P$3 (GPIO2)
MOD4_GPIO1: J1.15, J2.15, J3.15, J4.15, MODULE8.P$5 (GPIO1)
MOD4_GPIO2: J1.16, J2.16, J3.16, J4.16, MODULE8.P$3 (GPIO2)
SPI1_MISO: J1.4, J2.4, J3.4, J4.4, MODULE5.P$9 (SPI_MISO), MODULE6.P$9 (SPI_MISO)
SPI1_MOSI: J1.3, J2.3, J3.3, J4.3, MODULE5.P$11 (SPI_MOSI), MODULE6.P$11 (SPI_MOSI)
SPI1_SCK: J1.5, J2.5, J3.5, J4.5, MODULE5.P$7 (SPI_SCK), MODULE6.P$7 (SPI_SCK)
SPI2_MISO: J1.11, J2.11, J3.11, J4.11, MODULE7.P$9 (SPI_MISO), MODULE8.P$9 (SPI_MISO)
SPI2_MOSI: J1.10, J2.10, J3.10, J4.10, MODULE7.P$11 (SPI_MOSI), MODULE8.P$11 (SPI_MOSI)
SPI2_SCK: J1.12, J2.12, J3.12, J4.12, MODULE7.P$7 (SPI_SCK), MODULE8.P$7 (SPI_SCK)
USART2_RX: J1.17, J2.17, J3.17, J4.17, MODULE5.P$12 (UART_RX), MODULE6.P$12 (UART_RX), MODULE7.P$12 (UART_RX), MODULE8.P$12 (UART_RX)
USART2_TX: J1.18, J2.18, J3.18, J4.18, MODULE5.P$10 (UART_TX), MODULE6.P$10 (UART_TX), MODULE7.P$10 (UART_TX), MODULE8.P$10 (UART_TX)
VBUS: J1.21, J1.22, J2.21, J2.22, J3.21, J3.22, J4.21, J4.22, MODULE5.P$8 (VBUS), MODULE6.P$8 (VBUS), MODULE7.P$8 (VBUS), MODULE8.P$8 (VBUS)

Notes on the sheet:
0.2
Charles Pax
Module 1
Module 2
Module 3
Module 4

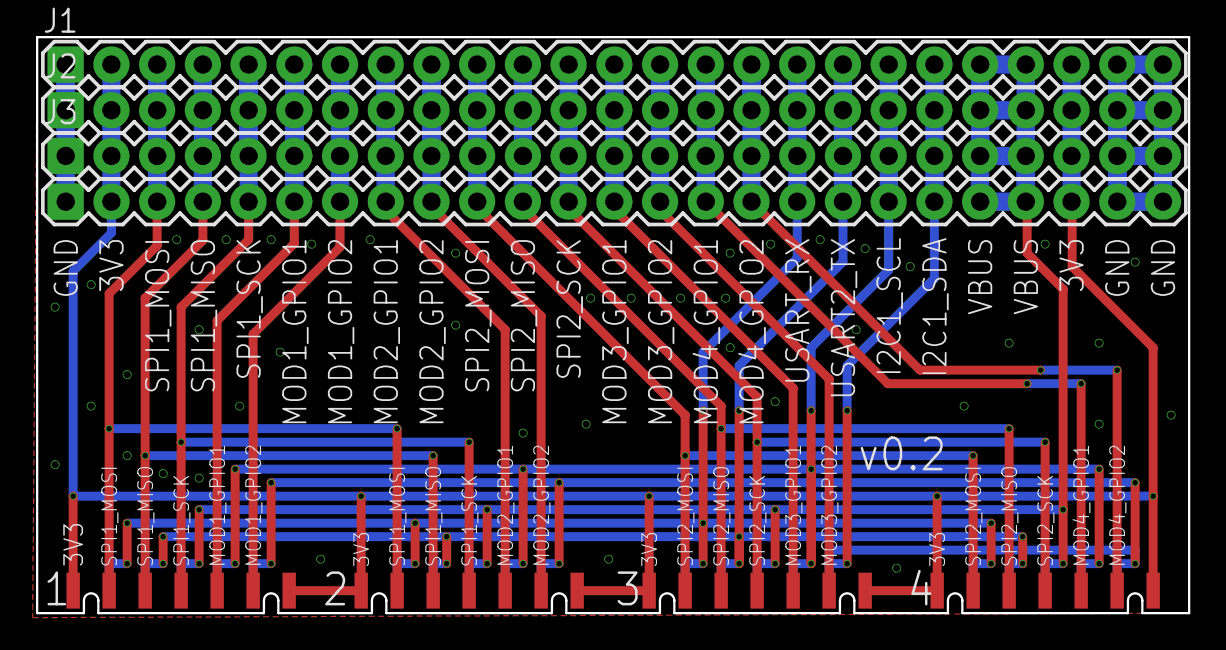
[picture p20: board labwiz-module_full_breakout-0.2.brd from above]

Board: 4 copper layers, 64.0 x 32.0 mm, 8 parts (0 on the bottom side), 21 nets.

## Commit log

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2016-02-26 Removed JTAG and ST-Link connectors. Added ARM Cortex Debug connector.
    [armwiz-board.brd, armwiz-board.sch]
2016-02-26 Readded the ST Link connection. I'll try to keep them both.
    [armwiz-board.brd, armwiz-board.sch]
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2016-02-27 Copied labels for all the pins that need to be connected to the MCU.
    [armwiz-board.brd, armwiz-board.sch]
2016-02-27 Added some traces. Just starting layout to see the general areas things should be. Then I can determine where the LCD and other items should be connected to the MCU.
    [armwiz-board.brd, armwiz-board.sch]
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2016-05-15 Basic layout done. Need to dome some details.
    [armwiz-board.brd, armwiz-board.sch]
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2016-05-16 Moved some traces. Have a little more room now.
    [armwiz-board.brd, armwiz-board.sch]
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2016-05-19 Added datasheets. This might be the final board layout and routing. Waiting on feedback.
    [armwiz-board.brd, armwiz-board.sch]
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2016-05-19 Fixed MEMS oscillator issue. Closes #3.
    [armwiz-board.brd, armwiz-board.sch]
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2016-05-20 Added a Black Magic debugger to the prototyping area. This is not in the schematic and can be deleted.
    [armwiz-board.brd]
2016-05-20 Added a directory for v0.1 design and gerber files.
    [CopperBottom.GBL, CopperTop.GTL, Dimension.GKO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]
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2016-05-21 Fixed an issue. Traces were going through the LCD cutout.
    [CopperBottom.GBL, CopperTop.GTL, Dimension.GKO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]
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2016-05-29 Changed to a metric layout. Moved to a 7x2 2.0mm module connector.
    [armwiz-board.brd, armwiz-board.sch]
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2016-05-30 Updated board with new Pax Instruments library parts.
    [armwiz-board.brd, armwiz-board.sch]
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2016-07-14 Changed serial pins on Cortex header. Added SWO to Cortex header. Added TODO notes to schematic.
    [armwiz-board.brd, armwiz-board.sch]
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2016-07-14 Connected BOOT0 to SW_D. SW_D is default low voltage.
    [armwiz-board.brd, armwiz-board.sch]
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2016-07-21 Added Seeed Studio Grove adapter modules. Now we can develop with Grove modules rather than design our own.
    [armwiz-board.brd, armwiz-board.sch]
2016-07-22 Renamed files from armwiz to labwiz. Moved old version files to versions folder.
    [CopperBottom.GBL, CopperTop.GTL, Dimension.GKO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]
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2016-08-08 Added pullup to RESET.
    [labwiz-board.brd, labwiz-board.sch]
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2016-08-08 Added BOOT0 jumper label. Added 100 nF caps to debounce switches.
    [labwiz-board.brd, labwiz-board.sch]
2016-08-08 Swapped 8 MHz crystal for a commong footprint in HQB.
    [labwiz-board.brd, labwiz-board.sch]
2016-08-08 Removed SWD pogo pads. Use the Cortex header or or pogo pins on the header pads.
    [labwiz-board.brd, labwiz-board.sch]
2016-08-08 Removed SD_DETECT to use for BATT_STAT. Ran VBAT across board via 3V3 layer.
    [labwiz-board.brd, labwiz-board.sch]
2016-08-15 Added power cap to WIFI. Added pulldown to WIFI_EN.
    [labwiz-board.brd, labwiz-board.sch]
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2016-08-15 Changed CAM file for larger clearance. Rerouted some items. CAN transceiver installed. Added component names to silkscreen.
    [labwiz-board.brd, labwiz-board.sch]
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2016-08-20 Removed all modules in labwiz board. The PCB house charges more than twice as much for a panelized design. This will also keep the BoM clean.
    [labwiz-board.brd, labwiz-board.sch]
2016-08-20 Fixed silkscreen on module connectors.
    [labwiz-board.brd, labwiz-board.sch]
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2016-08-20 Made board files for each module. Ordered boards.
    [labwiz-module_full_breakout.brd, labwiz-module_full_breakout.sch, labwiz-module_pH.brd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]
2016-08-21 Widened the full module to 66 mm. Added a T420 module, which is just the sensor parts from a T400.
    [labwiz-board.brd, labwiz-module_t420.brd, labwiz-module_t420.sch]
2016-08-22 All caps and resistors are now based on the updated Pax Instruments library.
    [labwiz-board.brd, labwiz-board.sch]
2016-08-22 Modivied power capacitor values. See issue 45.
    [labwiz-board.brd, labwiz-board.sch]
2016-08-22 Added 1.5k pullup resistors to all i2c lines.
    [labwiz-board.brd, labwiz-board.sch]
2016-08-22 Updated components. CAN pin names are correct.
    [labwiz-board.brd, labwiz-board.sch]
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2016-09-08 Switched some pins. Routed a bunch of the board.
    [labwiz-board.brd, labwiz-board.sch]
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2016-09-13 Minor changes after design review. Will begin generating new gerbrs.
    [labwiz-board.brd, labwiz-board.sch, labwiz-module_full_breakout.brd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]
2016-09-13 Added gerbers and PDF for updated v0.3 board.
    [labwiz-board-0.3.brd, labwiz-board-0.3.sch]
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2016-09-14 Changed the connector locating slots from a milled slot to simply using the board outline. Now passes HQPCB test.
    [labwiz-board-0.3.brd, labwiz-board-0.3.sch, labwiz-board.brd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]
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2016-09-15 Fixed VBUS issues on pH module.
    [labwiz-module_pH-0.2.brd, labwiz-module_pH-0.2.sch, labwiz-module_pH.brd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]
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2017-01-22 Swapped the net names for SW_D and SW_E. The physical locations were swapped on the v0.3 board.
    [labwiz-board.brd, labwiz-board.sch]
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2017-01-22 Swapped WIFI_EN with SW_A to avoid interrupt sharing.
    [labwiz-board.brd, labwiz-board.sch, labwiz-pin-map.ods]
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2017-01-23 Added transient voltage suppressor to USB_VCC. Closes #59.
    [labwiz-board.brd, labwiz-board.sch]
2017-01-23 Added 100k pullup resistors to the USART1 lines. Closes #26.
    [labwiz-board.brd, labwiz-board.sch]
2017-01-23 Added circuitry to alow PC1 to put BOOT0 into bootloader mode. I also had to switch around SW_E from normally high to normally low.
    [labwiz-board.brd, labwiz-board.sch]
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2017-01-24 Added solder jumper to select between USB high-speed/full-speed and USB low speed. Closes #55
    [labwiz-board.brd, labwiz-board.sch]
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2017-01-24 Added doc layer pin 1 indicator on the debug header in library. Closes #90
    [labwiz-board.brd, labwiz-board.sch]
2017-01-24 Changed board top edge; extended 24 mil, created protrusion to lock in with top panel of enclosure. Closes #97.
    [labwiz-board.brd]
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2017-01-25 Added pin interrupt info to a page on the pin-map spreadsheet. Changed RTC battery to a CR1025. CR1025 connections still need to be routed.
    [labwiz-board.brd, labwiz-board.sch, labwiz-pin-map.ods]
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2017-01-27 PC4 is now VBUS_DETECT. Removed unnecessary USB data series resistors. Closes #76.'
    [labwiz-board.brd, labwiz-board.sch, labwiz-pin-map.ods]
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

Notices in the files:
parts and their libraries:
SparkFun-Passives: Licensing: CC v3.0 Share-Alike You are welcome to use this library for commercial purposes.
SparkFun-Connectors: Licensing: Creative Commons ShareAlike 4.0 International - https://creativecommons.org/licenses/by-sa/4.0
